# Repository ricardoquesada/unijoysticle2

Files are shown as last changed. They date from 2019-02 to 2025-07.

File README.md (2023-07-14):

# Unijoysticle™ 2





Unijoysticle is a device that allows you to use modern Bluetooth gamepads and mice in retro computers.

Unijoysticle 2 models:

| | 800XL | C64 | A500 | 2+ | 2 |
| --- | --- | --- | --- | --- | --- |
| Top | uni2800xl_photo_front | uni2c64_photo_front | uni2a500_photo_front | uni2plus_photo_front | uni2_photo_front |
| Bottom | uni2800xl_photo_back | uni2c64_photo_back | uni2a500_photo_back | uni2plus_photo_back | uni2_photo_back |
| Release date | July 2023 | March 2023 | July 2022 | October 2021 | April 2019 |
| Best for | Atari 800XL / 600XL | C64 / C128 | Amiga | - | - |
| Good for | Atari 400 / Amiga / AtariST | Amiga / AtariST | C64 / AtariST / Atari 8bit  | C64 / Amiga / AtariST / Atari 8bit | C64 / Amiga / AtariST / Atari 8bit |
| Status | Active / Supported | Active / Supported | Active / Supported | Discontinued / Supported | Discontinued / Supported |
| Amiga / AtariST mouse support | Yes | No | Yes | Yes | Yes |
| Amiga / AtariST 2nd & 3rd button support | No | No | Yes | Yes | Only in Port 1 |
| Atari 8-bit 2nd & 3rd button support (5) | Yes | No | No | No | No |
| C64 2nd & 3rd button support | No | Yes | No | No | No |
| C64 4th and 5th button support (4) | No | Yes | No | No | No |
| C64 Paddle support | No | Might (1) | No | No | No |
| Rumble (2) | No | Yes | No | No | No |
| Fits | 800XL / 600XL | C64 / C128 | Amiga 500 / 1200 | C64 / C128 | C64 / C128 |
| Buttons | Reset, Mode, Swap | Reset, Mode, Swap | Reset, Mode,  Swap | Reset, Mode | Reset, Mode |
| LEDs | Port 1, 2, Bluetooth, Power | Port 1, 2, Bluetooth, Power | Port 1, 2, Bluetooth, Power | Port 1, 2, Power | Port 1, 2, Power |
| Filter noise ([Issue #17][issue_17]) | Yes | Yes | Yes | Yes | No |
| Case friendly | Yes | Yes | Yes | Yes | No |
| Easy to solder | No. Most components are SMD | No. Most components are SMD | No. Most components are SMD | No. Most components are SMD | Yes. All components are through-hole  |
| Self-powered | Yes | Yes | Yes | Yes | Yes, can be turned on/off with switch |
| External power | USB | USB | USB | USB | Both USB and Barrel Jack 5V+ |
| Total Size (mm) | 65 x 75 x 13.6 | 72 x 68 x 13.6 | 67 x 72 x 13.6 | 64 x 64 x 13.6 | 63 x 66 x 17 |
| PCB Size (mm) | 53 x 72 x 1.6 | 63 x 60 x 1.6 | 52 x 67 x 1.6 | 49 x 62 x 1.6 | 46 x 57 x 1.6 |
| Weight (gr) | 27 | 27.1 | 25.6 | 24 | 37 |
| Current (mA) | ~96 | ~96 | ~96 | ~96 | ~100 |
| USB connector | Micro USB | Micro USB | Micro USB | Micro USB | Micro USB |

Notes:

- (1): Hardware physically connected, but firmware is still WIP.
- (2): Some C64 games can turn on/off rumble on gamepads. See: [Rambo], and [Lemans] ([video][rumble_video])
- (3): Right and Middle mouse buttons not supported in C64.
- (4): Based on [CrystalCT 5 buttons joystick][crystalct/5plusbuttonsJoystick] ([video][5_buttons_video])
- (5): Based on [Ascrnet Joy 2B+][atari_joy2bplus]

Unijoysticle 2 allows you to use modern Bluetooth gamepads. E.g. DualSense controller in retro computers like the Commodore 64, Amiga and AtariST.

It also supports mice (for Amiga / AtariST only).

[issue_17]: https://gitlab.com/ricardoquesada/unijoysticle2/-/issues/17
[uni2_photo_front]: https://lh3.googleusercontent.com/pw/AM-JKLUphquTBg9JoV-L7wuMtze_aKIJ8LvfokTakuBKSVFClziLWCViggcrlNZtqGUMgv6u6yYpZ_RuE2jdGSn3Q0oYl0jOQzzGcutRt-JiMjLZY_oAvK4LehrawNj_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
[uni2_photo_back]: https://lh3.googleusercontent.com/pw/AM-JKLXnMbJt7A55lUrtmiuKj4As98He7ZVi6YuPKg8N1sGbw1w5d5TtC8B-ilfoqC5QCKcZG8MFkmHNj5HgVbP8fdHhMBPx2CLgyRhaRmohx0SWF-_wZ57WYCfo7RlH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
[uni2plus_photo_front]: https://lh3.googleusercontent.com/pw/AM-JKLWV2Zo912VtOfuM71AluanNXGwVQiAehNEiQ1VL3L7SkWDl-9k0fA6tfza9QpGL52petBfFFFHMb8rh_ybSj17LOQA70IycMDQw6AVqlN8Jp4HDWT8sWcXHIPEQ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
[uni2plus_photo_back]: https://lh3.googleusercontent.com/pw/AM-JKLWs_G63eJRX8WuVVRoKKur8UQ-VcWTNbmkjFumwZYvDRhgjqamVa-X9CROAnoPyK3sHDmfwtqAtJiI1DHiwlINBPCgiEY4yWFYWl8SlHA_QOG7LmVKuOKy1UQa-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
[uni2a500_photo_front]: https://lh3.googleusercontent.com/pw/AM-JKLU1BbKnbuLE7Oa_VOY3AnBjYwNVcAPKJcmYa7WUnCK5gMM1bHZyK3lTZ1Mo0NtS30ogeeSqxySx3Qi2ux3AGOlocQnQe9a87NoiKz5tnmHV_IGf3hPln0qsr8t5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
[uni2a500_photo_back]: https://lh3.googleusercontent.com/pw/AM-JKLXMUngI6ctahY5clP-76UBjUem9L4Eehj4GFsEwUJwtZ3-MuZCV2nOsxiN3Go1PKvoc9sJbLRY8hCZ9TcV4cq5AtcAtscdjH1LiNzltFSgQY4IQEwSiPHfvhjhZ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
[bluepad32-fw]: https://gitlab.com/ricardoquesada/bluepad32
[uni2c64_photo_front]: https://lh3.googleusercontent.com/pw/AMWts8AzoDnIOIiM-50UpjAqY8OgdsM6pzM3BuYWb2ZOg4K_o4TxygtSjuZvrKI92lrl4Qqf8sLT6PtLYsXzDbragTDgoeX4yTpymqoc450FiyjiBT1YHxRbLBtGWgUO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
[uni2c64_photo_back]: https://lh3.googleusercontent.com/pw/AMWts8C_vxauz3FAOv8NGAh64LGTExHwCj0N0bX73xsWIeDyR3efFPPUQb3JJQK5S8Qcm9B8bx3r_yio6WWAML1si4u8E9FejXP9DL8vxSCg_TR7rLi5aPiwisQaIptN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
[uni2800xl_photo_front]: https://lh3.googleusercontent.com/pw/AIL4fc9fcgdY3Gka6iSZmyUlBTA1Q9ABujo-9v_4qE85St2GdW-2TBzzLNx-pc25o0rFloL0ghWZDDVW_kGWpQjcXaP-SJf9NWPnNw-2jpc_8tcVKp8gzLH7fxnFd7DB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
[uni2800xl_photo_back]: https://lh3.googleusercontent.com/pw/AIL4fc9PNSKKiA7PHsUTLKXGF1O9ywK-qLHS0nw2-Y6FxWQcgmtZJjajQh9Uch0aqZ2Pw-grH_Vg05IKYZilissF6nxUJPDszew0ouzGu91golm1RYJJpPS0CDANAfk3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
[Rambo]: https://gitlab.com/ricardoquesada/c64-rambo
[Lemans]: https://gitlab.com/ricardoquesada/c64-lemans
[crystalct/5plusbuttonsJoystick]: https://github.com/crystalct/5plusbuttonsJoystick/
[5_buttons_video]: https://www.youtube.com/watch?v=9Em_kUAHEuA
[rumble_video]: https://www.youtube.com/watch?v=vCj45OX43JE
[atari_joy2bplus]: https://github.com/ascrnet/Joy2Bplus
[uni_logo]: https://lh3.googleusercontent.com/pw/AIL4fc_k4CtBs9deXjMuCJOotXbNoRwON1CdYCMshG41PpEf2v-7xc2IcIPFvYCOFeLriESlXEJhm5nK72st8v1E04ZzyqawW8x5DPJt2ug6ZzhGXdnJvasD577CX1Yb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

## Basic functionality

One Bluetooth gamepad controls one joystick.
You need two gamepads to control the two joysticks.

Basic mode

The mappings are:

- D-pad/joypad: controls up/down/left/right.
- Button A / Cross: fire button
- Button B / Circle: "up"  (ideal for platform games).
- Button X / Square: 2nd button (Amiga / AtariST only)
- Button Y / Triangle: 3rd button (Amiga / AtariST only)
- Button shoulder-right: autofire.
- System button swaps between Joystick 1 and 2

## Twin Stick functionality (AKA Enhanced mode)

Twin Stick mode

When in "Enhanced mode", you control the two joysticks with only one gamepad.
The mappings are:

- Left joypad / d-pad: control Joystick 2 movements.
- Right joypad: control Joystick 1 movements.
- Button A / Cross: fire for Joystick 2
- Button B / Circle: fire for Joystick 1
- Button X / Square: 2nd button for Joystick 2
- Button Y / Triangle: 2nd button for Joystick 1
- Button Shoulder Left: auto-fire for Joystick 2
- Button Shoulder Right: auto-fire for Joystick 1

This mode is ideal for games like [Commando][2] or [1942][3] since it allows you
throw grenades / roll by pressing Button B.

## Supported controllers

### Gamepads
Supported gamepads

- Sony DualSense
- Sony DUALSHOCK 4
- Sony DUALSHOCK 3
- Nintendo Switch Pro
- Nintendo JoyCons
- Nintendo Wii U
- Nintendo Wii + accesories
- Xbox Wireless controller (model 1708)
- Steam
- Stadia
- Android gamepads
- PC/Windows gamepads
- 8BitDo controllers
- iCade
- And more

See:

* [Supported gamepads][gamepads]
* [Supported mice][mice]

[gamepads]: https://gitlab.com/ricardoquesada/unijoysticle2/blob/master/docs/supported_gamepads.md
[mice]: https://gitlab.com/ricardoquesada/bluepad32/blob/develop/docs/supported_mice.md

### Mice

Supported mice

Mouse emulation is only available for **Amiga and Atari ST** computers.

For a detailed list of supported mice, see here:

* [Supported mice][supported_mice]

[supported_mice]:  https://gitlab.com/ricardoquesada/bluepad32/blob/develop/docs/supported_mice.md

## Order info

If you are looking for ready-to-use boards, you can purchase one from here:



Looking for a remix and/or 3rd party vendors. Go here: [SELLING_DEVICES.md][selling_devices]

[selling_devices]: SELLING_DEVICES.md

## More Info

- [Users guide][users_guide]
- [Discord][discord]
- [Email group][email_group]

[users_guide]: https://gitlab.com/ricardoquesada/unijoysticle2/blob/master/docs/user_guide.md
[discord]: https://discord.gg/r5aMn6Cw5q
[email_group]: https://groups.google.com/forum/#!forum/unijoysticle

[1]: https://retro.moe/unijoysticle
[2]: https://csdb.dk/release/?id=137173
[3]: https://csdb.dk/release/?id=38140

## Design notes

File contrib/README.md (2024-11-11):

Contributions by the community.

Kopsec C64:
 - c64/ Unijoysticle 2 - REV E / REV H
 - c64/ Unijoysticle 2 - Rev A1, based on new Unijoysticle C64 model

Eduardo Casino:
 - C16/Plus4 board

Hyvax:
  - NeoGeo board

Aakko:
  - Case for Unijosyticle 2+

Goblin Hero:
  - Case for Unijoysticle 2 A500

Albert Herranz:
  - MSX boards
    * [msx-joyblue-v1](https://github.com/herraa1/msx-joyblue-v1)
    * [msx-joyblue-v2](https://github.com/herraa1/msx-joyblue-v2)

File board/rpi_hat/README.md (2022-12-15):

# Unijoysticle 2 Test HAT

A Raspeberry Pi HAT for Unijoysticle automated testing.

* Board files are in this folder.
* Tests are in https://gitlab.com/ricardoquesada/unijoysticle2/-/tree/main/tests/functional

full

pcb

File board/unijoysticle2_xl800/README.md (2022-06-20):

# Unijoysticle™ 2 A500

uni2_a500_photo

Unijoysticle 2 A500 is device that lets you use modern Gamepad and Mice in retro computers like the Amiga.

Unijoysticle 2 is open source / open hardware. See [license][license] for details.

[uni2_a500_photo]: https://lh3.googleusercontent.com/pw/AM-JKLXEB6NQ-lr54G6cPEVQJ9i1OGR0XWLVYsjCs4Sc_883w-gYvwnUOPlH2wnzM0ibH48Y6QGAAIRO9pnfTxDsdQqY7JHBKzJPzOOY8Cin6t9sSjHvx94k1VZLdTh1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 

## Schematic

* [Unijoysticle 2 A500 schematic](../../docs/schematic_unijoysticle2_a500.pdf)

## Layout

Layout files are in Kicad 6 format in this same folder.

## BOM

| Item | Qty | Reference(s) | Value | LibPart | Footprint | Datasheet |
| ---- | --- | --- | ----- | --- | --- | --- |
| 1 |7|C1,C2,C4,C9,C11,C12,C13|.1uF|Device:C_Small|Capacitor_SMD:C_0805_2012Metric_Pad1.18x1.45mm_HandSolder|~|
| 2 |1|C3|10uF|Device:C_Small|Capacitor_SMD:C_0805_2012Metric_Pad1.18x1.45mm_HandSolder|~|
| 3 |3|C5, C7, C8 |22uF|Device:C_Small|Capacitor_SMD:C_0805_2012Metric_Pad1.18x1.45mm_HandSolder|~|
| 4 |1|C6|1500uF|Device:C_Polarized_Small|Capacitor_SMD:CP_Elec_10x10|~|
| 5 |1|C10|1uF|Device:C_Small|Capacitor_SMD:C_0805_2012Metric_Pad1.18x1.45mm_HandSolder|~|
| 6 |1|D1|PWR|Device:LED|LED_SMD:LED_0805_2012Metric_Pad1.15x1.40mm_HandSolder|~|
| 7 |2|D2, D3|1N5819|Device:D_Schottky_Small|Diode_SMD:D_SOD-123|~|
| 8 |1|D4|BLUE|Device:LED|LED_SMD:LED_0805_2012Metric_Pad1.15x1.40mm_HandSolder|~|
| 9 |1|D5|GREEN|Device:LED|LED_SMD:LED_0805_2012Metric_Pad1.15x1.40mm_HandSolder|~|
| 10 |1|D6|RED|Device:LED|LED_SMD:LED_0805_2012Metric_Pad1.15x1.40mm_HandSolder|~|
| 11 |2|H1, H2|MountingHole_Pad|Mechanical:MountingHole_Pad|MountingHole:MountingHole_3.2mm_M3_Pad_Via|~|
| 12 |1|J1|USB_B_Micro|Connector:USB_B_Micro|Connector_USB:USB_Micro-B_Amphenol_10118194_Horizontal|~|
| 13 |1|J2|PORT JOY #1|Connector:DB9_Female|Connector_Dsub:DSUB-9_Female_Horizontal_P2.77x2.54mm_EdgePinOffset9.40mm| ~ |
| 14 |1|J3|PORT JOY #2|Connector:DB9_Female|Connector_Dsub:DSUB-9_Female_Horizontal_P2.77x2.54mm_EdgePinOffset9.40mm| ~ |
| 15 |1|JP1|SolderJumper_1_Open, Jumper:SolderJumper_2_Open|Jumper:SolderJumper-2_P1.3mm_Open_Pad1.0x1.5mm| ~ |
| 16 |2|Q1, Q2|S8050|Device:Q_NPN_BEC|Package_TO_SOT_SMD:SOT-23| ~ |
| 17 |3|R1, R10, R11|10K|Device:R|Resistor_SMD:R_0805_2012Metric_Pad1.20x1.40mm_HandSolder| ~ |
| 18 |5|R2, R7, R8, R9, R12|3.3K|Device:R|Resistor_SMD:R_0805_2012Metric_Pad1.20x1.40mm_HandSolder| ~ |
| 19 |2|R3, R4|10K|Device:R_Small|Resistor_SMD:R_0805_2012Metric_Pad1.20x1.40mm_HandSolder| ~ |
| 20 |2|R5, R6|1K|Device:R_Small|Resistor_SMD:R_0805_2012Metric_Pad1.20x1.40mm_HandSolder| ~ |
| 21 |3|R13, R14, R15|0|Device:R|Resistor_SMD:R_0805_2012Metric_Pad1.20x1.40mm_HandSolder| ~ |
| 22 |1|SW1|RESET|Switch:SW_Push|Button_Switch_THT:SW_Tactile_SPST_Angled_PTS645Vx39-2LFS| ~ |
| 23 |1|SW2|BOOT|Switch:SW_Push|Unijoysticle:SW_Push_1P1T_NO_5.1x5.1mm| ~ |
| 24 |1|SW3|MODE|Switch:SW_Push|Button_Switch_THT:SW_Tactile_SPST_Angled_PTS645Vx39-2LFS| ~ |
| 25 |1|SW4|SWAP|Switch:SW_Push|Button_Switch_THT:SW_Tactile_SPST_Angled_PTS645Vx39-2LFS| ~ |
| 26 |1|U1|ESP32-WROOM-32E|RF_Module:ESP32-WROOM-32D|RF_Module:ESP32-WROOM-32 | https://www.espressif.com/sites/default/files/documentation/esp32-wroom-32d_esp32-wroom-32u_datasheet_en.pdf |
| 27 |1|U2|AMS1117-3.3|Regulator_Linear:AMS1117-3.3|Package_TO_SOT_SMD:SOT-223-3_TabPin2|http://www.advanced-monolithic.com/pdf/ds1117.pdf |
| 28 |1|U3|CH340C|Interface_USB:CH340C|Package_SO:SOIC-16_3.9x9.9mm_P1.27mm|https://datasheet.lcsc.com/szlcsc/Jiangsu-Qin-Heng-CH340C_C84681.pdf |
| 29 |3| U4, U5, U6|74HC05|74xx:74LS05|Package_SO:SOIC-14_3.9x8.7mm_P1.27mm|http://www.ti.com/lit/gpn/sn74LS05 |

## Order info

If you are looking for ready-to-use boards, you can purchase one from here:



[license]: ../../LICENSE

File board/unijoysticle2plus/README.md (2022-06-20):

# Unijoysticle™ 2+

uni2_plus_photo

Unijoysticle 2+ is device that lets you use modern gamepads and Mice in retro computers like the Commodore 64.

Unijoysticle 2 is open source / open hardware. See [license][license] for details.

[uni2_plus_photo]: https://lh3.googleusercontent.com/pw/AM-JKLVeTZLBOCy4GmrG5N-WiRIcqoxLdsVXSN-77reS92gn7xxmZy-JuE_XeXgwSSPaUBYa2qaaw5RvZbzlkHdjDxal2p_WkKIm9RnzD6qeqV_u7j_3sRJOkm35EO5J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

## Schematic

* [Unijoysticle 2+ schematic](../../docs/schematic_unijoysticle2plus.pdf)

## Layout

Layout files are in Kicad 5 format in this same folder.

## BOM

| Item | Qty | Reference(s) | Value | LibPart | Footprint | Datasheet |
| ---- | --- | --- | ----- | --- | --- | --- |
|1|7|C1, C2, C3, C5, C11, C12, C13|.1uF|Device:C_Small|Capacitor_SMD:C_0805_2012Metric_Pad1.18x1.45mm_HandSolder|~|
|2|1|C4|10uF|Device:C_Small|Capacitor_SMD:C_0805_2012Metric_Pad1.18x1.45mm_HandSolder|~|
|3|3|C6, C8, C9|22uF|Device:C_Small|Capacitor_SMD:C_0805_2012Metric_Pad1.18x1.45mm_HandSolder|~|
|4|1|C7|1000uF|unijoysticle2plus-rescue:CP_Small-Device|Capacitor_SMD:CP_Elec_10x10||
|5|1|C10|1uF|Device:C_Small|Capacitor_SMD:C_0805_2012Metric_Pad1.18x1.45mm_HandSolder|~|
|6|1|D1|BLUE|Device:LED|LED_SMD:LED_0805_2012Metric_Pad1.15x1.40mm_HandSolder|~|
|7|1|D2|GREEN|Device:LED|LED_SMD:LED_0805_2012Metric_Pad1.15x1.40mm_HandSolder|~|
|8|1|D3|RED|Device:LED|LED_SMD:LED_0805_2012Metric_Pad1.15x1.40mm_HandSolder|~|
|9|2|D4, D5|1N5819|Device:D_Schottky_Small|Diode_SMD:D_SOD-123|~|
|10|2|H1, H2|MountingHole_Pad|Mechanical:MountingHole_Pad|MountingHole:MountingHole_3.2mm_M3_Pad_Via|~|
|11|2|J1, J2|DB9_Female|Connector:DB9_Female|Connector_Dsub:DSUB-9_Female_Horizontal_P2.77x2.54mm_EdgePinOffset9.40mm| ~|
|12|1|J3|USB_B_Micro|Connector:USB_B_Micro|Connector_USB:USB_Micro-B_Amphenol_10118194_Horizontal|~|
|13|2|Q1, Q2|S8050|Device:Q_NPN_BEC|Package_TO_SOT_SMD:SOT-23|~|
|14|1|R1|10k|Device:R|Resistor_SMD:R_0805_2012Metric_Pad1.20x1.40mm_HandSolder|~|
|15|3|R2, R3, R4|1.5k|Device:R|Resistor_SMD:R_0805_2012Metric_Pad1.20x1.40mm_HandSolder|~|
|16|2|R5, R6|1k|Device:R_Small|Resistor_SMD:R_0805_2012Metric_Pad1.20x1.40mm_HandSolder|~|
|17|2|R7, R8|10k|Device:R_Small|Resistor_SMD:R_0805_2012Metric_Pad1.20x1.40mm_HandSolder|~|
|18|1|SW1|RESET|Switch:SW_Push|Button_Switch_THT:SW_Tactile_SPST_Angled_PTS645Vx39-2LFS|~|
|19|1|SW2|JOY SWAP|Switch:SW_Push|Button_Switch_THT:SW_Tactile_SPST_Angled_PTS645Vx39-2LFS|~|
|20|1|SW3|BOOT|Switch:SW_Push|Unijoysticle:SW_Push_1P1T_NO_5.1x5.1mm|~|
|21|3|U1, U2, U3|74HC05|74xx:74LS05|Package_SO:SOIC-14_3.9x8.7mm_P1.27mm|http://www.ti.com/lit/gpn/sn74LS05|
|22|1|U4|ESP32-WROOM-32E|RF_Module:ESP32-WROOM-32D|RF_Module:ESP32-WROOM-32|https://www.espressif.com/sites/default/files/documentation/esp32-wroom-32d_esp32-wroom-32u_datasheet_en.pdf|
|23|1|U5|AMS1117-3.3|Regulator_Linear:AMS1117-3.3|Package_TO_SOT_SMD:SOT-223-3_TabPin2|http://www.advanced-monolithic.com/pdf/ds1117.pdf|
|24|1|U6|CH340C|Interface_USB:CH340C|Package_SO:SOIC-16_3.9x9.9mm_P1.27mm|https://datasheet.lcsc.com/szlcsc/Jiangsu-Qin-Heng-CH340C_C84681.pdf|

## Order info

If you are looking for ready-to-use boards, you can purchase one from here:



[license]: ../../LICENSE

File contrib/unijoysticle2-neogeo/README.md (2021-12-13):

# Unijoysticle2 for NeoGeo

## Projects

### Unijoysticle2 for NeoGeo

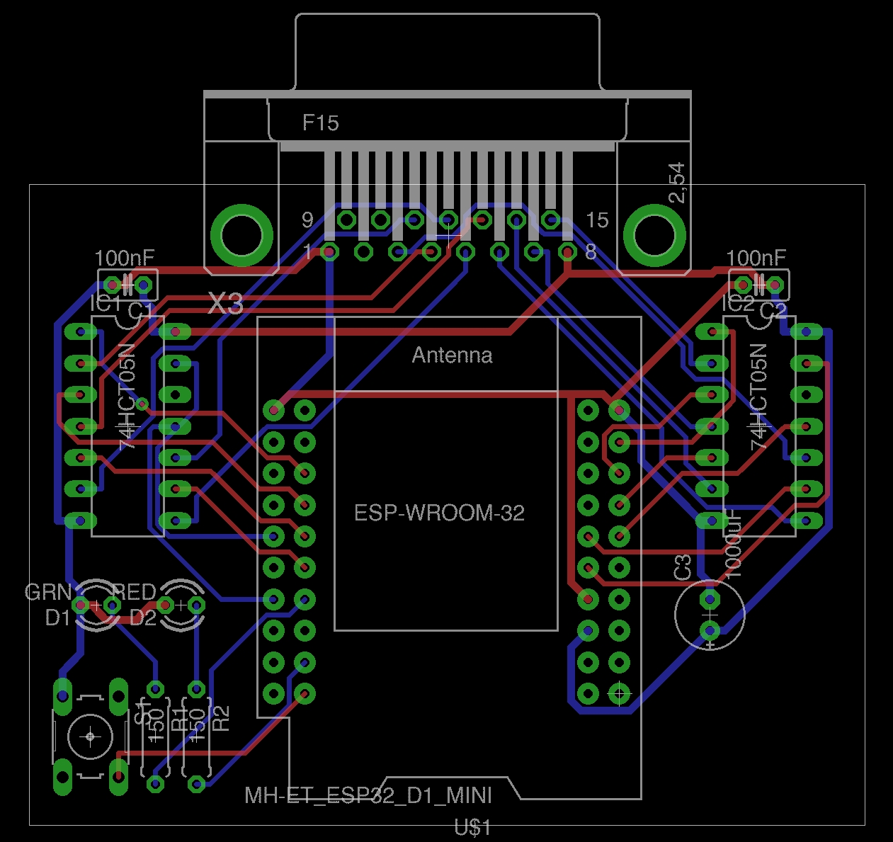
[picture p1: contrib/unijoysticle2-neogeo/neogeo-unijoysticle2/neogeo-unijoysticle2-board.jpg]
uni-neogeo


Includes PCB & schematic (Eagle CAD 6.5.0): Unijoysticle2 NeoGeo version - with DB15 connector.

### Unijoysticle2 Adapter for NeoGeo

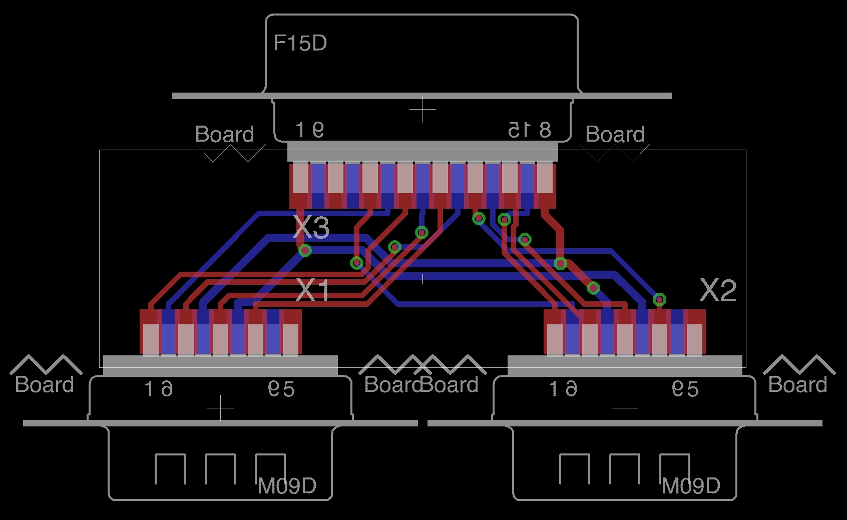
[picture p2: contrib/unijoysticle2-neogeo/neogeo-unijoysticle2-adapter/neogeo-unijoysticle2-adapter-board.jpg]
uni-neogeo-adapter


Includes PCB & schematic (Eagle CAD 6.5.0): Adapter for Unijoysticle2 - 2x DB9 -> DB15

## NeoGeo pinout

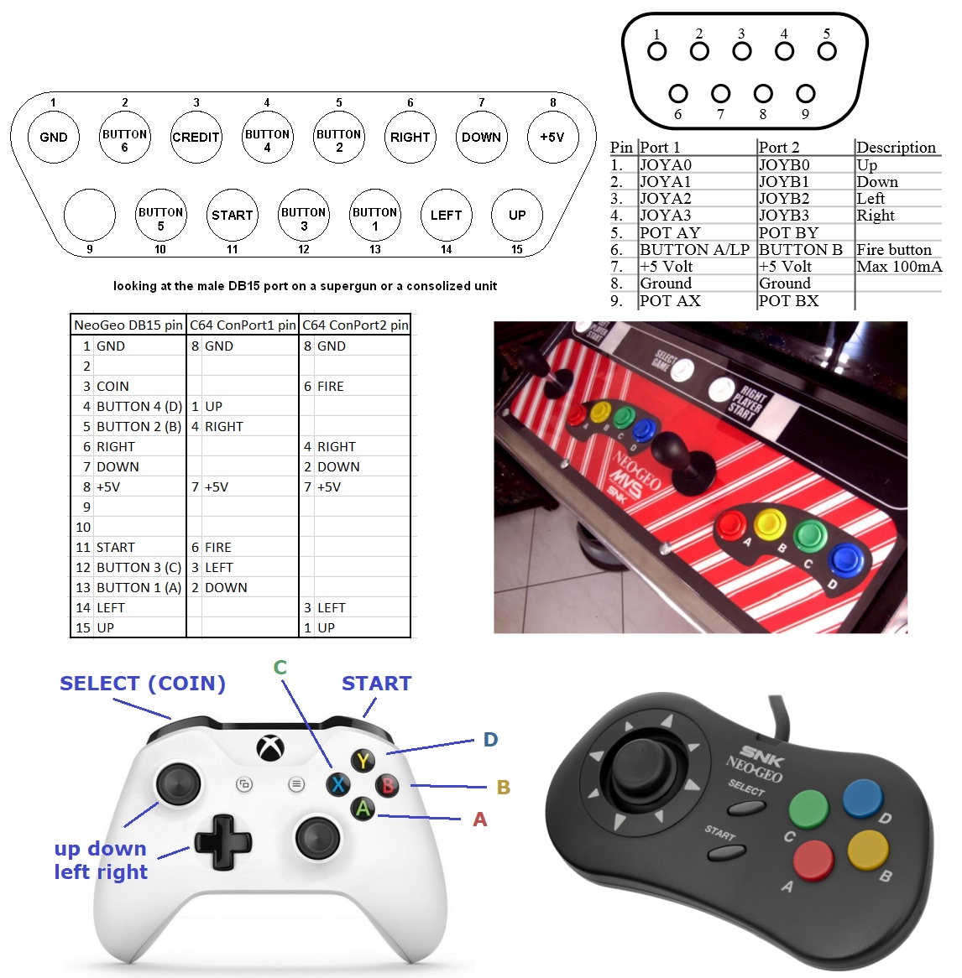
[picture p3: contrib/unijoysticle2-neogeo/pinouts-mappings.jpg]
pinout


- NeoGeo DB15 pinout reference
- C64 control port pinout reference
- table describing how corresponding pins are connected
- gamepad button mappings, NeoGeo and MVS controller for reference

## Mappings

Replace file `uni_joystick.c` in in Bluepad32 source code and compile it using `unijoysticle` as `PLATFORM`.

## Additional notes

- neogeo-unijoysticle2 is supposed to be ONLY used as self powered - do not plug in usb power simultaneously, there are no protection diodes (add em if You wish)
- before exporting to gerber all traces on board files should be further optimized, can be traced better/prettier
- description layers should be cleaned up and aligned
- board dimensions should be further adjusted
- uni_joystick.c is still from the version before "enhanced mode bug fix" so J2 = J1
- ment to be used in enhanced mode only, of course, due to 10 controller inputs are required - there is no point in using it in basic mode
- tested 11.12.2021 and working fine with NeoGeo MVS MV1A - should of course work as well with other MVS boards and AES
- keep in mind some MVS supergun's may have DB15 connectors upside down - mirror DB15 connector on the adapter or standalone pcb before making gerbers, otherwise (due to esp32 sticking up out of the pcb) there may be issues plugging in adapter or standalone pcb to Your MVS or AES
- solder cup DB15/DB9 connector or THT connectors may be used - alter board files according to Your preferences

## Author

Hyvax

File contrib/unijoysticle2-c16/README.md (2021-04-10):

# C16/Plus4 board

This board is specifically designed for the TED series of Commodore computers (c16, c116 and Plus/4) and it is based on the work of [Levente Hársfalvi](https://www.commodore.ca/manuals/funet/cbm/documents/projects/interfaces/plus4joy/plus4joy.html)

It uses the same firmware as the C64 version and works exactly the same, except for two particularities:

- Joystick \#1 and \#2 are swapped (default joystick in c16 games is usually \#1)
- The board can be self-powered or USB-powered, there is no barrel jack

## Important

Board **must** be 1mm thick or the mini DIN connectors won't fit!

## Bill Of Materials

- 10 x 110ohm, 1/4W resistors (100ohm is also OK)
- 2 x 150ohm, 1/4W resistors
- 3 x 100nF ceramic capacitors
- 1 x 220uF 16V, low ESR, electrolytic capacitor
- 1 x 3mm red LED
- 1 x 3mm green LED
- 1 x 1n5819 Schottky diode
- 1 x SPST right angle, 6x6x5mm push button
- 2 x 20pin DIP sockets
- 2 x 74HCT240 buffers with inverted outputs
- 2 x [Mini DIN male connectors](https://es.aliexpress.com/item/4001071580837.html)
- 2 x 2x10 PIN double row, straight, female header
- 1 x ESP32 Mini Kit
- 1 x [Unijoysticle2-c16 board](https://www.pcbway.com/project/shareproject/Unijoysticle_2_for_Commodore_TED_series_of_computers__c16__c116_and_Plus_4__1.html)

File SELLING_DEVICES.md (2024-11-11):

# Getting a Unijoysticle device

## Official store

I sell the Unijoysticle on Tindie. If you can purchase it from my Tindie store, great! It helps funding the project.

| Product | Image |
| --- | ----- |
| Unijoysticle 2+<br> |  |

## Remix and 3rd party vendors

You can also get Unijoysticle-like device from these other makers / vendors:

| Product | Image |
| --- | ----- |
| Vendor: Kopsec <br>Description: For C64, already assembled + case<br>Price: Commercial<br>Further info: [Ebay store][kopsec_store] |   |
| Vendor: Kopsec <br>Description: For C64, already assembled + case<br>Price: Commercial<br>Further info: [Ebay store][kopsec_store_2] |   |
| Vendor: Arananet<br>Description: Single joystick version, ideal for Amiga<br>Price: Commercial<br>Further info: [Unijoy2Amiga][arananet_store] |  |
| Vendor: Eduardo Casino<br>Description: For the Commodore 16 & Plus/4<br>Price: [Contact author for availability][casino_contact]<br>Further info: [PCBWay page][casino_store] |  |
| Vendor: SukkoPera<br>Description: Fits in the Amiga 500<br>Price: Free, DIY<br>Further info: [Project page][sukkopera_store] <br> |  |
| Vendor: Hyvax<br>Description: For NeoGeo<br>Price: Free, DIY<br>Further info: [Project page][hyvax_store] |  |
| Vendor: CBMRetro<br>Description: For the C64, with case<br>Price: Commercial<br>Further info:[CBMRetro][cbmretro_store] |  |
| Vendor: Albert Herranz<br>Description: For the MSX, with optional acrylic case<br>Price: Free, DIY<br>Further info: [Project page][herraa1_store] <br> |  |

[kopsec_store]: https://www.ebay.es/itm/Unijoysticle-2-in-case-Use-modern-Bluetooth-gamepads-in-your-Commodore-64-128-/233557376702
[kopsec_image]: https://lh3.googleusercontent.com/pw/ACtC-3c3XC07S03WVHKnlZhrbDd7g9YkG5QHW35Gv-PgX62odPKok5A56Jc3drYu_W2yBhXJ1k_8Qs5S2I1sKtcqXm_IgPiof5d-7Ztjrj_EIfTfWidgIg9KifyYBrLJ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
[kopsec_store_2]: https://www.ebay.es/itm/233604333629
[kopsec_image_2]: https://lh3.googleusercontent.com/pw/AM-JKLVrpAojqCiWSkTNUB5eoIpwqwBYiJoVIrUoYUF-AdfGDXaBMCN6D88mDG2xQLi3iXRD1v_9iStIxBxhHoT7EmrvMS-lTvlOMxmksSDtOuEcffDZZVzxIo4XMyD4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
[arananet_store]: https://www.arananet.net/pedidos/product/unijoy2amiga-db9-to-bluetooth-adapter-for-amiga
[arananet_image]: https://lh3.googleusercontent.com/pw/ACtC-3c9fxhjTgrKxflOyt39B3czHvLyBthrH7tFVWgUPfYTpQF_kaiuQ4wD4eUnSknf4_GLummIaJBroMAi5l4rZbXd_M0exZCglngv4BroeP6ua4UJhe1xYUWoXCNo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
[casino_store]: https://www.pcbway.com/project/shareproject/Unijoysticle_2_for_Commodore_TED_series_of_computers__c16__c116_and_Plus_4__1.html
[casino_contact]: mail@eduardocasino.es
[casino_image]: https://lh3.googleusercontent.com/pw/AM-JKLXPLQvMdhgu51A-oNVx3er65vPHsRPHEq6PqQ67yw8JKU62-fL2edlPtO8bYyDLLjJ3AmiMQtdNzosb1_HpnLdNwqNum988Xo99m7AEIyUaFe1tXoQl8J0HKNz4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
[sukkopera_store]: https://gitlab.com/SukkoPera/unijoysticle2
[sukkopera_image]: https://lh3.googleusercontent.com/pw/AM-JKLXelHShcrWyNvOgKNv2yxMaGUA45378q-8cOzLABXbgeAnSG2svXBY2hY7XcggGakgsmkfHVzUiVopgxK730Z6VTPI1sFnK-trwQGrpejReA-jO7K1DtrZ7wxbf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
[hyvax_store]: https://gitlab.com/ricardoquesada/unijoysticle2/-/tree/main/contrib/unijoysticle2-neogeo
[hyvax_image]: https://lh3.googleusercontent.com/pw/AM-JKLUoGfsqpTawu8hHNKW7fS_aZSv0JAx0VG82fqxsmhryK5XkRFE5g9dNY9QJgMAVyVyg_bjyClJHQ7zlahdeSEVSyDnlK2BBPZ-eCefoBb2Ttzut3vnSTUPMoKho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
[cbmretro_store]: https://cbmretro.fi/product/bluetooth-controller-adapter/
[cbmretro_image]: https://lh3.googleusercontent.com/pw/AM-JKLVdFl9R70hd7A9zvulx5vRModyWT6h1j7CjL_m5m72dsKSNOU2gV44EL9KVvziwdt6mwo2y91wzan6BKhsql0ZbWUPoP3ZXOTLojcKsjJrCVjpFnQK7iJ1JXyjI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
[herraa1_store]: https://github.com/herraa1/msx-joyblue-v2
[herraa1_image]: https://raw.githubusercontent.com/herraa1/msx-joyblue-v2/main/images/msx-joyblue-v2-build2b-front-render-350w.png

Did you create a remix? Are you selling Unijoysticle-like devices? Send a Pull-request and add yourself to this page! (See below)

## Notice for 3rd party vendors

TL;DR: if you are selling Unijoysticle devices, don't call them "Unijoysticle" [*].

In the same spirit as the Arduino or Adafruit philosophy of Open Hardware,
you are allowed to remix the Unijoysticle, and/or create your own boards, and/or sell
them if you want.

But you cannot sell them under the "Unijoysticle" name. Just choose your own name.
E.g: you can clone the Arduino or Adafruit boards, but you cannot sell them
as if they were original Arduino or Adafruit boards.

It is precisely for this reason that, since the early beginnings of the project:

* I chose the [Solderpad Hardware License][license],
  which allows you to do almost whatever you want. But it doesn't transfer you
  the Trademark. The trademark is mine.

* Unijoysticle is a trademark, as I established [here][uni1_tm] and [here][uni2_tm].

[*]: The only exception is [KOPSEC64][kopsec64], whom I expressly authorized him to sell
     them using the Unijoysticle name.

[license]: http://solderpad.org/licenses/SHL-2.0/
[uni1_tm]: https://retro.moe/unijoysticle/
[uni2_tm]: https://retro.moe/unijoysticle2/
[kopsec64]: https://www.ebay.com/usr/cespok_64?_trksid=p2047675.m3561.l2559

### Rationale

I love retro-stores, and I believe the retro-stores play an important role within the retro-community.
But if you are selling Unijoysticle-like devices, just bear in mind that you cannot call them "Unijoysticle".
You must choose another name. In fact, I would be happy to promote your store and include it in the
list of "3rd party vendors" if you needed so.

Apart for the fact that Unijoysticle is my trademark, I have decided to keep the name to myself for these
additional reasons:

* Avoid confusion.
  I'm selling Unijoysticle devices. If someone else were to sell them, it would certainly
  create confusion.
* Support.
  I provide support for the Unijoysticle devices. Therefore, it needs to be clear which boards are made by me (the Unijoysticle devices) and which are not. I can only vouch for the boards that I have built myself.
* Quality. The boards that I'm selling are high quality. And I want people to associate "Unijoysticle" with a
  high quality product. I can only vouch for the quality of the devices I've made myself.
* Family of products: I plan to offer Unijoysticle devices for other computers other than the C64. Thus, for this reason,
  I have chosen to reserve the right to use the Unijoysticle name for whichever product I deem suitable in the future.

### Examples of valid names created by 3rd party vendors

* [Unijoy2Amiga][unijoy] sold by Arananet.

This example shouldn't be interpreted as encouraging to use this or any other name already being used by the community.
  
[unijoy]: https://www.arananet.net/pedidos/product/unijoy2amiga-db9-to-bluetooth-adapter-for-amiga

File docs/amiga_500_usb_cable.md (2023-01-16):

# How to build your own Amiga USB power cable

The Amiga 500 joystick ports don't have enough current to power Unijoysticle.

So, it must be powered from the USB port.

You can just connect a USB cable to the Unijoysticle and plug it in your computer. That works, but requires an "external" computer.

The alternative is to power the Unijoysticle from the Amiga external disk port.

## Building the cable



The Amiga 500 disk drive port can provide +5v @ 250mA. More than enough for the Unijoysticle neeeds, which only requires +5v @ 100mA.

Let's go over the steps:

[complete_cable]: https://lh3.googleusercontent.com/pw/AM-JKLX1h8BIZUTdIzU6P_mC6mPDTxCe9GQnnYKjc08f4ARav_fc8LyaSBGO6SvssALuR9QEA_GPan_OuojYyjrmxiI2_TKVjC0Y9oqzdwhxdJTVpmON_ItBKkc6M-kM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

[pinout]: https://old.pinouts.ru/HD/ExtDiskAmiga_pinout.shtml

### 1. Get a USB micro cable

You probably have already a few USB micro cables. Just get one and cut it so that the you have a 25 cm (~10 inches) long cable.

You will only need the Red (+5V) and Black (Ground) cables. Feel free to cut the other 2 cables.

### DB-23 connector

The drive port is a DB-23 female. So you need a DB-23 male connector.

Unfortunately the DB-23 male connectors are rather expensive since they are no longer being manufactured at scale.

If you don't mind paying premium, you can get them from these places:

* [Ebay][ebay]
* [IComp][icomp]
* [Amiga Store][amiga_store]
* ...or [just Google them][google]

[ebay]: https://www.ebay.com/itm/23-WAY-MALE-D-PLUG-DB23-CONNECTOR-FOR-COMMODORE-AMIGA-RARE-/390415565147?_ul=IN
[icomp]: https://icomp.de/shop-icomp/en/produkt-details/product/db23-male-connector.html
[amiga_store]: https://amigastore.eu/790-db23-male-connector.html
[google]: https://www.google.com/search?q=DB-23+male+connector&oq=db-23+male+connector

### Alternative: DB-25 connector

Or you can get a DB-25 male connector from multiple vendor:

* [Aliexpress][aliexpress]

And then remove the extra pins, and bend a bit the shield:

db25_without_pins

[aliexpress]: https://www.aliexpress.us/item/2251832655624766.html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
[db25_no_pins]: https://lh3.googleusercontent.com/pw/AL9nZEUfV8rRMBE8P6En2caIlgDeJMNkwIT1aN7swTMXvBx1reyQ19fGjeddPHy1q9Ka-0MnwCPwEynLb6bZZO9m3qNH_JTYUqFank33AgKXYHFHOR-uT4sBgsYyB-lL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

### Solder

And now get a soldering iron and solder:

```
USB +5v (red cable)   <---> Amiga Drive Port pin 12
USB GND (black cable) <---> Amiga Drive Port pin 3 (or 4, or 5 or 6 or 7... and are GNDs)
```

The complete pinout is here: [Amiga external drive pinout][pinout]

And it should look like this:

soldered

[soldered]: https://lh3.googleusercontent.com/pw/AL9nZEVJqSWg3jRuoEu66gHtM16H6VYkCUCaObHsAdmCjlbFFx4CG276pd-iMZVlrtooP63-sppP_1knTVFmUVzJNsj0pn1rfys5hGINAxZd2pApwRrDgATPQoVse7Y3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

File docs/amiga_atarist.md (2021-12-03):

# Amiga / Atari ST support

**OUTDATED INFO: Should include info about Unijoysticle 2+ that supports 2nd & 3rd
buttons on Amiga/AtariST on both ports using the same firmware**

The Unijoysticle 2 can be used in any "[Atari DB9 joystick][db9]"-compatible computer.
That includes the 8-bit Atari family, the Commodore C64/C128, as well as the
Amiga and Atari ST (among others).

The Unijoysticle 2 was designed to fit in the Commodore 64 / 128 computers. If you
want to use in any other computer will one (or two) DB9 extension [cables][cable].

The difference between the C64/C128/Atari-8bit family vs. the Amiga/Atari ST
is that the latter supports up to 2 or 3 joystick buttons, while the former only
supports 1 joystick button.

If you want to use the 3-buttons with the Unijoysticle you have to flash the
`amiga` firmware (despite its name it also suitable for the Atari ST).

If you only play Amiga/Atari ST games that require just one button, you can use the
`c64` firmware, and you can skip this documentation.
See the benefits/limitations below.

[db9]: http://wiki.icomp.de/wiki/DB9-Joystick
[cable]: https://www.aliexpress.com/item/33012270252.html?spm=a2g0s.9042311.0.0.74394c4diOD0iB

## 3-buttons firmware

Use this firmware if you plan to play games that require 2 or more joystick buttons.
Suitable for some Amiga/Atari ST games.

* Download firmware [0.5beta-1 or newer][firmware]
* Unzip it, and install the one that is in the `amiga` folder.
* Read the README.md that is in the `amiga` folder and follow the intructions.

[firmware]: https://github.com/ricardoquesada/unijoysticle2/releases

### Amiga family

Amiga

Tested on:

* Amiga 500 with default power supply: Unijoysticle **cannot** be self-powered (not enough current).
* Connect DB9-extension cable
  * to Unijoysticle port 1.
  * to the Amiga port 2 (games usually expect joystick on port 2)

### Atari ST family

AtariST

Tested on:

* Atari ST 1040F: Unijoysticle can be self-powered.
* Atari ST doesn't have a 3rd-joystick button, but it does a 2nd one.
  Use the "3-button firmware" to play games that use the 2nd button.
* Connect DB9-extension cable
  * to Unijoysticle port 1.
  * to the Atari ST port 2 (games usually expect joystick on port 2)

## Benefits / Limitation

The 3-buttons firmware has the following benefits / limitations:

* Supports the 3-joystick buttons (yay!). Suitable for certain Amiga/Atari ST games.
* But only one gamepad can be connected. That means:
  * Unijoysticle's `enhanced mode` cannot be activated.
  * Cannot use just one Unijoysticle to play games that requires two joysticks
    (it requires two Unijoysticles).

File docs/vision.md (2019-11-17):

# Unijosyticle v2

Modern bluetooth game controllers for retro computers.

Or any bluetooth powered device for the matter. And attach it to your unicycle and play games like a pro.

## Goal #1

**Enhance user-experience in retro computers by using modern bluetooth devices**.

*Enhance user-experinece* is a user-experience that is only possible by using modern devices. For example:

-  Gamepads are more ergonomic than joysticks from the 80's.
-  Gamepads have more buttons, and can be mapped to different options. eg: Button 'B' could be mapped to 'Jump'. Ideal in platform games.
-  Combo Joy+Joy: One gamepad could control 2 joysticks at the same time
-  Combo Mouse+Joy: One gamepad could be used as joystick + mouse (ideal for Atari ST / Amiga).
-  And of course, using a unicycle to connect to your retro computer so you can play "The Uni Games" properly.

*Modern bluetooth devices* includes, but not limited to:

-  Gamepads (iOS, Android, Xbox, PS4, Switch, etc.)
-  Smart TV remote controllers
-  Mice
-  Smartphones

*Retro computers* includes, but not limited to:

-  Commodore 64, 128
-  Commodore VIC 20
-  Commodore Amiga
-  Atari ST
-  Atari 8-bit family
-  FPGAs like [ZX-UNO](http://zxuno.speccy.org/index_e.shtml)

These are all computers that have compatible DB9, meaning that POWER & GROUND lines are the same.
Initially, I don't want to support computers where POWER/GROUND use different lines, like the Mastersystems.
That could be very dangerous.

See here [list of compatible systems](http://zxuno.speccy.org/index_e.shtml).

In the future, we could do a PC release to support PCjr, Tandy 1000 and other PCs.

## Goal #2

We want to create a solid, high quality product. But most important is to have fun and learn new things while developing it.

## TODO

The project is divided in 3:

### Hardware

We can reuse parts of Unijoysticle v1, but a few things should be added / changed:

-  Control all 7 lines: UP, DOWN, LEFT, RIGHT, FIRE, BUTTON LEFT (POT X), BUTTON RIGHT (POT Y).
   Unijoysticle v1 only controls the UP, DOWN, LEFT, RIGHT, FIRE. Four 4066, instead of three, are needed.
-  Support for C64 mouse: uses pot x / pot y, and they are both input+output lines.
   Additional hardware requirements might be needed.
-  Is it possible to power the ESP32 directly from the joystick ports?
-  In any case offer +5V power jack for external power supply (like in Unijoysticle v1).
-  Button to select the different modes: Single, Combo Joy+Joy, Combo Mouse+Joy
-  Button to remove all bluetooth stored keys (?) (might not be needed).
-  Switch to swap ports A + B (A game might require the joy connected to port A, while other to port B).
-  Offer cables to connect to different machines. (eg: for the Atari ST, it needs extension cables since the ports un under the case).

Note: No additional hardware is needed to support for Amiga/Atari ST mice.

Schematics + PCB in [KiCad](http://kicad-pcb.org/). Unijoysticle v1 was done in [Eagle](https://www.autodesk.com/products/eagle/overview). Since we want to learn new things, we are switching to KiCad now.

### Firmware

What's already done:

-  Basic generic mapping for gamepad
-  Bluetooth connect / reconnect working ok
-  Fetch product id + vendor id from SDP record
-  Gamepad: mappings based on product id + vendor id. Take DB from libSDL and adapt the mappings to our own needs.
-  *Gamepad System button* swaps joystick ports
-  Mouse kind of working... movement is not smooth yet.
-  Mouse: button are not mapped.
-  Support Bluetooth Classic HID devices
-  Support up until 2 gamepads connected, or one mouse + one gamepad.

Missing:

-  Mouse: smooth movement.
-  Add support for Bluetooth LE devices (eg: Some smart TV remote controllers are BLE).
-  Report back to client mode being used in the gamepads LEDS (in case available).
   The LEDs could be used for whatever purpose we want.

### Smartphone client

Create Android (iOS lower priority) client that allows us to:

-  Works as a Bluetooth client
-  Implement "Unijosytcile" mode: gyro / accel
-  Implement virtual gamepad
-  Implement Gyruss mode
-  Add way to see logs
-  Add way to switch between different modes (Combo Joy+Joy, Combo Mouse+Joy, Single) (?)
-  Add way to swap ports (?)

Since we want to learn new stuff, instead of coding the client in Java (like in Unijoysticle v1), we should do it in Kotlin.

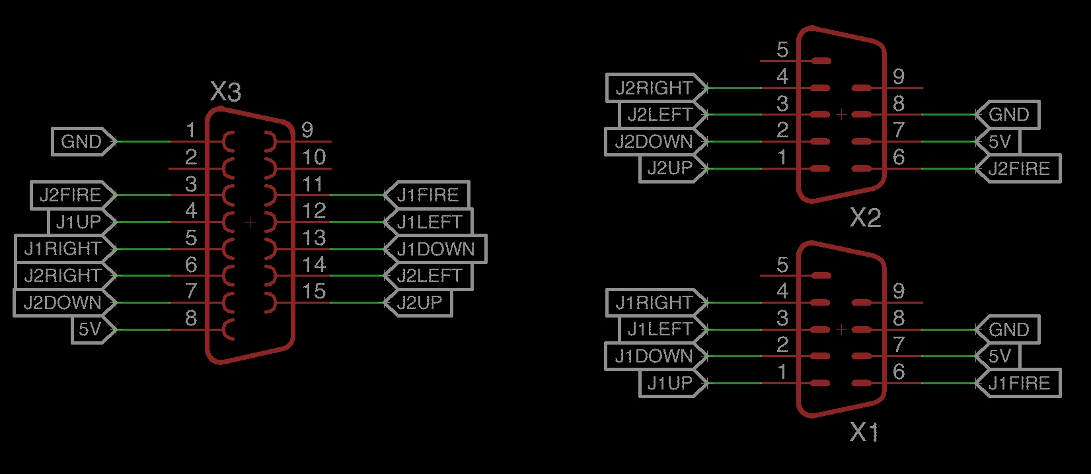
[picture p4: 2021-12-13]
contrib/unijoysticle2-neogeo/neogeo-unijoysticle2-adapter/neogeo-unijoysticle2-adapter-schematic.jpg

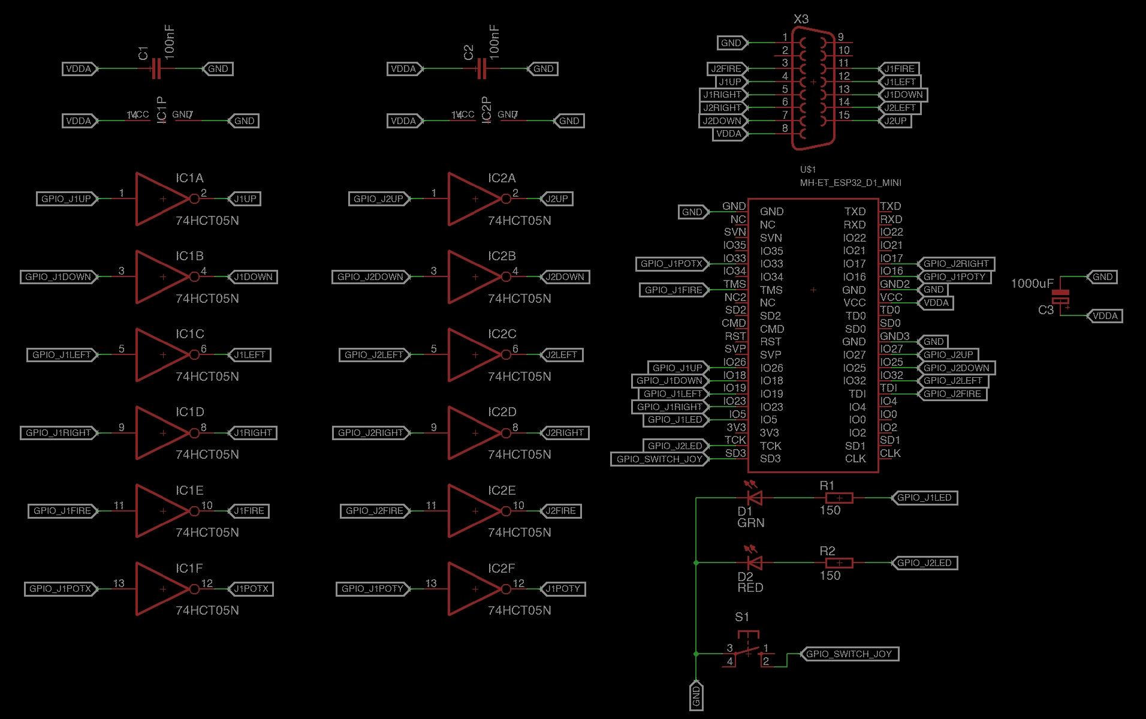
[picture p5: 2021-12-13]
contrib/unijoysticle2-neogeo/neogeo-unijoysticle2/neogeo-unijoysticle2-schematic.jpg

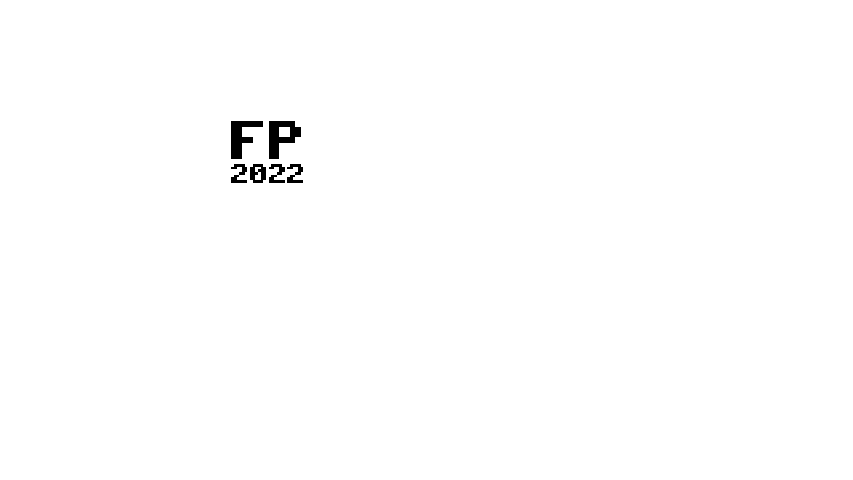
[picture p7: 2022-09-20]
board/unijoysticle2_flashparty2022/bmp/fp.png

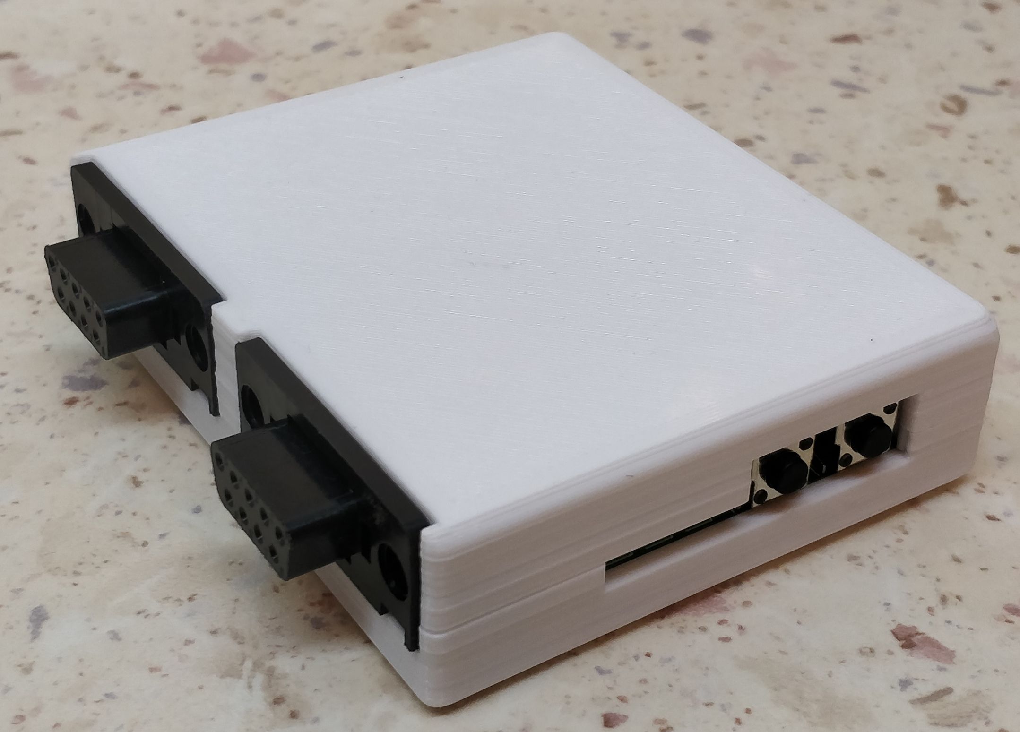
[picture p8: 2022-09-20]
contrib/unijoysticle2_a500-case/unijoy2_a500.jpg

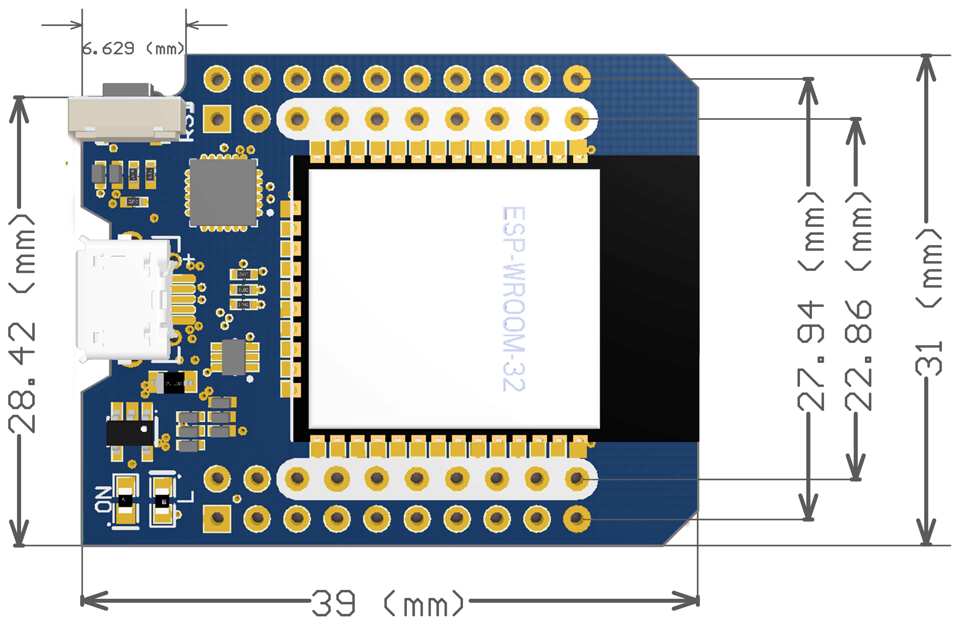
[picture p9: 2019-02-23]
board/mh-et-live-dimensions.jpg

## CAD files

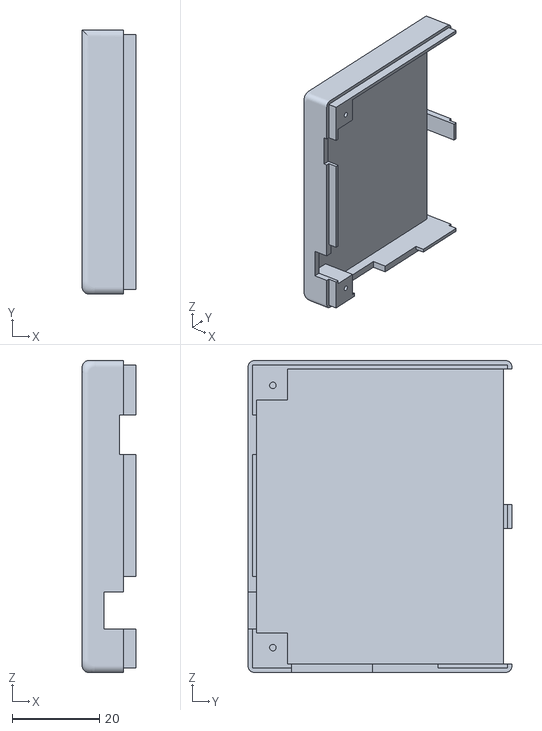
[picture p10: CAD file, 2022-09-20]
contrib/unijoysticle2_a500-case/unijoy2_a500_top.stl
12.3 x 60.5 x 71.5

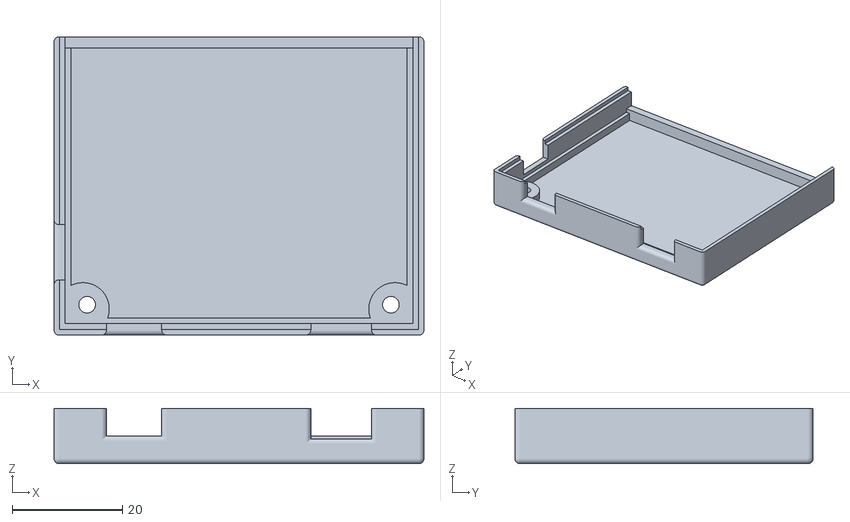
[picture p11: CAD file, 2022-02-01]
contrib/unijoysticle2plus-case/unijoysticle_bottom.stl
67.0 x 54.0 x 10.0

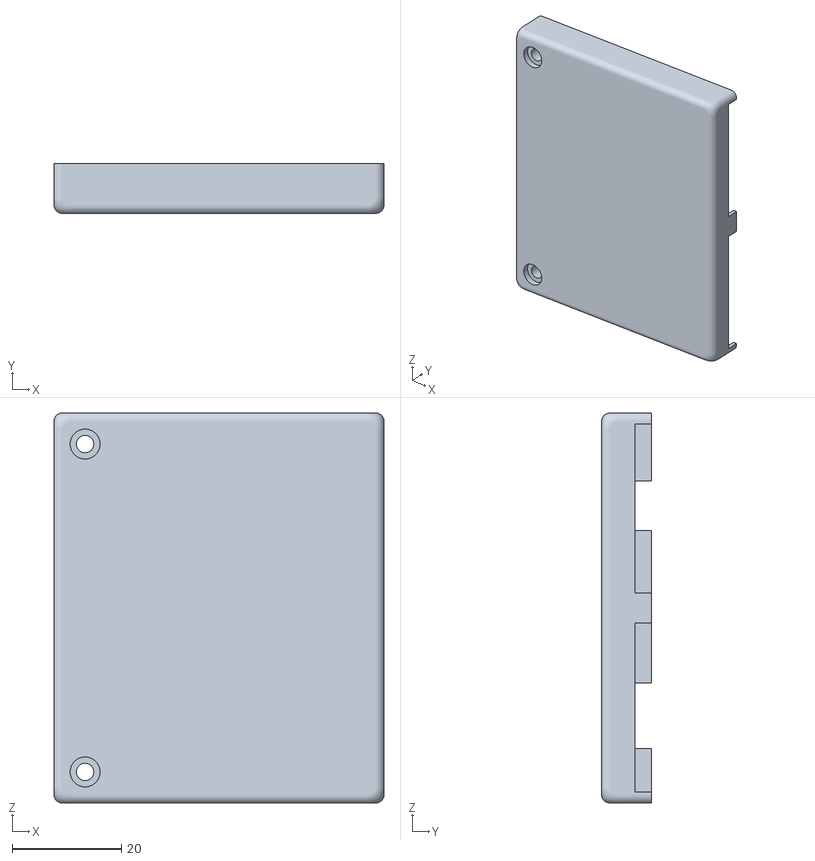
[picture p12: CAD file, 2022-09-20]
contrib/unijoysticle2_a500-case/unijoy2_a500_bottom.stl
60.5 x 9.10 x 71.5

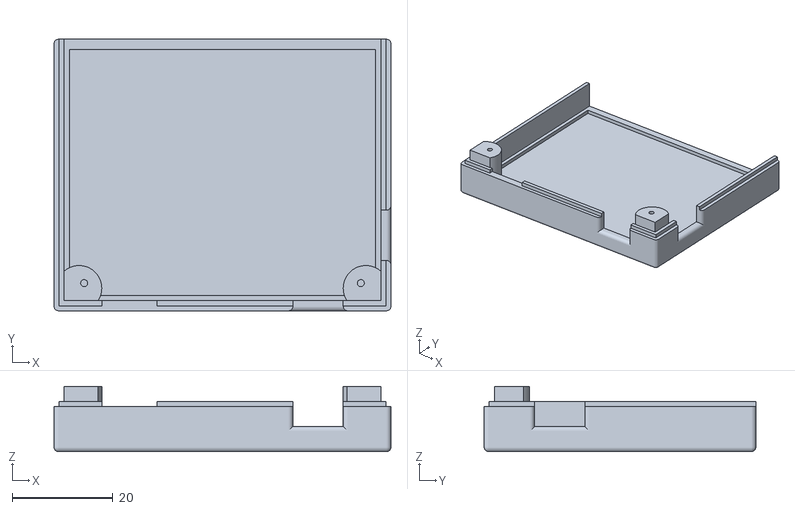
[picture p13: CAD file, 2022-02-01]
contrib/unijoysticle2plus-case/unijoysticle_top.stl
67.0 x 54.0 x 13.0

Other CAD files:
contrib/unijoysticle2_a500-case/unijoy2_a500.ipt

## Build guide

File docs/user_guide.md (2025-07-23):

# Unijoysticle™ 2, 2+, A500, C64, 800XL User Guide





[uni_logo]: https://lh3.googleusercontent.com/pw/AIL4fc_k4CtBs9deXjMuCJOotXbNoRwON1CdYCMshG41PpEf2v-7xc2IcIPFvYCOFeLriESlXEJhm5nK72st8v1E04ZzyqawW8x5DPJt2ug6ZzhGXdnJvasD577CX1Yb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

This guide is valid for Unijoysticle 2 models.
Features that are only applicable for Unijoysticle 2 / 2+/ 2 A500 / 2 C64 / 2 800XL, are tagged as **[v2 only]** / **[v2+ only]** / **[A500 only]** / **[C64 only]** / **[800XL only]** respectively.

## What is a Unijoysticle

Unijoysticle is that device that allows you to use modern Bluetooth controllers (gamepads, mice, balance board) in retro computers.

## Models

Unijoysticle 2 models:

| | 800XL | C64 | A500 | 2+ | 2 |
| --- | --- | --- | --- | --- | --- |
| Top | uni2800xl_photo_front | uni2c64_photo_front | uni2a500_photo_front | uni2plus_photo_front | uni2_photo_front |
| Bottom | uni2800xl_photo_back | uni2c64_photo_back | uni2a500_photo_back | uni2plus_photo_back | uni2_photo_back |
| Release date | July 2023 | March 2023 | July 2022 | October 2021 | April 2019 |
| Best for | Atari 800XL / 600XL | C64 / C128 | Amiga | - | - |
| Good for | Atari 400 / Amiga / AtariST | Amiga / AtariST | C64 / AtariST / Atari 8bit  | C64 / Amiga / AtariST / Atari 8bit | C64 / Amiga / AtariST / Atari 8bit |
| Status | Active / Supported | Active / Supported | Active / Supported | Discontinued / Supported | Discontinued / Supported |
| Amiga / AtariST mouse support | Yes | No | Yes | Yes | Yes |
| Amiga / AtariST 2nd & 3rd button support | No | No | Yes | Yes | Only in Port 1 |
| Atari 8-bit 2nd & 3rd button support (5) | Yes | No | No | No | No |
| C64 2nd & 3rd button support | No | Yes | No | No | No |
| C64 4th and 5th button support (4) | No | Yes | No | No | No |
| C64 Paddle support | No | Might (1) | No | No | No |
| Rumble (2) | No | Yes | No | No | No |
| Fits | 800XL / 600XL | C64 / C128 | Amiga 500 / 1200 | C64 / C128 | C64 / C128 |
| Buttons | Reset, Mode, Swap | Reset, Mode, Swap | Reset, Mode,  Swap | Reset, Mode | Reset, Mode |
| LEDs | Port 1, 2, Bluetooth, Power | Port 1, 2, Bluetooth, Power | Port 1, 2, Bluetooth, Power | Port 1, 2, Power | Port 1, 2, Power |
| Filter noise ([Issue #17][issue_17]) | Yes | Yes | Yes | Yes | No |
| Case friendly | Yes | Yes | Yes | Yes | No |
| Easy to solder | No. Most components are SMD | No. Most components are SMD | No. Most components are SMD | No. Most components are SMD | Yes. All components are through-hole  |
| Self-powered | Yes | Yes | Yes | Yes | Yes, can be turned on/off with switch |
| External power | USB | USB | USB | USB | Both USB and Barrel Jack 5V+ |
| Total Size (mm) | 65 x 75 x 13.6 | 72 x 68 x 13.6 | 67 x 72 x 13.6 | 64 x 64 x 13.6 | 63 x 66 x 17 |
| PCB Size (mm) | 53 x 72 x 1.6 | 63 x 60 x 1.6 | 52 x 67 x 1.6 | 49 x 62 x 1.6 | 46 x 57 x 1.6 |
| Weight (gr) | 27 | 27.1 | 25.6 | 24 | 37 |
| Current (mA) | ~96 | ~96 | ~96 | ~96 | ~100 |
| USB connector | Micro USB | Micro USB | Micro USB | Micro USB | Micro USB |

Notes:

- (1): Hardware physically connected, but firmware is still WIP.
- (2): Some C64 games can turn on/off rumble on gamepads. See: [Rambo], and [Lemans] ([video][rumble_video])
- (3): Right and Middle mouse buttons not supported in C64.
- (4): Based on [CrystalCT 5 buttons joystick][crystalct/5plusbuttonsJoystick] ([video][5_buttons_video])
- (5): Based on [Ascrnet Joy 2B+][atari_joy2bplus]

Unijoysticle 2 allows you to use modern Bluetooth gamepads. E.g. DualSense controller in retro computers like the Commodore 64, Amiga and AtariST.

It also supports mice (for Amiga / AtariST only).

[issue_17]: https://gitlab.com/ricardoquesada/unijoysticle2/-/issues/17
[uni2_photo_front]: https://lh3.googleusercontent.com/pw/AM-JKLUphquTBg9JoV-L7wuMtze_aKIJ8LvfokTakuBKSVFClziLWCViggcrlNZtqGUMgv6u6yYpZ_RuE2jdGSn3Q0oYl0jOQzzGcutRt-JiMjLZY_oAvK4LehrawNj_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
[uni2_photo_back]: https://lh3.googleusercontent.com/pw/AM-JKLXnMbJt7A55lUrtmiuKj4As98He7ZVi6YuPKg8N1sGbw1w5d5TtC8B-ilfoqC5QCKcZG8MFkmHNj5HgVbP8fdHhMBPx2CLgyRhaRmohx0SWF-_wZ57WYCfo7RlH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
[uni2plus_photo_front]: https://lh3.googleusercontent.com/pw/AM-JKLWV2Zo912VtOfuM71AluanNXGwVQiAehNEiQ1VL3L7SkWDl-9k0fA6tfza9QpGL52petBfFFFHMb8rh_ybSj17LOQA70IycMDQw6AVqlN8Jp4HDWT8sWcXHIPEQ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
[uni2plus_photo_back]: https://lh3.googleusercontent.com/pw/AM-JKLWs_G63eJRX8WuVVRoKKur8UQ-VcWTNbmkjFumwZYvDRhgjqamVa-X9CROAnoPyK3sHDmfwtqAtJiI1DHiwlINBPCgiEY4yWFYWl8SlHA_QOG7LmVKuOKy1UQa-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
[uni2a500_photo_front]: https://lh3.googleusercontent.com/pw/AM-JKLU1BbKnbuLE7Oa_VOY3AnBjYwNVcAPKJcmYa7WUnCK5gMM1bHZyK3lTZ1Mo0NtS30ogeeSqxySx3Qi2ux3AGOlocQnQe9a87NoiKz5tnmHV_IGf3hPln0qsr8t5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
[uni2a500_photo_back]: https://lh3.googleusercontent.com/pw/AM-JKLXMUngI6ctahY5clP-76UBjUem9L4Eehj4GFsEwUJwtZ3-MuZCV2nOsxiN3Go1PKvoc9sJbLRY8hCZ9TcV4cq5AtcAtscdjH1LiNzltFSgQY4IQEwSiPHfvhjhZ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
[bluepad32-fw]: https://github.com/ricardoquesada/bluepad32
[uni2c64_photo_front]: https://lh3.googleusercontent.com/pw/AMWts8AzoDnIOIiM-50UpjAqY8OgdsM6pzM3BuYWb2ZOg4K_o4TxygtSjuZvrKI92lrl4Qqf8sLT6PtLYsXzDbragTDgoeX4yTpymqoc450FiyjiBT1YHxRbLBtGWgUO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
[uni2c64_photo_back]: https://lh3.googleusercontent.com/pw/AMWts8C_vxauz3FAOv8NGAh64LGTExHwCj0N0bX73xsWIeDyR3efFPPUQb3JJQK5S8Qcm9B8bx3r_yio6WWAML1si4u8E9FejXP9DL8vxSCg_TR7rLi5aPiwisQaIptN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
[uni2800xl_photo_front]: https://lh3.googleusercontent.com/pw/AIL4fc9fcgdY3Gka6iSZmyUlBTA1Q9ABujo-9v_4qE85St2GdW-2TBzzLNx-pc25o0rFloL0ghWZDDVW_kGWpQjcXaP-SJf9NWPnNw-2jpc_8tcVKp8gzLH7fxnFd7DB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
[uni2800xl_photo_back]: https://lh3.googleusercontent.com/pw/AIL4fc9PNSKKiA7PHsUTLKXGF1O9ywK-qLHS0nw2-Y6FxWQcgmtZJjajQh9Uch0aqZ2Pw-grH_Vg05IKYZilissF6nxUJPDszew0ouzGu91golm1RYJJpPS0CDANAfk3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
[Rambo]: https://github.com/ricardoquesada/c64-rambo
[Lemans]: https://github.com/ricardoquesada/c64-lemans
[crystalct/5plusbuttonsJoystick]: https://github.com/crystalct/5plusbuttonsJoystick/
[5_buttons_video]: https://www.youtube.com/watch?v=9Em_kUAHEuA
[rumble_video]: https://www.youtube.com/watch?v=vCj45OX43JE
[atari_joy2bplus]: https://github.com/ascrnet/Joy2Bplus
[uni_logo]: https://lh3.googleusercontent.com/pw/AIL4fc_k4CtBs9deXjMuCJOotXbNoRwON1CdYCMshG41PpEf2v-7xc2IcIPFvYCOFeLriESlXEJhm5nK72st8v1E04ZzyqawW8x5DPJt2ug6ZzhGXdnJvasD577CX1Yb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

## Quick starting guide

Quick starting guide (https://www.youtube.com/watch?v=qxDbUfJXXyI)

1. Plug in the Unijoysticle
2. Power on the computer
3. Pair your gamepad and/or mouse

## Supported computers

supported computers

The Unijoysticle 2 was designed to fit in the Commodore 64, and Amiga 500 computers. No additional
cables are needed for these computers.

However, the Unijoysticle 2 can be used in any computer that is compatible with the Atari DB9 joystick ports.

That includes, but not limited to:

- Commodore 64 / SX-64 / 128 / 128-D.
- Atari 8-bit line, both computers and consoles (requires [DB9 extension cable][cable]).
- Amiga line (Unijoysticle2 / 2+ requires [DB9 extension cable][cable], Unijoysticle 2 A500 fits Ok).
- Atari ST line (requires [DB9 extension cable][cable]).
- Commodore 16 / 116 / +4 (requires adapter)
- [Vampire v4 Stand Alone][vampirev4] (tested by the community)
- [A2560 Foenix][a2560] (tested by the community)
- [Mega 65][mega65] (tested by the community)
- [Ultimate 64 Elite MK2][ultimate64_mk2] (tested by the community)

[cable]: https://www.aliexpress.us/item/3256802837275209.html
[vampirev4]: http://www.apollo-core.com/v4.html
[a2560]: https://c256foenix.com/
[mega65]: https://mega65.org/
[ultimate64_mk2]: https://ultimate64.com/Ultimate-64-Elite-MK2

## Flashing the firmware

See: [firmware_setup.md][firmware_setup]

[firmware_setup]: https://bluepad32.readthedocs.io/en/latest/firmware_setup/

## How to power on the device

There are multiple ways to power on the device

| | v2 | v2+ | A500 | C64 | 800XL |
| --- | --- | --- | --- | --- | --- |
| Self-powered | Yes, requires the "Self powered" switch to be On | Yes, always On | Yes, always On | Yes, always On | Yes, always On |
| USB powered  | Yes | Yes | Yes | Yes | Yes |
| External 5V+ | Yes, using the Barrel jack | No | No | No | No |

Note: It is safe to plug the two / three of them at the same time, but that won't give you any additional benefit.

### Self-powered

| 800XL | C64 | A500 | 2+ | 2 |
| --- | --- | --- | --- | --- |
| uni_800xl_self_powered_photo | uni_c64_self_powered_photo | uni_a500_self_powered_photo | uni2plus_self_powered_photo | uni2_self_powered_photo |

- Gets current directly from the joystick ports. No extra cables needed.
- [v2 only] "Self-powered" switch must be "ON", otherwise the ESP32 won't receive current.
- A beefy [power supply with ~4Amps][power_supply] is recommended (depends on the peripherals used).
- Tested successfully with:
  - C128 + 1541 Ultimate 2 + Unijoysticle 2 + [beefy power supply][power_supply].
  - C64 + 1541 Ultimate 2 + Unijoysticle 2 + [beefy power supply][power_supply].
  - SX-64 + Unijoysticle 2
  - Atari ST 1040F + Unijoysticle 2
  - Amiga 1200 + Unijoysticle 2 A500
  - Atari 800XL + Unijoysticle 2 800XL

Note: The Amiga 500 doesn't provide enough current to power the Unijoysticle.
You should power the Unijoysticle through the USB port.
It is possible to connect the USB port to the Amiga Disk Drive connector
(Pin 12 = +5V / Pin 3 = GND, see [How to build your own Amiga USB power cable][disk_drive_power]) which provides enough current.

Self-power is available since Unijoysticle 2 [Revision D][changelog_board], and is present in all
Unijoysticle 2+ / Unijoysticle 2 A500 revisions.

[uni2_self_powered_photo]: https://lh3.googleusercontent.com/XVQU7lkllCqc-1k6KX_3CdDIOlx0NCHO8NVDuBOJGdVef3Rq03KJpDHLqG_FNYW2GTeXOAxna9njsclcrlxmhOiBR_KvI-M8CDUOglUX9nCZLBILnkSB32Tews7yhmU38tf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
[uni2plus_self_powered_photo]: https://lh3.googleusercontent.com/pw/AM-JKLUXjhjUsPDIVH1C_i8310k5ERQT-IQc71w2ibmBWCHoKC5uEIHjHBdp52ydb0XBZoKqftGv8JIonAn9tfuxXnoo00BypKL62ZTk_kbOLEQwdXG7QM3FDhrHm41N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
[uni_a500_self_powered_photo]: https://lh3.googleusercontent.com/pw/AM-JKLUtRVviFYcUu_4RKifSOg3kyJziTpd3GLBE-e0frWdwAB1F0ZUNqEkGM3Hwqipi70lXpFAIv-mv6_u58-9bnSyI5JyPT_jNpRSQbV5D71nT31c45nqDhSkW2k6c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
[uni_c64_self_powered_photo]: https://lh3.googleusercontent.com/pw/AMWts8DAFSd1iqibcNFXnPkfKRICopugSYzP9YGy8gMeAqWyCzyV61yhsCcLeKK0ahP8rROQThGEd7MqJUvvyZwHhB4L1Mcx5z92Za34J4GyMu_m2wa4-K3oY1Zx3cWl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
[uni_800xl_self_powered_photo]: https://lh3.googleusercontent.com/pw/AIL4fc9AaTOQnQFTKaaGbHhyUZgO7H9PgAwFvMjDRFJPqZKZhQP8YR3x0D22Gp7PeF48RvQsnCiXdsayCW9CJgZukAguxavTUvQC91agpEEDc-LbWM8N4FKp_qd1EE1c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
[disk_drive_power]: https://github.com/ricardoquesada/unijoysticle2/blob/main/docs/amiga_500_usb_cable.md
[changelog_board]: https://github.com/ricardoquesada/unijoysticle2/blob/main/CHANGELOG.md

### USB-powered

| 800XL | C64 | A500 | 2+ | 2 |
| --- | --- | --- | --- | --- |
| uni2800xl_usb_powered | uni2c64_usb_powered | uni2a500_usb_powered | uni2plus_usb_powered | uni2_usb_powered |

- Use a micro-USB cable to connect the Unijosyticle device to your computer or socket.
- Ideal for debugging: you can see the Unijoysticle console by attaching a terminal to it.
- Needed in the Amiga 500.
- [v2 only]: "Self-powered" switch can either be "On" or "Off".

[uni2_usb_powered]: https://lh3.googleusercontent.com/lYiISEtede7TkKwvBZyOB57ZUynSDzPuKIqmfp6Cpl75BbGENM6qZkAXWD066YhpY1Xg-k016PrVt3783Q6iuLXFOdZrpXIW_XaEEwRaeUFvPBk1XVtwIvVjmxMGt5bvAPU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
[uni2plus_usb_powered]: https://lh3.googleusercontent.com/pw/AM-JKLXXbxm4umDQfC-xYt9AzvAWIXsGQaYrpQUFnDpYwE0F5SanC8DgjQu9Uu7s9nj2dAd1dVWq4WD8EWxifGM8t73bT0Mz-yiFPCXn8dyUgNXkW2FA2SA00PfL_kdC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
[uni2a500_usb_powered]: https://lh3.googleusercontent.com/pw/AM-JKLUekMUSSBPmg3XLniMY1ykeDqYs7NBES2_Y4Q-ld2w0CkQNBWakbI6w-Vu0HiSDhFstachOMwOcS6CH-Cm9fYB7WcWWObe3MBBUhD0E-OC2CbqKIWCjF4V4lZxL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
[uni2c64_usb_powered]: https://lh3.googleusercontent.com/pw/AMWts8CFRhwQWFVujIpi5U4ucUAWYyEYYBwoBSXAZwc8h4fzOm18BaolGFL3R7pNVUVJYV0bz-WgzEZ4wLE8FZfvtz1GLaK2YdkYQy8_YU3x966TSuEA5E60XTRI0bdO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
[uni2800xl_usb_powered]: https://lh3.googleusercontent.com/pw/AIL4fc9ciKYc2fC19xQLuo-LiLVxl6PsW3BcCK4SmjJ2WCBZAdYOd8tUVoRZ-wLNIdhNnflVXOhuMioV8Z1rj1UZNFL-4r7VWwBidbIM_zEl44qd1AKfGnpIspZS2hps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

### Jack Barrel-powered [v2 only]

jack_barrel_powered

- Connect a 5V+ / ~250mA to the Power Barrel Jack (like some Arduino boards).
- Polarity: positive polarity (tip=+5v, sleeve=0v).
- [v2 only]: "Self-powered" switch can either be "On" or "Off".

[power_supply]: https://www.carlsenelectronics.net/

## Unijoysticle Buttons and LEDs

### 800XL / C64 / A500 models

| 800XL | C64 | A500 |
| --- | --- | --- |
| uni2_800xl_buttons_photo | uni2_c64_buttons_photo | uni2_a500_buttons_photo |

LEDs:

* Bluetooth LED (Blue)
  * On: New connections are accepted. Both "connects" and "re-connects" are accepted.
  * Off: No new connections are accepted. Existing connections will stay on.
* J1 LED (Green):
  * On: Gamepad or mouse is controlling joystick port 1
* J2 JED (Red):
  * On: Gamepad or mouse is controlling joystick port 2
* Power LED (Red):
  * On: Unijoysticle has current.
  * Off: Disconnected.

Buttons:

* Reset button: Restart the firmware. Connected gamepads/mice will get disconnected.
* Swap button: Swaps connected gampepads / mice.
  * For example if a DualSense gamepad is controlling joystick 1 and an Xbox gamepad is controlling joystick 2,
    "swap" will just swap the gamepads. The result will be that DualSense will control joystick 2 and the Xbox will
    control joystick 1
* Mode button: Changes the "mode" of the connected gamepad. Modes:
  * Basic mode: Connected gamepad controls one joystick
  * Mouse mode: Connected gamepad controls one mouse **[800XL] / [A500 only]**
  * Twin Stick mode: Connected gamepad controls two joysticks at the same time

To know in which "mode" it is, the Bluetooth LED (Blue) will blink:
  * 1 blink: It is in "Basic mode"
  * 2 blinks: in "mouse mode"
  * 3 blinks: in "twin stick mode"

See below for further details about gamepad modes.

[uni2_a500_buttons_photo]: https://lh3.googleusercontent.com/pw/AM-JKLULCdDRyDWDQ8R2v0Ab_HjcxOxOtNOTlaj0OrrFvEyEr9zNo8DBBCgVrOGWran1PLX3Ja3LvcpdmU0vw1MnnEZUrv5JQglA7grNkS08wlwpkU6Pt7nnmK5k2sDy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
[uni2_c64_buttons_photo]: https://lh3.googleusercontent.com/pw/AMWts8BLrqDjE_ZWreEFw-cU4iQtUnFR5CPL0PEJwbHsmPZHsgwGgepQseeV5Q74Hf3vNOmEaAfgpKjvkn5IBW5XlvhnChfOo6qKD9iBK58ACph9fCVpb1NZiw1eGLzt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
[uni2_800xl_buttons_photo]:  https://lh3.googleusercontent.com/pw/AIL4fc8j5MhVkI9E2Xp96LRjCcXvZTypFJQgdugg58a2aPZRw4PRE1EjWRrEg5-311VJVXKQUuixVI07x7cNy5plkpAdIUec8DBfDbT0Xb7_P7IoHsHr-KKXtUTqC3c8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

### V2 / V2+ only

| V2 | V2+ |
| --- | --- |
| uni2_buttons_photo | uni2plus_buttons_photo |

LEDs:

* J1 LED (Green):
  * On: Gamepad or mouse is controlling joystick port 1
* J2 JED (Red):
  * On: Gamepad or mouse is controlling joystick port 2
* Power LED (Red in V2 / Blue in V2+):
  * On: Unijoysticle has current.
  * Off: Disconnected.

Buttons:

* Reset button: Restart the firmware. Connected gamepads/mice will get disconnected.
* Enhanced Mode button: Switches between "Twin Stick mode" and "Basic mode"
  * Basic mode: Connected gamepad controls one joystick
  * Enhanced mode: Connected gamepad controls two joysticks at the same time

See below for further details about gamepad modes.

[uni2_buttons_photo]: https://lh3.googleusercontent.com/pw/AM-JKLU5gPENmNjtLsOzfDNbzIH8597OjQ0O6Fl7iPwR4eah0w_eu-8sASmnNZj9COHXjBaB8kZwdZUiqluDmbOGRc4gukS54MHZc108wQSo2tKk-n9grNgD8yW-IeTh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
[uni2plus_buttons_photo]: https://lh3.googleusercontent.com/pw/AM-JKLXs6fWz4eqK38pgRKOMIorQvSgxdaFHCGCZL7e-ynURso2G4mMwXb6MM1eadIorlsIMhcN3FkZ7S1FWV3lTUxxFZYfdoZyYNDYIjt25fvVlspf8Mh518OrMW0Gg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

## Using Gamepads

The first gamepad to connect will control joystick 2 (Red LED).
The second gamepad to connect will use the available joystick.

If you want to control joystick 1 (Green LED), and you only have one gamepad connected,
you have to press the "swap" button in the gamepad.

swap joystick

The "swap" button varies from gamepad to gamepad, but usually it is mapped both to:

* the big button in the center (AKA PS, Xbox button)
* and to the "select" (AKA "-", "Share" buttons)

E.g: In the Xbox One it is the "Xbox" button; for PlayStation gamepads, it is the "PS" button. 

If two gamepads are connected, then both controllers must press the "swap" button in order to swap joysticks.

The gamepad could be in three possible modes:

- Basic mode: one gamepad controls one joystick.
- Twin Stick mode: one gamepad controls the two joysticks.
- **[800XL] / [A500 only]:** Mouse mode: one gamepad controls one mouse.

To switch modes you can press:

* the "mode" button in the Unijoysticle device
* or the "Start" (AKA "+", "Options" button) on the gamepad

### Basic mode

basic mode

*Basic mode* is what you would expect, with the additional benefit that
Button B is mapped to "jump". Ideal for platform games like Giana Sisters,
Super Mario Bros, Mayhem in Monsterland, etc.

- D-pad/joypad: controls up/down/left/right
- Button A / Cross: fire button
- Button B / Circle: "up"  (ideal for platform games)
- Button X / Square: 2nd button (Amiga / Atari ST only)
- Button Y / Triangle: 3nd button (Amiga / Atari ST only)
- Button shoulder-right: autofire

### Twin Stick mode (AKA Enhanced mode)

twin stick mode

In *Twin Stick mode*, you control both joysticks from only one gamepad.

Ideal for Twin Stick games like:

* [Commando 2084][commando2084]
* [Robotron 2084][robotron2084]

And since "Button B" is mapped to "J1 fire" this is great for games that use "space", like:

* [Commando][commando] to throw grenades
* [1942][1942] to do rolls
* [Turbo Outrun][turbo_outrun] to press "turbo"
* and many others

Mappings:

- Left joypad / d-pad: control Joystick 2 movements
- Right joypad: control Joystick 1 movements
- Button A / Cross: fire for Joystick 2
- Button B / Circle: fire for Joystick 1
- Button X / Square: 2nd button for Joystick 2
- Button Y / Triangle: 2nd button for Joystick 1
- Button Shoulder Left: auto-fire for Joystick 2
- Button Shoulder Right: auto-fire for Joystick 1

[1942]: https://csdb.dk/release/?id=38140
[commando]: https://csdb.dk/release/?id=137173
[turbo_outrun]: https://csdb.dk/release/?id=192474
[commando2084]: https://csdb.dk/release/?id=182074
[robotron2084]: https://csdb.dk/release/?id=94019

### Mouse mode

mouse mode

[A500 only]

In *Mouse mode* you control the mouse from a gamepad.

- Left or Right axis control the cursor movement
- Button A / Cross: left button
- Button B / Circle: right button
- Button X / Square: middle button

Note: Mouse emulation only works on Atari 8-bit / Atari ST / Amiga computers.

## Gamepad buttons **[C64 only]**

In addition to the regular 3-button mode, Unijoysticle2 C64 supports two special modes:

* "5 buttons mode" that allows to use 5 buttons (instead of the regular 3).
* "rumble mode" that allows the game to send "rumble events" to the gamepad

| 3-button mode (default mode) | 5-button mode | rumble mode |
| --- | --- | --- |
| 3-button-mode-png | 5-button-mode-png | rumble-mode-png |

To enable / disable this mode (disabled by default), you have to use the serial console (see below for further instructions). E.g:

```sh
bp32> set_c64_pot_mode 5buttons
```

* `set_c64_pot_mode`: `3buttons`, `5buttons` or `rumble`
  * `3buttons`: Default mode. 2nd and 3rd pot buttons are enabled.
  * `5buttons`: In addition to the 2nd and 3rd buttons, it also enables 4th and 5th buttons. See [crystalct/5plusbuttonsJoystick] for further info.
  * `rumble`:  Only regular "fire" is enabled. Gamepad can receive "rumble" events from the game by using the POT lines.

For further info about "Rumble" mode please watch:

Rumble mode (https://www.youtube.com/watch?v=vCj45OX43JE)

[3-button-mode-png]: https://lh3.googleusercontent.com/pw/AMWts8ANW9Ky9WLpThoE5x0kuA2xUNO6T0pv5mucPR1i_DfTJQ8edOssrlhh4dytV7FlrfZe_aE6J8fmxmW2D47YuCWc6TAcfaSSbCQD7A8NX9Y-0pGsl6Zp_p0DsDQA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
[5-button-mode-png]: https://lh3.googleusercontent.com/pw/AMWts8Ar_Vi7O3z_FmmEHapim3E9J79e0kPVGuXGSWsY8HN8xyXkrYGV6nGIOAxhA2onhC5Sv2yUUafETDQDw6sIMlXoA-v6mVyiFy6UzbDJmWSUDhHIsJvOAtjd9B4J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
[rumble-mode-png]: https://lh3.googleusercontent.com/pw/AMWts8BkMB3EONK3cRJBncApRJaCgAWE6gCC7w1imZv5svzrlG0EWDtK2s95Ai10-QUz9Gy73IC5Ww0kI0qsPDTmG0kfdN-ezX7CRLS8szyq4peoTro_35RxXPqhRv5Q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

## Supported controllers

Unijoysticle supports most, if not all, modern controllers.
This is a non-comprehensive list of all supported controllers.

### Supported gamepads

Supported gamepads

- Sony DualSense
- Sony DUALSHOCK 4
- Sony DUALSHOCK 3
- Sony PS3 Move
- Xbox Wireless (models 1708, 1914)
- Nintendo Switch Pro
- Nintendo Wii U
- Nintendo Wii
- Nintendo Balance Board
- Stadia
- Steam
- Android gamepads
- PC/Window gamepads
- 8BitDo
- iCade
- And more

For a complete list, see:

* [Supported gamepads][supported_gamepads]

### Supported mice

Supported mice

Mouse emulation is only avaiable for **Amiga, Atari ST and Atari 8-bit** computers.

For a detailed list of supported mice, see here:

* [Supported mice][supported_mice]

[supported_mice]: https://bluepad32.readthedocs.io/en/latest/supported_mice/

## Console

You can configure and dump the current Unijoysticle status from the USB Console.

1. Connect the Unijoysticle with the micro-USB cable to your computer
2. Launch a terminal

### CH340 Driver (Windows only)

The drivers are only needed for Windows. Linux has built-in support for CH340.

After connecting the usb cable to the Unijoysticle and your PC do:

*  Open "device manager" and check if a serial port has been added under "ports COM and LPT"
   *  If not, then download and install [CH340 USB to Serial Driver][ch340_win_driver]
   *  If you have trouble installing the drivers, see: [SparkFun CH340 Install guide][sparkfun_ch340] 
*  Look at which serial port number has been added (COMx where x is a number)

[ch340_win_driver]: http://www.wch-ic.com/downloads/CH341SER_ZIP.html
[sparkfun_ch340]: https://learn.sparkfun.com/tutorials/how-to-install-ch340-drivers/all

### Install a terminal program

* Windows: [Putty][putty], [Arduino Serial monitor][arduino-monitor] (See "Troubleshooting" for detailed steps), [idf.py monitor], etc.
* macOS: [tio], [minicom], [idf.py monitor], etc.
* Linux: [tio], [minicom], [idf.py monitor], etc.

The parameters for the terminal are:

* Choose the correct port:
  * Windows: See above
  * Linux & macOS: `/dev/ttyUSB0` (or `ttyUSB1`...)
* Connection speed (bauds): 115200

[putty]: https://www.putty.org/
[arduino-monitor]: https://docs.arduino.cc/software/ide-v2/tutorials/ide-v2-serial-monitor
[minicom]: https://help.ubuntu.com/community/Minicom
[tio]: https://github.com/tio/tio
[idf.py monitor]: https://docs.espressif.com/projects/esp-idf/en/latest/esp32/api-guides/tools/idf-monitor.html

### How to use it

asciicast (https://asciinema.org/a/506468)

As an example, this is how to connect to the console using `tio` and `minicom`

```sh
# tio: A great serial terminal  (recommended!)
$ tio /dev/ttyUSB0

# If you can't use tio, minicom works too.
$ minicom -D /dev/ttyUSB0
```

There are many useful commands. The most "common" ones are:

* `list_devices`:  Get information about connected devices
* `list_bluetooth_keys`: List Bluetooth bond keys
* `del_bluetooth_keys`: Delete stored Bluetooth bond keys. Useful if you are having reconnect issues.
* `incoming_connections_enable <0 | 1>`: To enable/disable Bluetooth incoming connections.
* `swap_ports`: Swaps joystick ports
* `gamepad_mode  <mode>`: `normal`, `twinstick` or `mouse`
  * `normal`: One gamepad controls just one joystick.
  * `mouse`: Gamepad behaves like a mouse. Usefule in Amiga / AtariST
  * `twinstick`: One gamepad controls both joysticks at the same time. Good Twin Stick games like [Commando 2084][commando2084]
* `c64_pot_mode`: `3buttons`, `5buttons` or `rumble`
  * `3buttons`: Default mode. 2nd and 3rd pot buttons are enabled.
  * `5buttons`: In addition to the 2nd and 3rd buttons, it also enables 4th and 5th buttons. See [crystalct/5plusbuttonsJoystick] for further info.
  * `rumble`: Allows games (e.g: [Rambo], [Lemans]) to send "rumble" feedback. 2nd and 3rd buttons are disabled.
  * [Collection of C64 games that are known to work with more than one button, or in rumble mode][c64_collection]
* `mouse_emulation  <emulation>`: `amiga`, `atarist`
  * `amiga`: Emulates an Amiga mouse (default for A500, v2, v2+)
  * `atarist`: Emulates an Atari ST mouse (default for 800XL)
* `mouse_scale  <value>`: Set/get global mouse scale factor
* `autofire_cps  <cps>` Sets the autofire 'clicks per second' (cps)
* `version` Gets the Unijoysticle version info
* `help`: Print the list of registered commands

[crystalct/5plusbuttonsJoystick]: https://github.com/crystalct/5plusbuttonsJoystick/
[c64_collection]: https://github.com/ricardoquesada/c64-games-unijoysticle

## Troubleshooting

### Fails to boot

booting

Booting the device takes ~1 second. You should see:

- Power LED must be On
- J1 (Green) & J2 (Red) LEDs should stay On for ~1 second
- Once J1 and J2 are Off, the device will be ready to use

If one of the above mentioned conditions are not met, please file a bug (See "Filing bugs" down below).

### Gamepad cannot connect

This could be due to a lot of things. Assuming that you are using a [supported gamepad][supported_gamepads], try:

1. Unplug the Unijoysticle from the Commodore (turn off the Commodore first).

2. Reset the Unijoysticle: Press the "Reset" button that is placed in the ESP32 Mini Kit.

3. While rebooting, the LEDs should turn on, and after ~half a second, then they should turn off.
   - If the LEDs don't turn On at all: file a bug (see below).
   - If the LEDs don't turn Off, it means that Bluetooth is not ready. Go to step 2.

4. Once the LEDs are off, trying connecting the Gamepad again.

5. If it fails press "Reset + Toggle-Mode" buttons at the same time.
   This will reboot the Unijoysticle while also deleting the stored Bluetooth keys.

6. Put the gamepad in Bluetooth discovery mode (grab the manual of your gamepad). Try again.

7. If it fails, trying connecting the gamepad to a Linux (MacOs or Windows might be the same) machine first.
   If the gamepad cannot connect to Linux, then most probably it is a gamepad issue. Cannot help here.

8. Repeat. Go to Step 2.

If it keeps failing, file a bug (see below).

[supported_gamepads]: supported_gamepads.md

### Gamepad cannot re-connect

Assuming that the gamepad connects Ok for the first time, but fails to reconnect then:

- Press the Reset + Toggle-Mode buttons at the same time.
  This will reboot the Unijoysticle while also deleting the stored BT keys.
  Any try again.

- Put the gamepad in Bluetooth discovery mode. And try again.

If none of the above works, file a bug (see below).

## Filing bugs

File bug here: https://github.com/ricardoquesada/unijoysticle2/issues

When you file a bug, make sure that you include as much information as possible:

- Gamepad you are using. If possible the firmware version the gamepad is using.
- Unijoysticle firmware.
- Computer that you are using: C64, C128, etc.
- How you are powering the Unijoysticle.
- Logs (this is the most important thing!)

### Unijoysticle logs

The logs can be fetched by connecting a terminal to the ESP32 module.

1. Connect the Unijoysticle to the PC using a micro USB cable.
2. Launch any serial terminal. Possible options:
   * Arduino Serial Terminal (See below for detailed steps)
   * or `minicom -D /dev/ttyUSB0` (Linux, macOS)
   * or `tio /dev/ttyUSB0` (Linux, macOS)
   * or `idf.py monitor` (Linux, macOS, Windows. requires to checkout Bluepad32 source code)
   * or [putty] (Windows only)
3. Reset the Unijoysticle
4. Try to connect the gamepad again.
5. Let it try for a few seconds.
6. Copy & paste the output from the terminal and put it in the bug report.

### Arduino terminal step-by-step

1. Download Arduino from here: https://www.arduino.cc/en/main/software
2. Launch Arduino -> Tools -> Set Port

   Arduino Set Port

3. Arduino -> Tools -> Serial Monitor

   Arduino Serial Monitor

4. From the Serial Monitor, set Bauds to 115200

   Set Bauds

## Contact

* 
* Email group: https://groups.google.com/forum/#!forum/unijoysticle

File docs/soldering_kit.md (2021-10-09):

# Soldering the Unijoysticle 2 kit

**Warning**: Not valid for Unijoysticle 2+

This is a detailed step-by-step guide, intended mostly to people not familiar with soldering.

## What's needed

### The Unijoysticle 2 Kit

Unijoysticle 2 kit

Needed components:

- 1 x Unijoysticle 2 PCB
- 1 x ESP32 Mini Kit (and its pins) (ref: B1)
- 2 x 74HC05N ICs
- 2 x 14p DIP sockets for the 7405s (ref: IC1, IC2)
- 1 x standard green LED 3mm (ref: D1)
- 1 x standard red LED 3mm (ref: D2)
- 2 x 1N5819 (or 1N4001) diodes (ref: D3, D4)
- 2 x 150 ohm resistors (ref: R1, R2)
- 1 x Switch Tacticle SPST (ref: SW1)
- 1 x Switch Slide SPDT 200mA (ref: SW2)
- 2 x db9 female connectors (ref: J1, J2)
- 1 x DC Power Barrel Jack (ref: J3)

You can source the components from here:

- Unijoysticle 2 PCB from: [PCBWay][pcbway]
- ESP32 devkit from: [ESP32 Mini Kit][esp32mini]
- Remaining components: [DigiKey list][digikey]

[pcbway]: https://www.pcbway.com/project/shareproject/Unijoysticle_2___Rev_F__Gamepads_for_the_C64_and_other_retro_computers.html
[esp32mini]: https://www.aliexpress.com/store/product/MH-ET-LIVE-ESP32-MINI-KIT-WiFi-Bluetooth-Internet-of-Things-development-board-based-ESP8266-Fully/2348158_32819107932.html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
[digikey]: https://www.digikey.com/short/z2fr7v

### Additional tools

- [Soldering iron][soldering_iron]
- [Solder][solder]
- [Wire cutters][wire_cutters]
- [Copper alligator clips][alligator_clips]
- [Plier][plier]
- [Isopropil alcohol 99%][alcohol]
- [Cotton swab][cotton]

[soldering_iron]: https://www.google.com/search?q=hakko+fx888d
[solder]: https://www.google.com/search?q=kester+lead+free+solder
[alligator_clips]: https://www.google.com/search?q=copper+alligator+clips
[wire_cutters]: https://www.google.com/search?q=Wire+Cutters%2C+Precision+Electronic+Flush+Cutter
[plier]: https://www.google.com/search?q=long+nose+plier
[alcohol]: https://www.google.com/search?q=isopropyl+alcohol+99%25
[cotton]: https://www.google.com/search?q=cotton+swap

## Reference Image

Use it as a reference to where place the different components.

reference

## Safety

I assume you have soldered before, at least once, and you know the very basic safety guidelines:

- Wear safety goggles when soldering
- Use a fume extractor when soldering, or solder in a ventilated area
- Never touch the tip of the soldering iron

But there are more, [read all of them][safety]

[safety]: https://ehs.stonybrook.edu/programs/laboratory-safety/laboratory-equipment/soldering

## Step 1: Prepare the db9 connectors

Use the plier to remove the screws and the metal shield from the db9 connectors.

prepare db9 connector

## Step 2: Solder the resistors

It is better to solder first the components with the shortest profile. Start with the resistors.

- Bend the wires as shown below:

resistors

- Insert the resistors in positions **R1** and **R2** (see Reference Image)
- Resistors don't have polarity. There is not such a thing as "good" / "bad" orientation.
- Once the resistors are inserted, flip the PCB and "unbent" the wire as shown below:

unbent_resistors

- And solder them
- Use wire cutter to cut the "extra" wire. As close as possible to the PCB, but don't cut the solder

resistor_wire_cutter

## Step 3

TODO: Finish this guide

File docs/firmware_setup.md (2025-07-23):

# Firmware setup

Firmware, including its instructions, were moved to the Bluepad32 repo.

Read them here: [Firmware Setup][firmware_setup]

[firmware_setup]: https://bluepad32.readthedocs.io/en/latest/firmware_setup/

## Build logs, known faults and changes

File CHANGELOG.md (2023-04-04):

# Changelog

All notable changes to this project will be documented in this file.

The format is based on [Keep a Changelog](https://keepachangelog.com/en/1.0.0/).
Adheres to the "standard" way to version boards/layouts. E.g: letters instead of numbers.

## [RPi Hat for C64] - 2023-04-03
### New

* RPi Hat for C64. Similar to the A500 but with a few more resistors for the POT buttons
* Ports fits the C64

## [Unijoysticle 2 C64 - Rev C] - 2023-03-12
### New

* Unijoysticle C64: Model to be used in Commodore 64/128
* Supports Pot buttons (2nd and 3rd buttons)
* Supports rumble

## [Unijoysticle 2 A500 - Rev C] - 2022-07-??
### New

* Unijoysticle A500: Model to be used in Amiga 500 / 1200
* Supports Amiga / AtariST mouse

### Added

 * contrib: Unijoysticle2 NeoGeo adapter for Unijoysticle2
 * contrib: Unijoysticle2 for NeoGeo
 * contrib: Unijoysticle2 A500 case

## [Unijoysticle 2+ Rev F] - 2021-10-03

### Added: New model: Unijosyticle 2+!!

  * It is case friendly
  * Doesn't use ESP32 Mini Kit, it is built-in
  * Most of the components are SMD, hand-solder friendly (0805 package)
  * Includes caps to filter hi and low frequencies: fixes noise on C128
  * Consumes tiny bit less of current: from 100mA to 96mA
  * Has extra 7405 to control buttons 2 and 3 on both ports on the Amiga / Atari ST

### Changes from Rev A

  * Uses 0805 with long pads (hand-solder friendly)
  * Uses CH340C instead of CP2102 (hand-solder friendly)
  * USB Micro connector moved a few mm inside the board.
    * Board has "hole" so that the USB Micro has space
  * Board has 4 layers instead of 2.
    * Board can be routed in 2 layers without major probblems,
      but using 4-layers for testing purposes.
  * Cap to filter noise in C128 working Ok
  * Autoboot working Ok
  * LEDs have more or less the same intensity

## [Unijoysticle2+ Rev A] - 2021-06-22

* First attempt of the Unijoysticle2+
  * It is case friendly
  * Doesn't use ESP32 Mini Kit, it is built-in
  * Most of the components are SMD
  * Includes caps to filter hi and low frequencies
  * Schematic seems to be Ok, but layout is not.
* Firmware, including all related files, moved to Bluepad32 repo
* Only things related to the board like schematics and layout are kept in this repo
* Community contributions:
  * C16/Plus4 board, by Eduardo Casino
  * C64 - Rev H board, by Kospec C64

## [Revision F] - 2020-09-17

* Includes Schottky diodes from Rev E.
* Adds mounting hole, for a possible case
* Logo is made as "locked" so that it doesn't get removed after a re-route

## [Revision E] - 2020-02-06

* Revision E is a contribution by Kopsec C64
* It is en Eagle format.
* They layout is slightly different
* Uses Schottky diodes

## [Revision D] - 2019-09-28

* Board: a bit wider than Rev C. Easier to solder.
* Replaces DIP switch with Swith Slide SPDT.
  * Easier to source a 200mA Switch Slide than a 200mA DIP switch.
* Funcional equivalent to Rev C.
* Public release.

## [Revision C] - 2019-09-??

* Board: a bit wider, and taller than Rev B. Easier to solder.
* 7405 are powered from C64. Allows to plug in the Unijoysticle unpowered
   without causing noise in CIAs.
* Possibility to power the Unijoysticle from C64, if power supply is big enough.
* KiCad Project: moved SparkFun.lib inside unijoysticle project.
* Internal version: Not released to public.

## [Revision B] - 2019-04-15

### Added

* Schematic: Rev B.
* Board layout: Rev B.
* Initial public release.

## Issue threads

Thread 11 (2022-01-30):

Unijoystickle with Joystick switcher

mwedmark, 2022-01-30:
A classical product that is very close to UJ is a Joystick switcher to be able to switch between Port 1 and Port 2, maybe especially for C64. This would be a great addition to the current board.
This would mean at least one more 9-SUB input male connector and maybe one more button to set UJ in pass-through/Bluetooth mode. By some kind of keypress/switch combination, switching between Port 1 and Port 2 passs-through.
Anything interesting to extend UJ with?

I managed to squeeze in a 9-pin DSUB male for Joystick input and also Route 5 lines (UP/DOWN/RIGHT/LEFT/FIRE) to 5 of the non-used SPI pins on the ESP32. It actually still uses the same size PCB but most components have move. I think it used 54 VIA's in the end currently. I don't know if this would end up violating any old rule you had whne setting up the PCB. This verrsion would probably NOT be easy to hand solder... everything is very tight!

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

ricardoquesada, 2022-01-30:
Interesting idea.
Although I'm not convinced about the use case.

Switching between port #1 and port #2 is already supported in the Unijoysticle... just pressing the "Home" button in the gamepad does that.

Adding the extra port to support a wired-joystick + a gamepad adds some value I guess. I guess some users might want that.
But I think it will add more confusion...

But hey, feel free to build them!

mwedmark, 2022-01-30:
Just to be clear I haven't even built or used any Unijoystickle yet, but I will try it. I guess will build both the original Unijoystickle 2+ and try it out on my C64 Breadbox and also build some of these and try them out. Do you see any problem with adding a pass-through mode for this new port in software?

ricardoquesada, 2022-01-30:
it depends the amount of code needed.
The firmware is structured in a way that it is easy to create their own platforms.
As an example, the code has 6 "platforms":
 - unijoysticle
 -  mightymiggy
 - arduino
 - nina
 - circuipython
 - pc_debug (used mostly for debugging)

And for me, it is easier if the owners of the different platforms add and maintain their own code.
Adding code for the Unijoysticle that I cannot test is not a good idea.

Also the "unijoysticle" platform at the moment has 3 different modes: unijoysticle 2, unijoysticle 2+ and arana's net unijoysticle...

So, mantainance is something that I worry about.

Are you familiar with coding? If so, perhaps the best is just to fork the project, and make your own changes in the Unijoysticle platform... and if the changes are big, perhaps create your own platform.

mwedmark, 2022-01-31:
Ok thanks for taking the time and sharing all the info on adding these functions.  I'll give it a try to extend unijoystickle on separate fork and see where that takes me.

Coding should hopefully be ok since that has been my day job and hobby since 30 years back. I've done assembler, C/C++,C#, Basic, Pascal, ADA and others. I've tried platforms as: AVR, ARM/STM32, Propeller, 68000, 6502, DSPs, Z80, x86. I've also been doing FPGAs, creating my own CPUs, Graphics cores, tool chains/compilers. Lately I've been exploring creating/changing/building PCBs to extend my knowledge on that subject.

Closed 2022-01-31.

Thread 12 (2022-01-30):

WIFI/HTML configuration

mwedmark, 2022-01-30:
Has there been any though to adding HTML configuration page or is there a power budget reason to disable WIFI?

ricardoquesada, 2022-01-30:
power-wise, it will take more current...

But before discussing that, what things would you like to have configured via HTML/WiFi?
Perhaps there are alternative ways to do what you have in mind.

mwedmark, 2022-01-30:
OK yea I just though to optimize a little bit.. Everything That is switchable using buttons on-board or via buttons on joystick could be made clearer. May even some new good stuff could be added, Autofire and maybe something else..

ricardoquesada, 2022-01-30:
Yes, for changing the mappings, the plan is to enable a BLE (Bluetooth Low Energy) service, and let users change the mappings via their phones.

BTW: autofire is already supported... but changing the frequency of the autofire is one of the planned features to be added in the BLE configuration.

BLE vs WiFi:
 - less current
 - easier to connect to... no need to setup an AP or things like that.
 - Until recently it was not possible to have both WiFI and Bluetooth ATM, although I think it has been fixed.

mwedmark, 2022-01-31:
OK BLE sounds like a nice idea. Thank for you input on the idea.

Closed 2022-01-31.

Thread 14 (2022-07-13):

BOM

Nagytalp, 2022-07-13:
Hi,

may I use CH340G instead of "C" on 2+ version?
The differece betwwen the two is the "C" model have an built in cryctal oscillator but the "G" doesn't.

And I've stuck on recognise S8050 (Q1,Q2) NPN transistor. I found 6 different tipe  where the collector-emitter voltage is 25 V. But  collector current and the frequency are different.

https://www.tme.eu/hu/en/katalog/?search=s8050&s_field=1000011&s_order=desc

Wich is good for the build?

Thank you for your great work! I'm learning a lot from you.

Best regards,
Csaba.

ricardoquesada, 2022-07-13:
which schematic are you looking at ?

ricardoquesada, 2022-07-13:
ah... you said "2+".

So:

a) you cannot use CH340G. Use "B" or "C"
b) regarding S8050, try this one: https://www.tme.eu/hu/en/details/s8050-h-yan/npn-smd-transistors/yangjie-technology/s8050-h/

Closed 2022-07-13.

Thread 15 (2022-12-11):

Solution for supporting 4-player games on C64

mwedmark, 2022-12-11:
The userport can be used to get at least 2 more joysticks so it is possible to play 4-player games using one C64. There are several games that support this format. It would be nice if unijoysticle2 would support remapping against all 4 ports of the C64. May an extra optional add-on with a cable between Joysticks and userport or even cooler, another ESP-device as slave in userport that would talk to master in Joystick port and via network protocol handle the mapping between physical devices and C64 logical joysticks.

ricardoquesada, 2022-12-11:
another ESP32 device might be too complex. But an cable might  work.
Do you have a list of games that support 4 players?

mwedmark, 2022-12-11:
I think this WIKI is a good start. I'm not sure if it is 100% complete.
https://www.c64-wiki.com/wiki/Multiplayer_Interface#Multiplayer_Interface_Games

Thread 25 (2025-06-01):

Atari STFM/E support?

Sowden, 2025-06-01:
Hey there, this is more of a question than an issue.  But will your board fit in the underside cave underneath the machine?

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

Or will I need extensions in order to make it work?  And does this project use Blueretro firmware or a different type of own custom made Bluetooth firmware?  Sorry to create an issue, when there isn't really one!  Thanks.

ricardoquesada, 2025-06-01:
It needs extensions cables to be used in the Atari ST machines.
Uses Bluepad32 firmware.

Closed 2025-06-01.

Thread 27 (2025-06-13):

Feature request: Mouse emulation (1351) for the C64 Version of unijoystickle2

tvandorffy, 2025-06-13:
Hi guys,

This device is great! (Just received the C64 version and it works flawlessly.)
Any chance that the 1341 mouse emulation is going to be added at a future date for the C64 version of UniJoystickle 2?

Kind regards,

Tamas

ricardoquesada, 2025-06-13:
1351 emulation not possible with current hardware version.

I might (big might) develop a new version with 1351 support.

tvandorffy, 2025-06-13:
Hi,

I understand, thanks a lot for responding!

Kind regards,

Tamas

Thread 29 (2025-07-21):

Unijoystickle with Pico W or 2W

nanoant, 2025-07-21:
Since Pico W is now supported platform for BluePad32, I wanted to ask if there are any plans for new Unijoystickle (BluePad32 platform?) using Pico W or 2W instead of ESP32?

Pico W is apparently much more power efficient than ESP32, both due more power efficient ICs and also SMPS instead of voltage regulator instead LDO. While ESP32 uses approx. 100mA with BT on, Pico W is using approx. 40mA, so in principle it should meet all Amiga/C64/Atari joystick current limits. Also using Pico PIO it would be very convenient to "accelerate" Amiga quadrature mouse etc. Additionally Pico W supports both BT classic/EDR and BLE.

I know that your ESP32 based boards are pretty mature, and introducing yet another Pico board would be problematic from maintenance perspective, so I am just asking here.

Also I am running oldest Unijoysticle2 board with through hole SN74LS05N with my Amiga 500, connecting both joystick ports without external power supply. Everything works nice and stable.

According to my math with 4.7 Ohm resistor we would need more than 300 mA on single port to burn 1/2W resistors, so the voltage drop is what is more problematic here as e.g. SN74LS05N needs at least 4.75V for stable operation. So with 110mA max with box gamepads connected, powered through both joystick ports we would drop from 5V to 4.74V through both 4.7 Ohm resistors in theory (`5V−0.110A·4.7R/2`), and I already measured Vcc=4.85V with bench power supply connected directly to the board.

However everything seems to run nice and dandy with my Amiga 500 so I don't complain. I am only bit confused by "The Amiga 500 doesn't provide enough current to power the Unijoysticle" statement in [Unijoysticle User Guide](https://unijoysticle.readthedocs.io/en/latest/user_guide/).

I was using some BlueRetro single port ESP32 BT module in the past with my A500, and there indeed was a problem that ESP32 BT was drawing 400mA for about 20-30ms (during BT startup) and with single port voltage drop was too high so this module was failing to initialize itself most of the time, not to mention the risk of burning the resistor drawing 400mA for 30ms. So I stopped using it.

Finally, thank you for this amazing project and all the great work!

ricardoquesada, 2025-07-24:
good call.

I'll take that into account for future versions.

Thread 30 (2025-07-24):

Stop using AMS1117

ricardoquesada, 2025-07-24:
See: https://www.reddit.com/r/esp32/comments/1m7ne4i/psa_avoid_using_the_ams1117_ldo_for_esp32_projects/

In case the link disappears:

if you’re designing a board with an ESP32 (or any low-voltage logic), stop using the AMS1117 LDO. Here’s why, and what you should use instead.

The Problems with the AMS1117
I recent project that I reviewed highlighted critical flaws in the AMS1117, especially for USB-powered or high-input-voltage projects:

High Dropout Voltage Causes Instability

The AMS1117 only specifies a min 1.0V dropout (Vin must be at least Vout + 1.0V). But in practice I have seen them have >1.5V at only 0.3A (WiFi packets can easily cause this on the esp32). With long or low-quality USB cables the 5V from USB can easily drop to 4.5V and at that point the AMS1117 can cause the output 3.3V to drop below 3V and cause instability, brownouts, shutdowns or even cause the the chip to lockup until it is fully reset.

Thermal Nightmares at high input voltages

At 12V→3.3V, it dissipates ~8.7V * I_load. Even at 200mA, that’s 1.7W – enough to fry the SOT-223 package without a significant heatsink.

Stability Issues with ceramic capacitors

Datasheet requires specific output capacitors (e.g., 22µF tantalum) with precise ESR. Modern MLCCs (low ESR) can cause oscillation, leading to overvoltage or erratic behavior.

What to Use Instead
Switch to modern LDOs or buck converters:

XC6220 (or similar):

Dropout voltage is [60mV@0.3A](mailto:60mV@0.3A) (vs. ~1.5V!).

Stable with tiny MLCCs (10µF+), no ESR headaches.

Ideal for USB-powered projects where 5V→3.3V is common.

AP2112/AP2114:

Cheap, robust, and widely available. Handles 0.6A with better thermal performance.

Buck Converters (for high Vin→Vout differential):

Use modules like TPS63070 or even the old LM2596 for 12V→3.3V/5V. Saves power and avoids heat.

Lessons from the Trenches
Always check the dropout voltage for your Vin/Vout.

Err on the side of more capacitors (100-200µF) to dampen transients.

Thermal design matters: Calculate power dissipation and use large copper pours.

Avoid AliExpress/Ebay regulators – fakes are rampant. Buy from reputable distributors.

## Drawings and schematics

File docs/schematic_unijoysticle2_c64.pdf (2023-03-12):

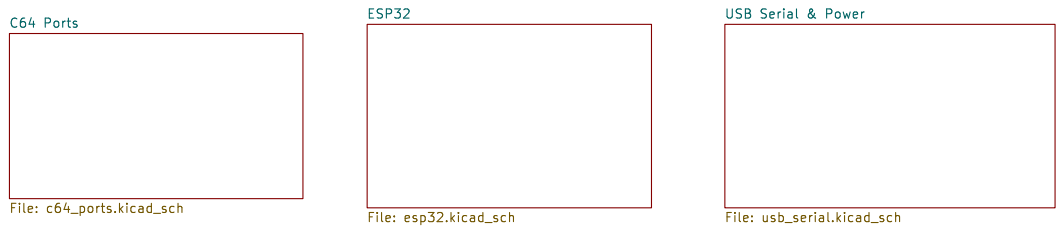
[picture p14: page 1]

File: unijoysticle2_c64.kicad_sch Sheet: / Ricardo Quesada

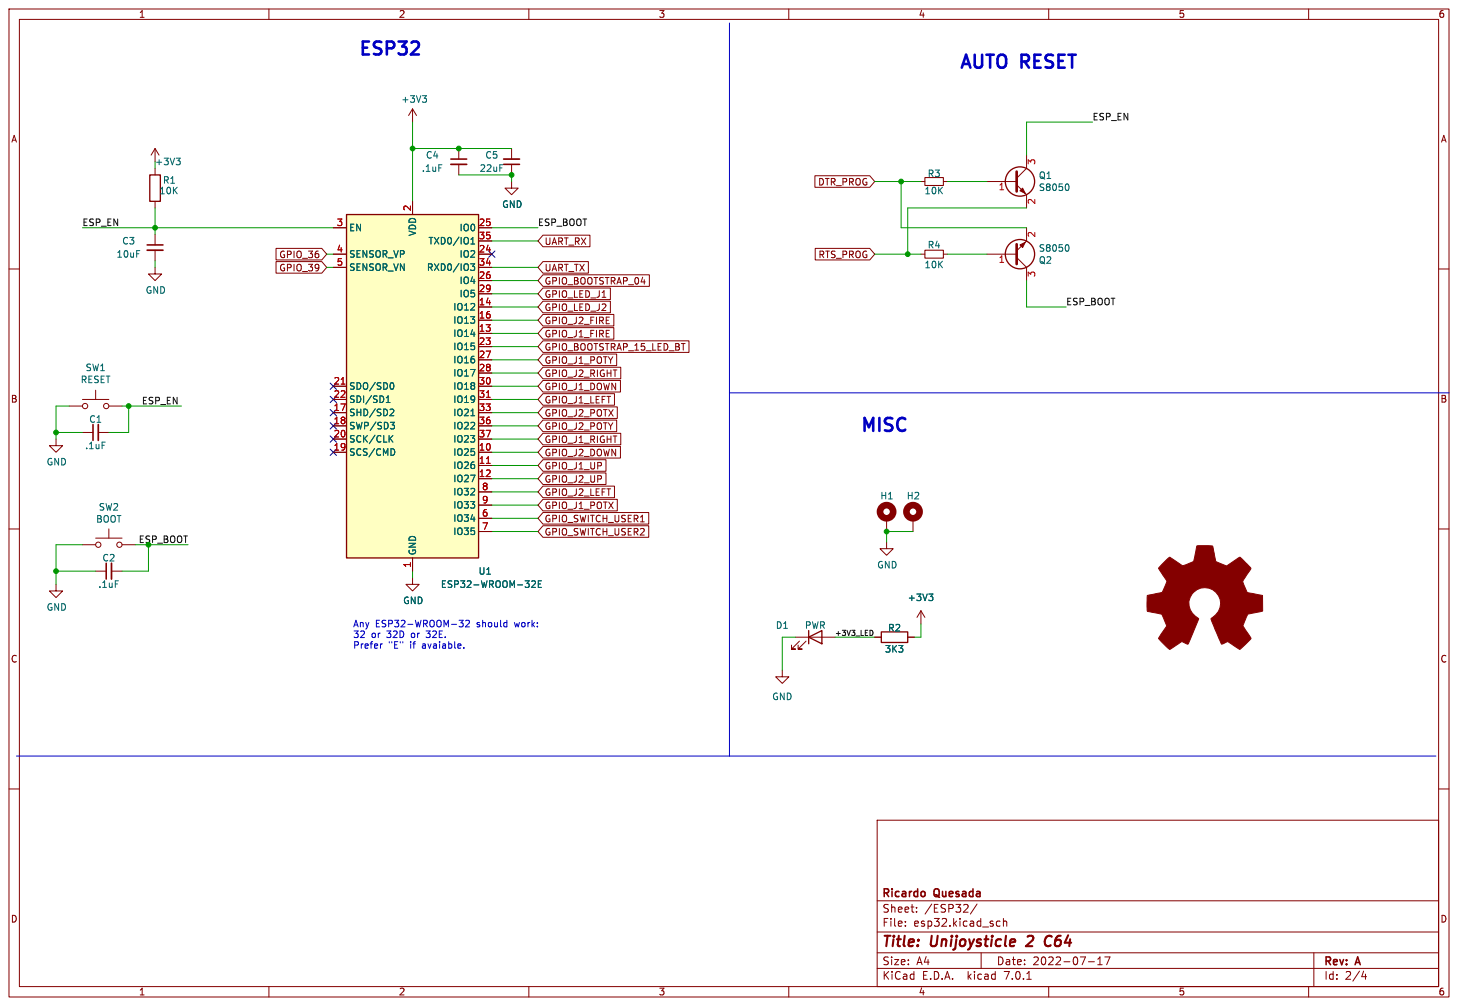
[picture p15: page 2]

2 SCK/CLK 20 SDO/SD0 21 SDI/SD1 22

File: esp32.kicad_sch Sheet: /ESP32/ Ricardo Quesada GND

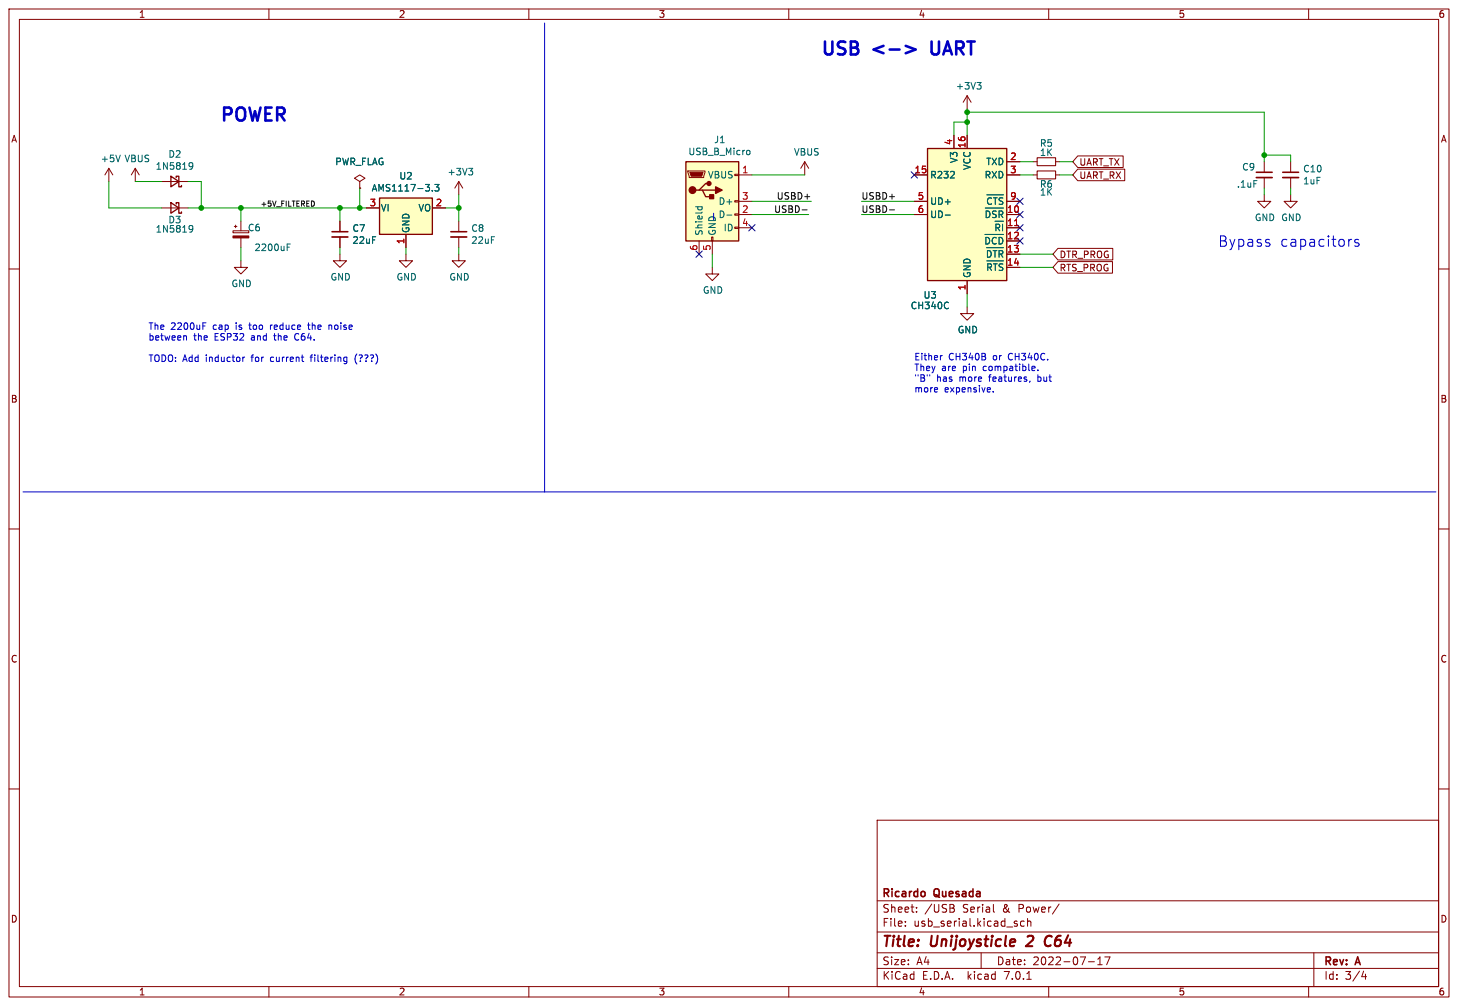
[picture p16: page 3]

1 ~{DSR} 10 ~{RI} 11 ~{DCD} 12 ~{DTR} 13 ~{RTS} 14 R232 15 VCC 16 TXD 2 RXD 3 V3

4 UD+ 5 UD- 6 ~{CTS}9 GND

The 2200uF cap is too reduce the noise

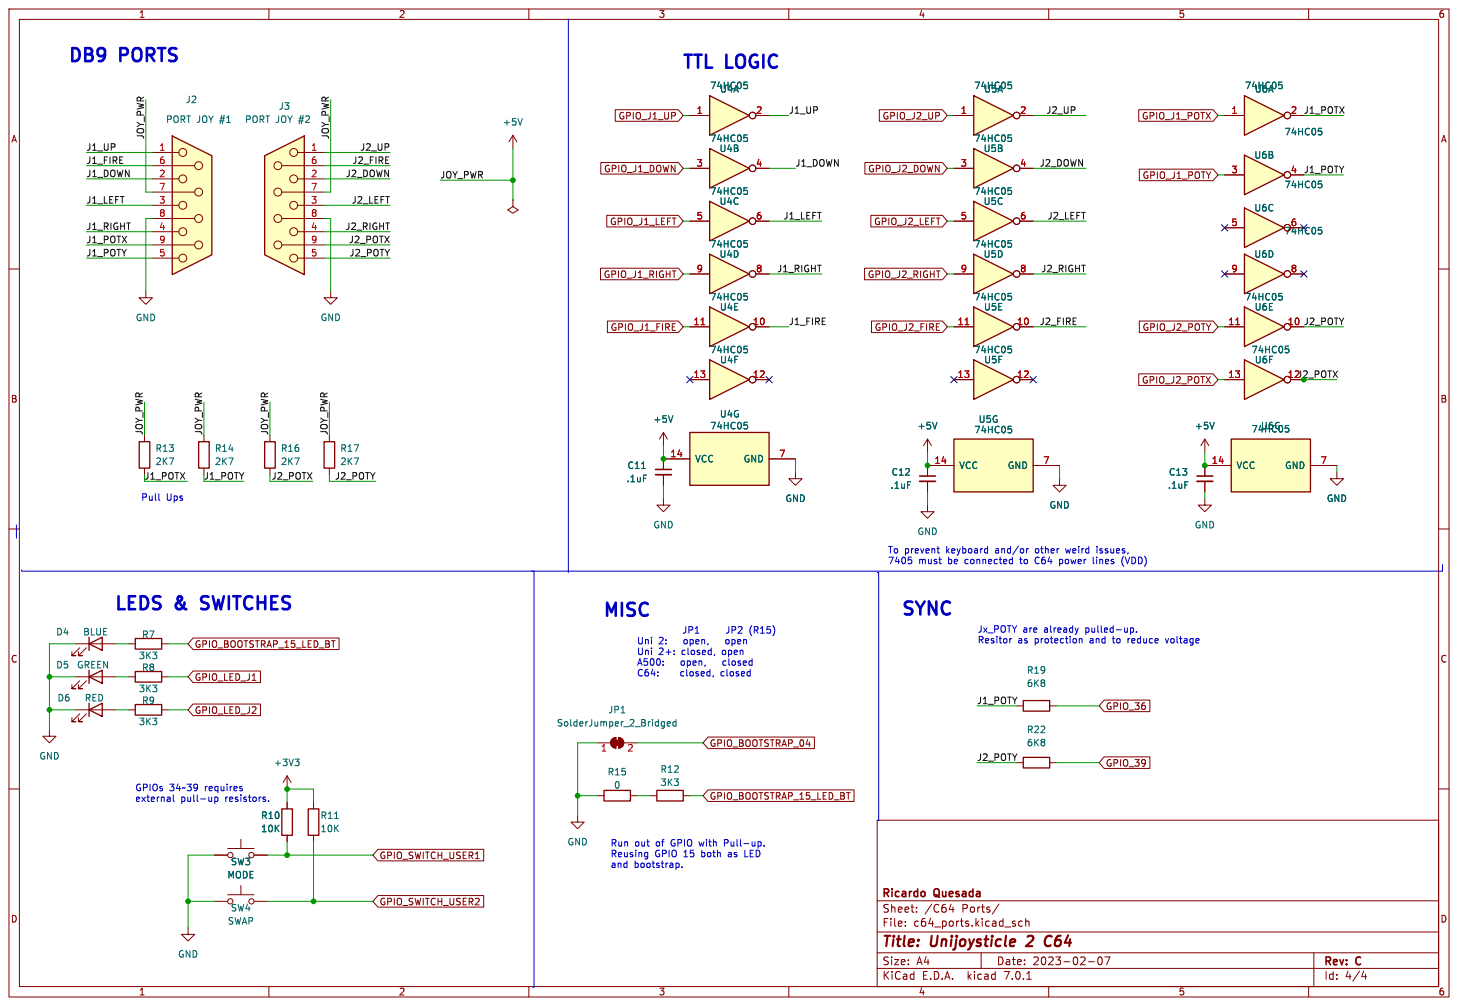
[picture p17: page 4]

Run out of GPIO with Pull-up.
Reusing GPIO 15 both as LED
and bootstrap.

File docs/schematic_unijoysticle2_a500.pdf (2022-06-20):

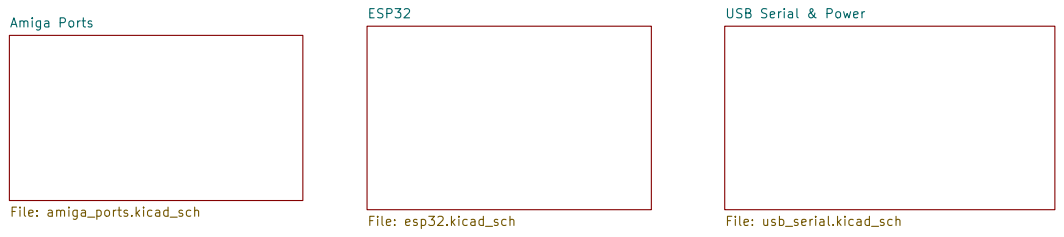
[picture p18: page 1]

File: unijoysticle2_a500.kicad_sch Sheet: / Ricardo Quesada

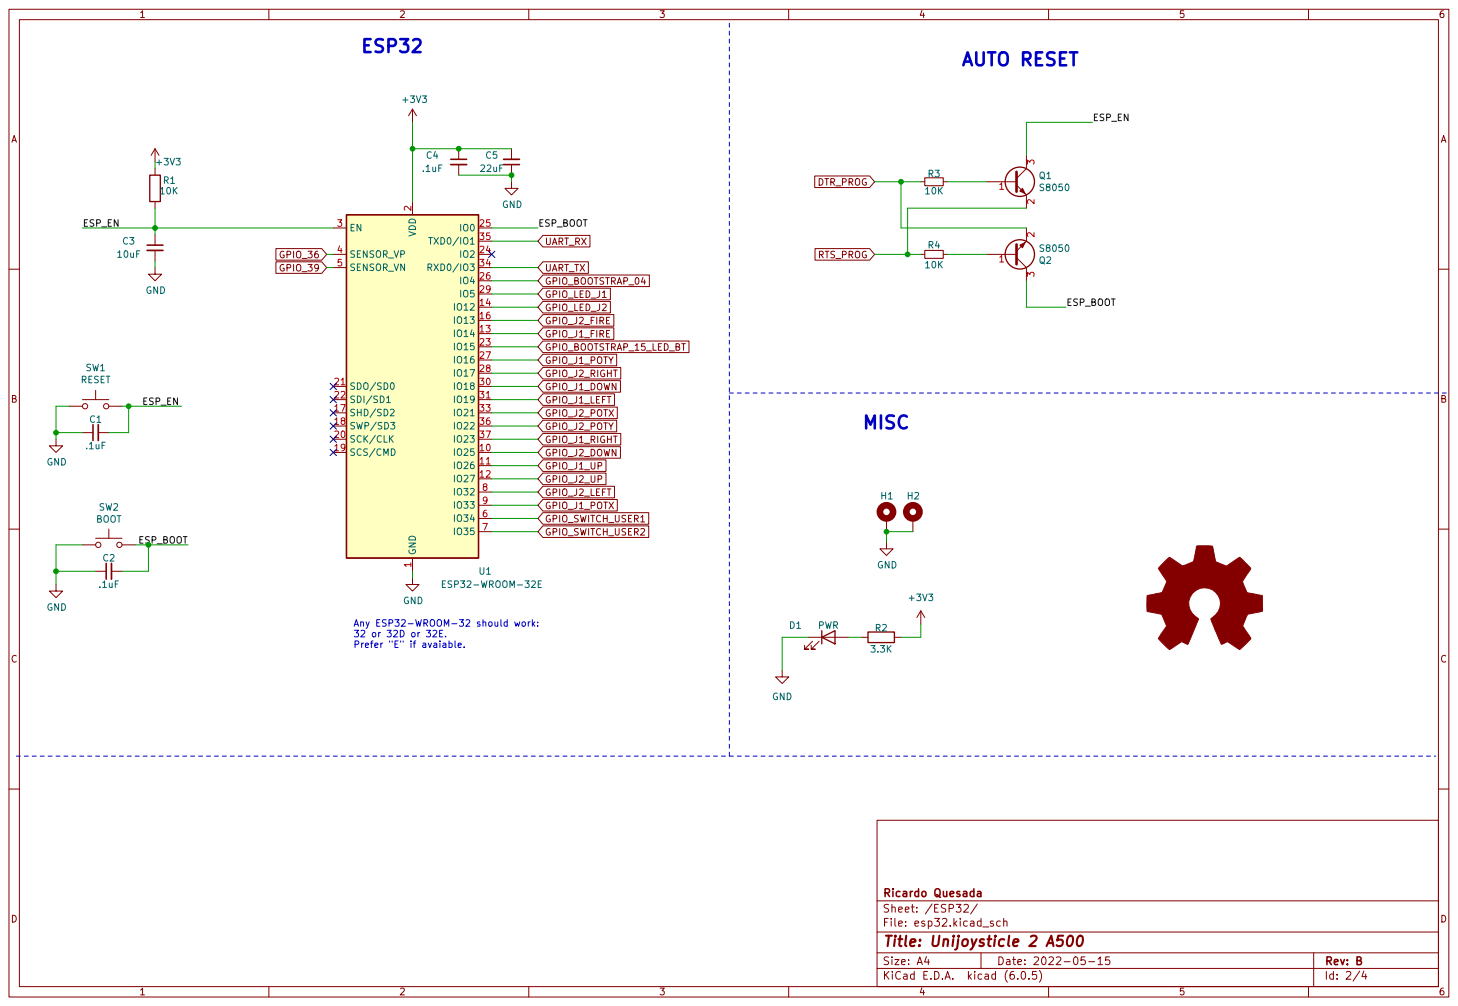
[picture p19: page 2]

2 SCK/CLK 20 SDO/SD0 21 SDI/SD1 22

File: esp32.kicad_sch Sheet: /ESP32/ Ricardo Quesada

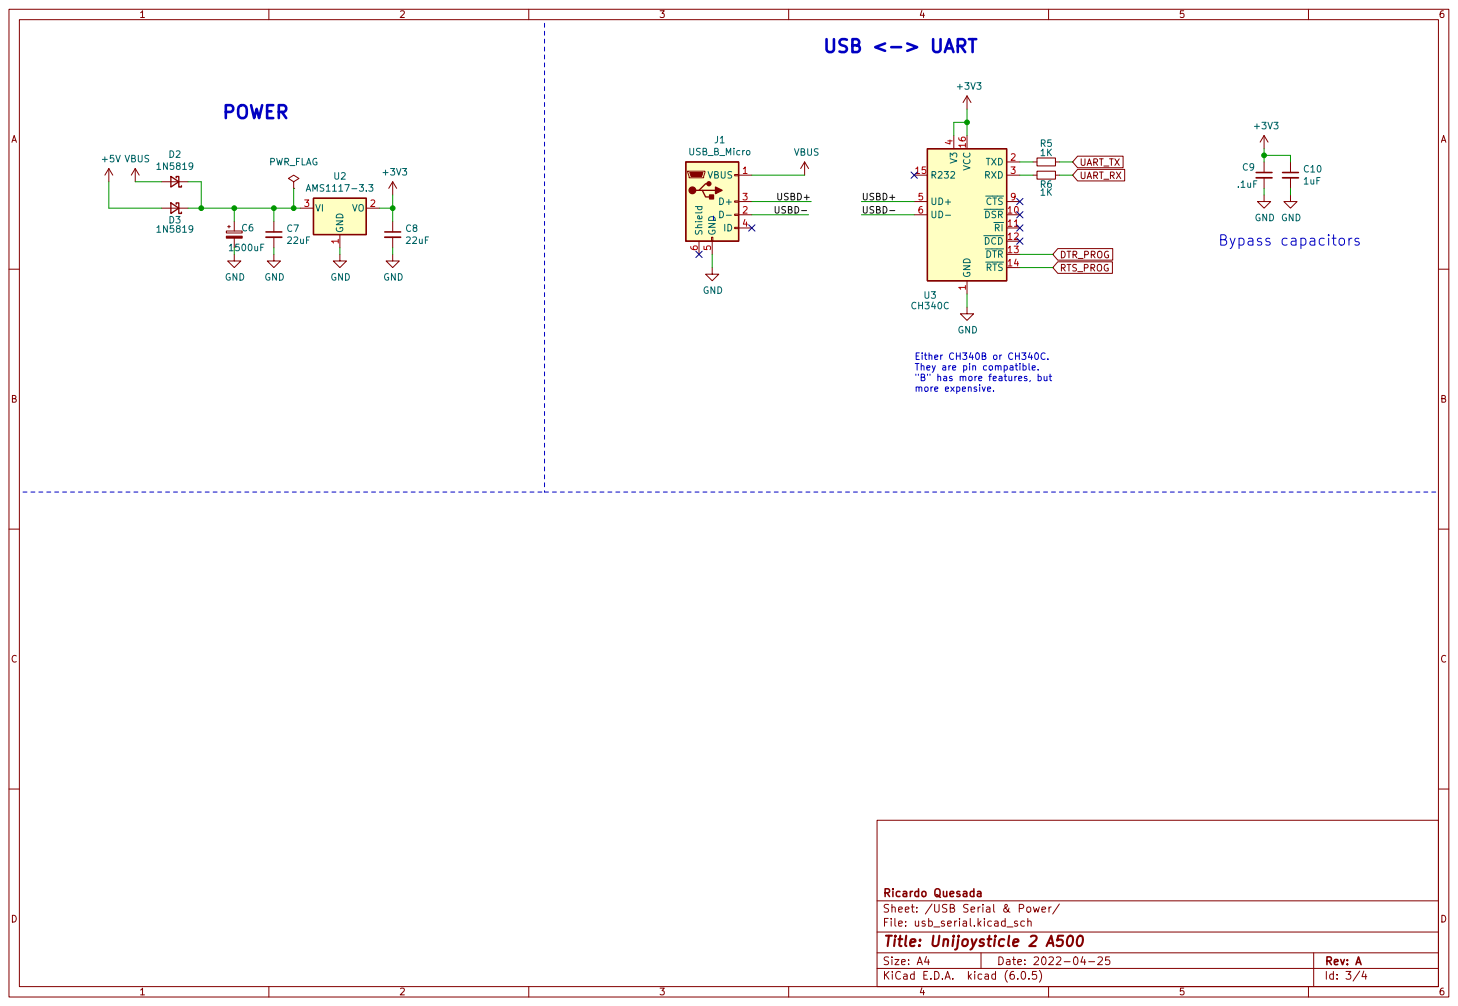
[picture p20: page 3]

1 ~{DSR}10 ~{RI}11 ~{DCD}12 ~{DTR}13 ~{RTS}14 R232 15 VCC 16 TXD 2 RXD 3 V3

4 UD+ 5 UD- 6 ~{CTS} 9 U3 CH340C GND

1 VO 2 VI 3 U2 AMS1117-3.3 GND GND

Either CH340B or CH340C. They are pin compatible. "B" has more features, but more expensive.

File: usb_serial.kicad_sch Sheet: /USB Serial & Power/ Ricardo Quesada

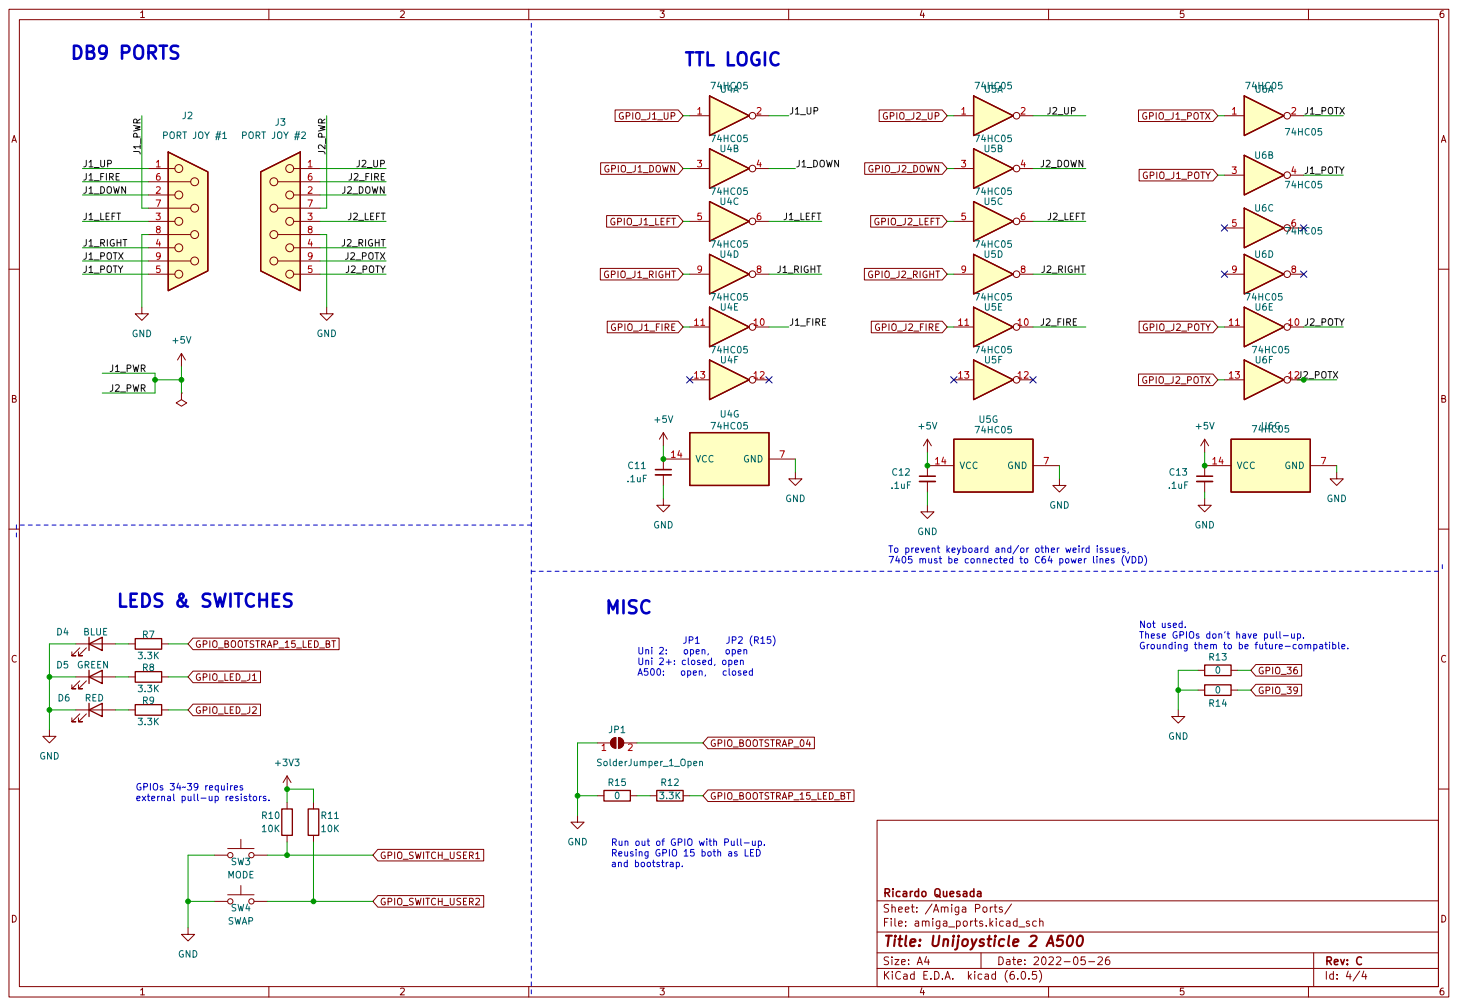
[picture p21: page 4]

To prevent keyboard and/or other weird issues,
7405 must be connected to C64 power lines (VDD)

Not used. These GPIOs don't have pull-up.

Grounding them to be future-compatible.

GPIOs 34~39 requires
external pull-up resistors.

Run out of GPIO with Pull-up.
Reusing GPIO 15 both as LED
and bootstrap.

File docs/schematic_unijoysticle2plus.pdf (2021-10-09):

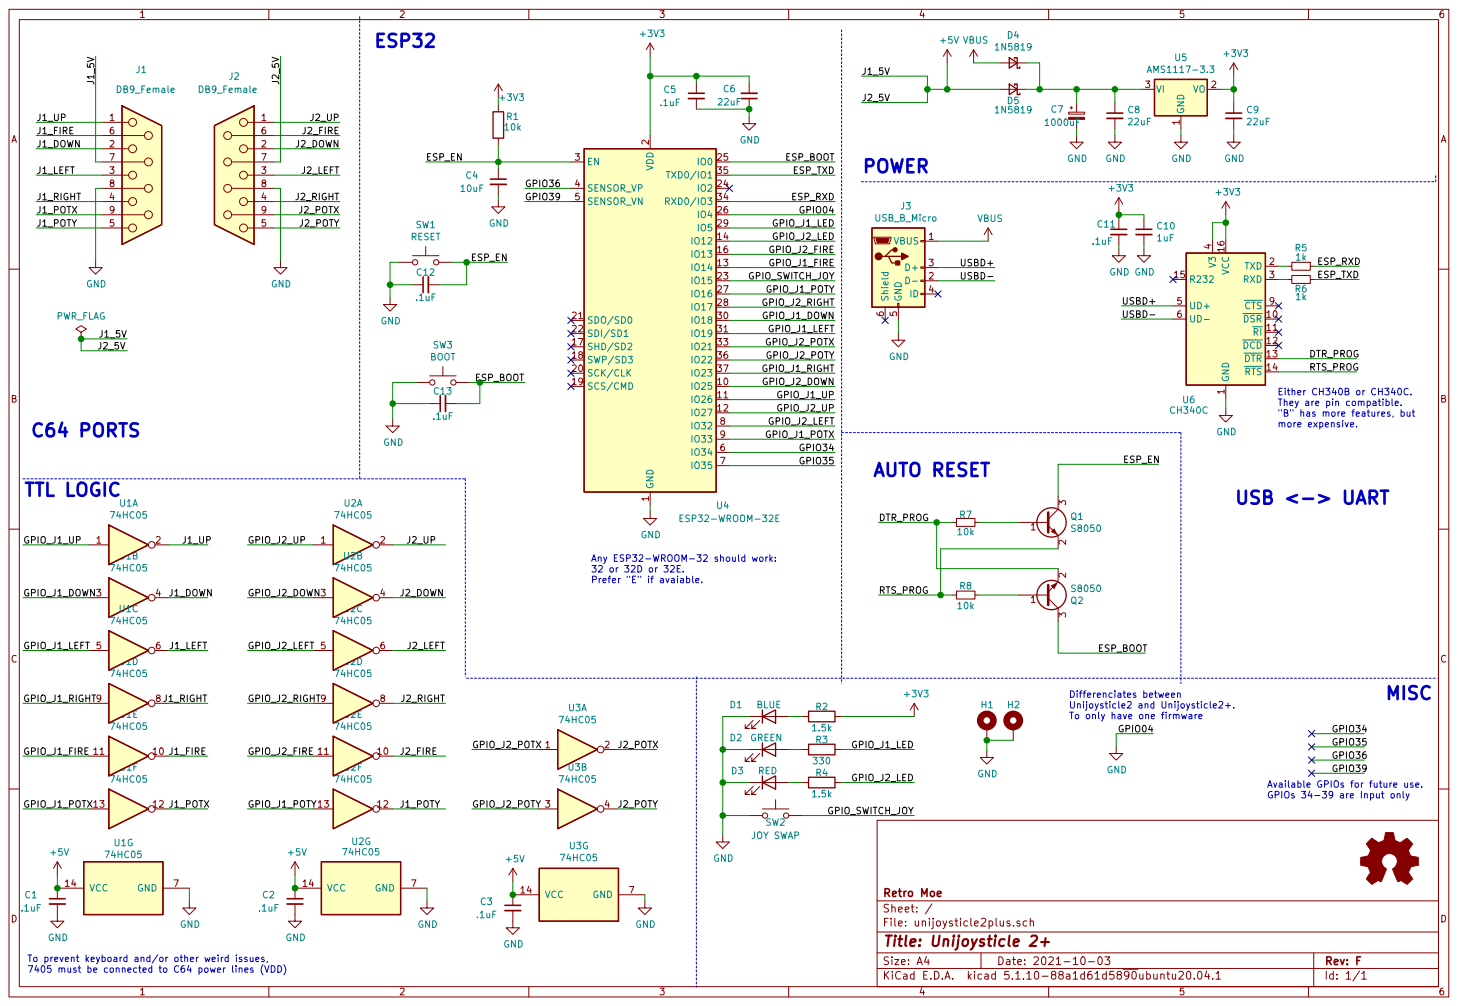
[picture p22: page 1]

2 SCK/CLK 20 SDO/SD0 21 SDI/SD1 22

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

4 UD+ 5 UD- 6 CTS 9 U6 CH340C GND

Either CH340B or CH340C. They are pin compatible. "B" has more features, but more expensive.

To only have one firmware

File: unijoysticle2plus.sch Sheet: / Retro Moe

To prevent keyboard and/or other weird issues,

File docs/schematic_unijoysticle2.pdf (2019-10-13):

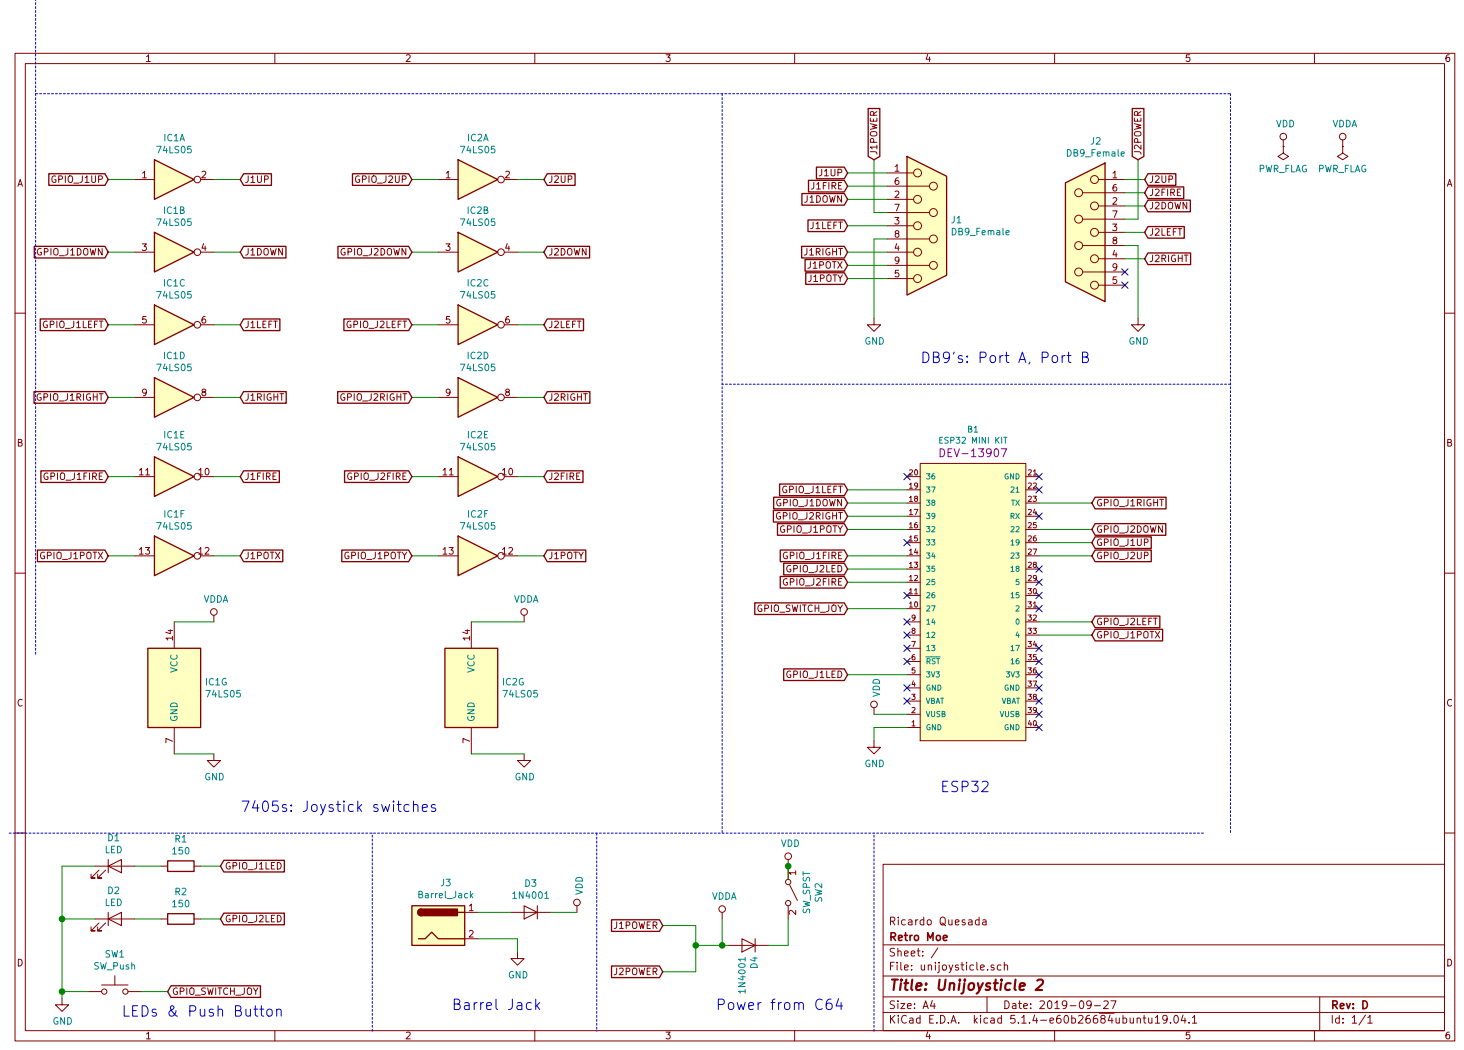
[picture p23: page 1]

File: unijoysticle.sch Sheet: / Retro Moe Ricardo Quesada VDD

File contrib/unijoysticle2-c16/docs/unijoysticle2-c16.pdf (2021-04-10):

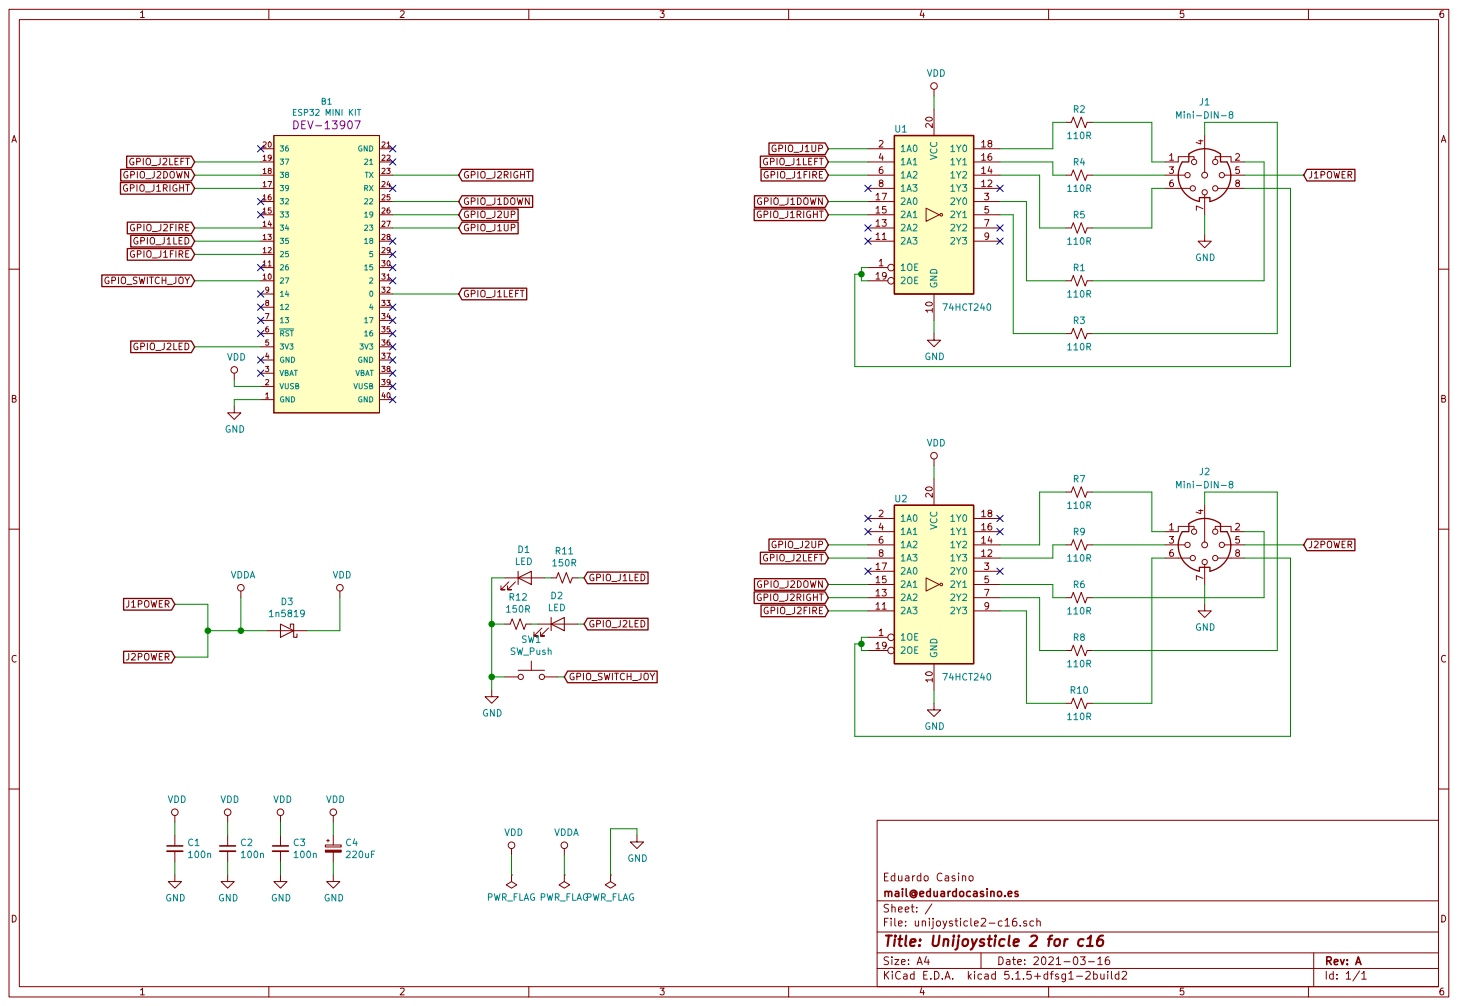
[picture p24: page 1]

File: unijoysticle2-c16.sch Sheet: / mail@eduardocasino.es Eduardo Casino VDD

Id: 1/1 Title: Unijoysticle 2 for c16

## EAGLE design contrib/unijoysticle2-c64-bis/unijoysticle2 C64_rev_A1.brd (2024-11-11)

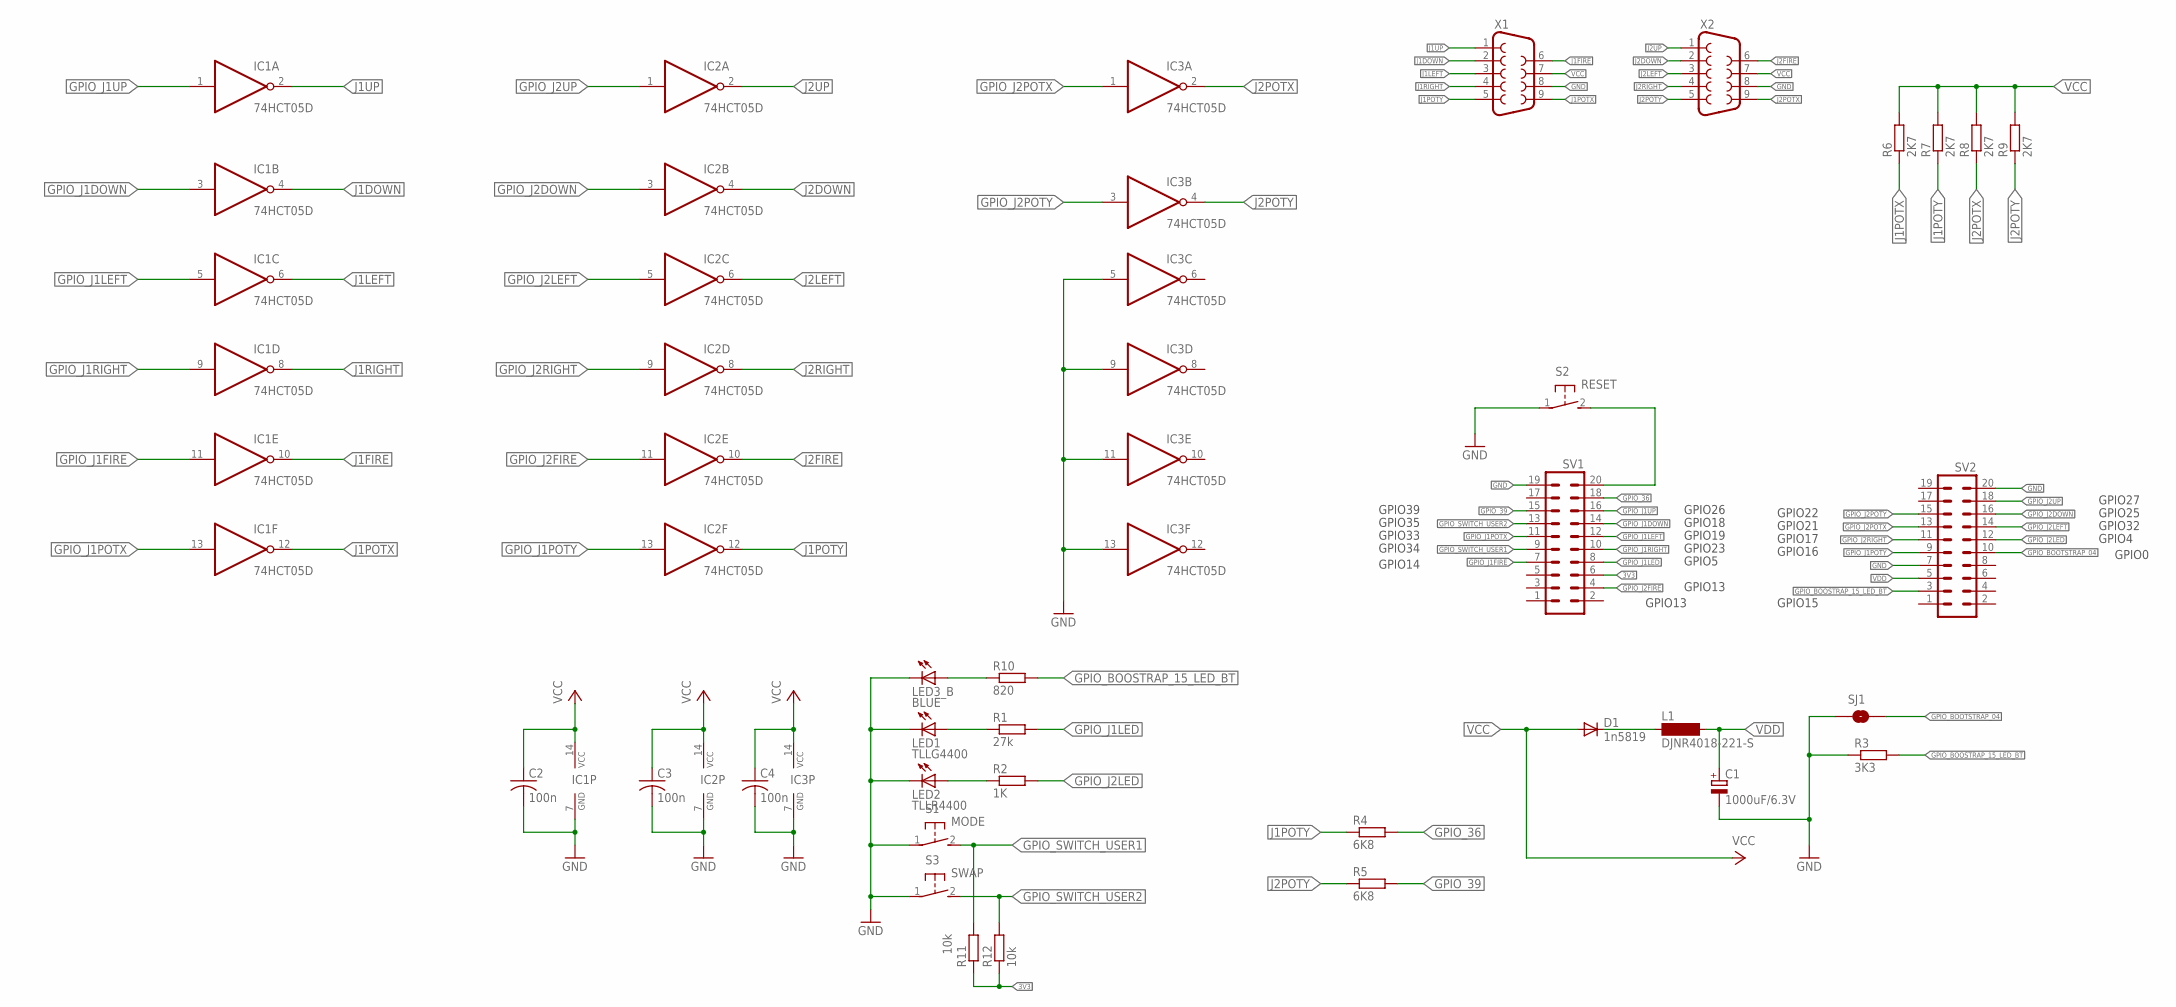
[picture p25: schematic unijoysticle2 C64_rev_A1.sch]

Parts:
C1: 1000uF/6.3V; 140CLH-1010
C2, C3, C4: 100n; C0805K
D1: 1n5819; DO214AC
IC1, IC2, IC3: 74HCT05D; SO14
L1: DJNR4018-221-S; SM-NE45
LED1: TLLG4400; LED3MM
LED2: TLLR4400; LED3MM
LED3_B: BLUE; LED3MM
R1: 27k; M0805
R2: 1K; M0805
R3: 3K3; M0805
R4, R5: 6K8; M0805
R6, R7, R8, R9: 2K7; M0805
R10: 820; M0805
R11, R12: 10k; M0805
S1: MODE; B3F-31XX
S2: RESET; B3F-31XX
S3: SWAP; B3F-31XX
SJ1: SOLDERJUMPERTRACE; SJ_2S-TRACE
SV1, SV2: MA10-2
X1, X2: DB9

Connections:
3V3: R11.1, R12.1, SV1.6
GND: C1.-, C2.2, C3.2, C4.2, IC1.7 (GND), IC2.7 (GND), IC3.5 (I), IC3.7 (GND), IC3.9 (I), IC3.11 (I), IC3.13 (I), LED1.K (C), LED2.K (C), LED3_B.K (C), R3.1, S1.1, S2.1, S3.1, SJ1.1, SV1.19, SV2.7, SV2.20, X1.8, X2.8
GPIO_36: R4.2, SV1.18
GPIO_39: R5.2, SV1.15
GPIO_BOOSTRAP_15_LED_BT: R3.2, R10.2, SV2.3
GPIO_BOOTSTRAP_04: SJ1.2, SV2.10
GPIO_J1DOWN: IC1.3 (I), SV1.14
GPIO_J1FIRE: IC1.11 (I), SV1.7
GPIO_J1LED: R1.2, SV1.8
GPIO_J1LEFT: IC1.5 (I), SV1.12
GPIO_J1POTX: IC1.13 (I), SV1.11
GPIO_J1POTY: IC2.13 (I), SV2.9
GPIO_J1RIGHT: IC1.9 (I), SV1.10
GPIO_J1UP: IC1.1 (I), SV1.16
GPIO_J2DOWN: IC2.3 (I), SV2.16
GPIO_J2FIRE: IC2.11 (I), SV1.4
GPIO_J2LED: R2.2, SV2.12
GPIO_J2LEFT: IC2.5 (I), SV2.14
GPIO_J2POTX: IC3.1 (I), SV2.13
GPIO_J2POTY: IC3.3 (I), SV2.15
GPIO_J2RIGHT: IC2.9 (I), SV2.11
GPIO_J2UP: IC2.1 (I), SV2.18
GPIO_SWITCH_USER1: R11.2, S1.2 (S), SV1.9
GPIO_SWITCH_USER2: R12.2, S3.2 (S), SV1.13
J1DOWN: IC1.4 (O), X1.2
J1FIRE: IC1.10 (O), X1.6
J1LEFT: IC1.6 (O), X1.3
J1POTX: IC1.12 (O), R6.1, X1.9
J1POTY: IC2.12 (O), R4.1, R7.1, X1.5
J1RIGHT: IC1.8 (O), X1.4
J1UP: IC1.2 (O), X1.1
J2DOWN: IC2.4 (O), X2.2
J2FIRE: IC2.10 (O), X2.6
J2LEFT: IC2.6 (O), X2.3
J2POTX: IC3.2 (O), R8.1, X2.9
J2POTY: IC3.4 (O), R5.1, R9.1, X2.5
J2RIGHT: IC2.8 (O), X2.4
J2UP: IC2.2 (O), X2.1
unnamed: LED1.A, R1.1
unnamed: LED2.A, R2.1
unnamed: S2.2 (S), SV1.20
unnamed: LED3_B.A, R10.1
unnamed: D1.C, L1.1
VCC: C2.1, C3.1, C4.1, D1.A, IC1.14 (VCC), IC2.14 (VCC), IC3.14 (VCC), R6.2, R7.2, R8.2, R9.2, X1.7, X2.7
VDD: C1.+, L1.2, SV2.5

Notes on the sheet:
GPIO35
GPIO33
GPIO34
GPIO14
GPIO39
GPIO26
GPIO18
GPIO19
GPIO23
GPIO5
GPIO13
GPIO27
GPIO25
GPIO32
GPIO4
GPIO0
GPIO22
GPIO21
GPIO17
GPIO16
GPIO15

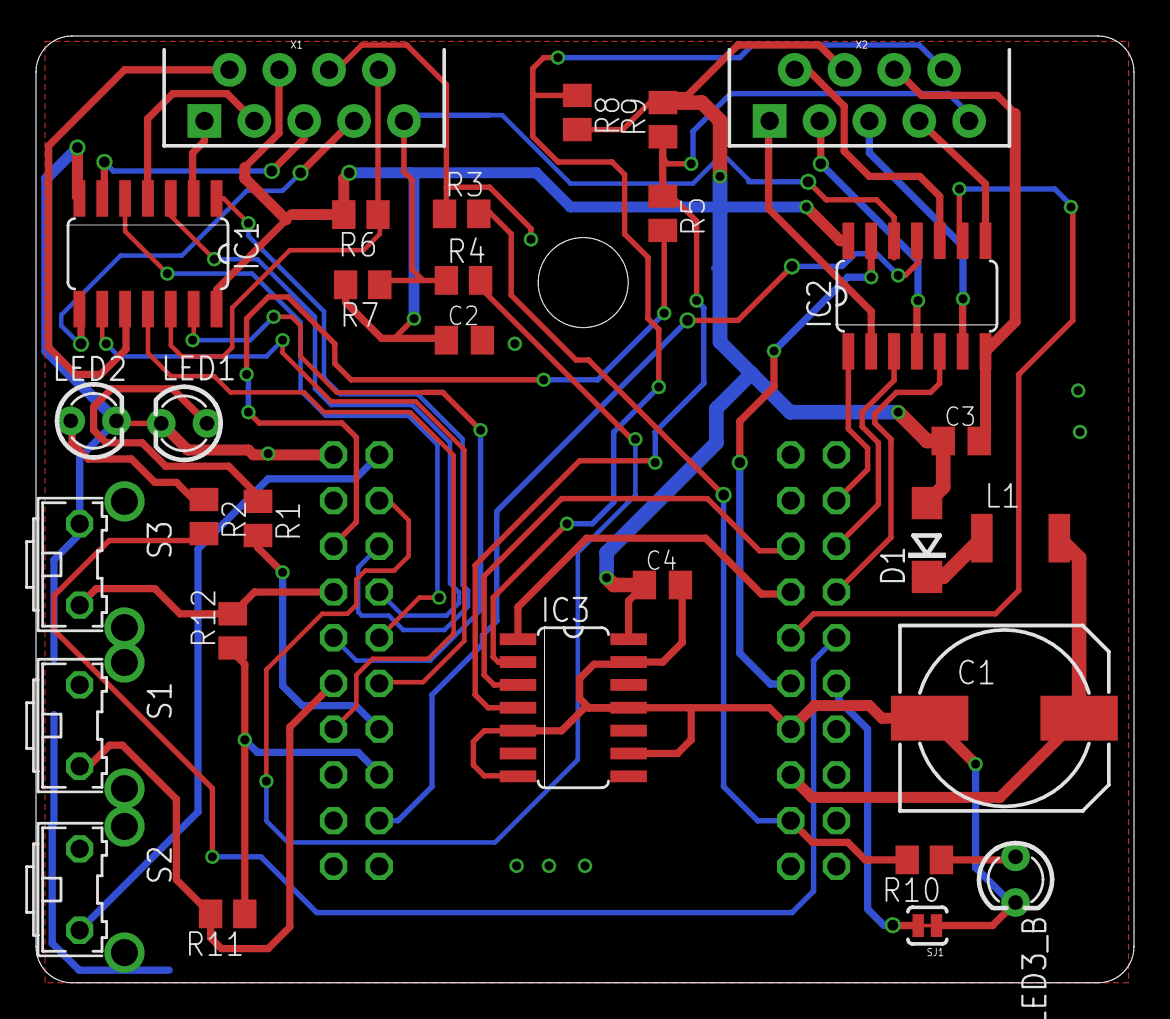
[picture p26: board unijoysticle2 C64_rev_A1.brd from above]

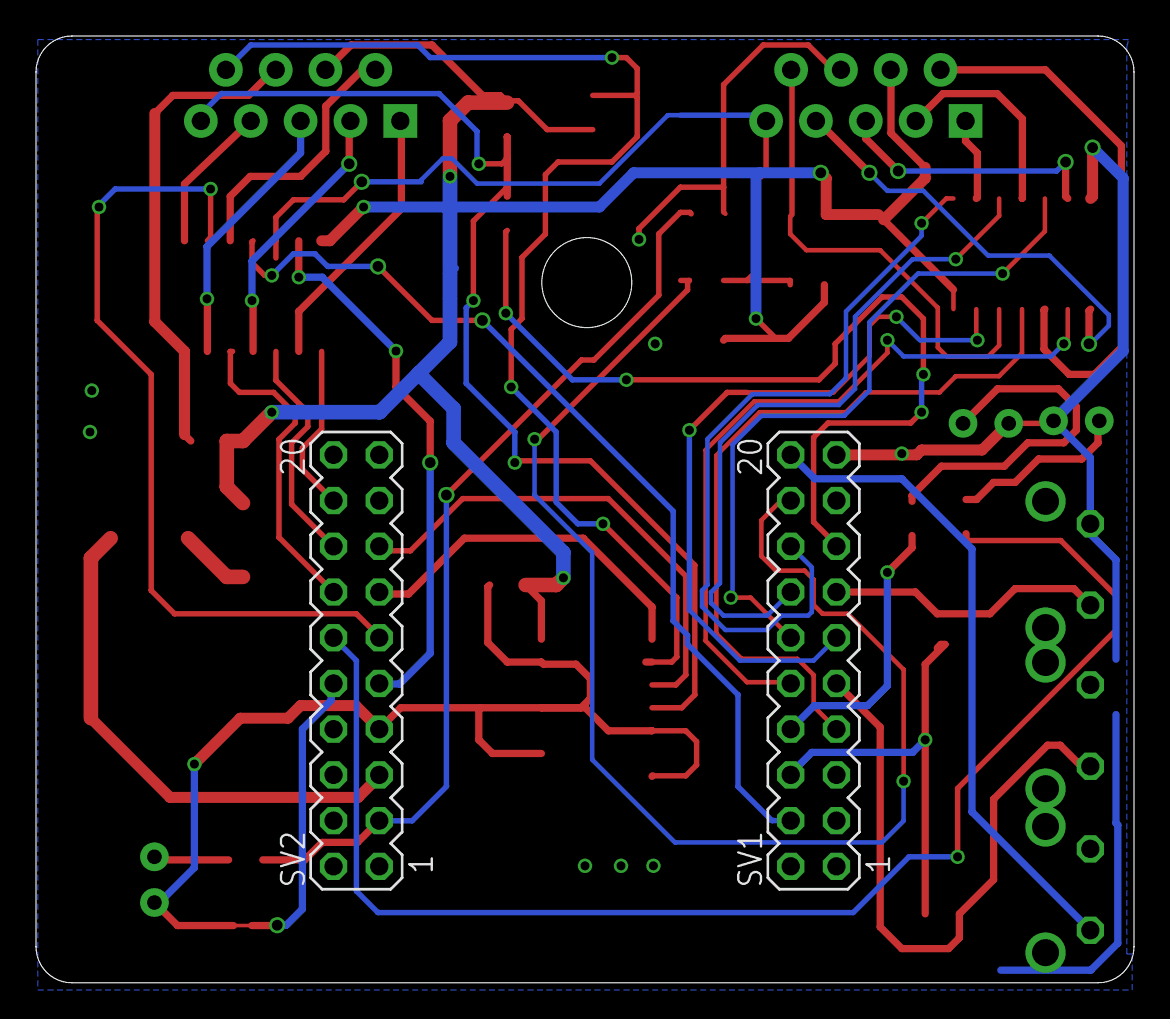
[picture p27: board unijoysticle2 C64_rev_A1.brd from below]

Board: 2 copper layers, 61.0 x 52.6 mm, 32 parts (2 on the bottom side), 45 nets.

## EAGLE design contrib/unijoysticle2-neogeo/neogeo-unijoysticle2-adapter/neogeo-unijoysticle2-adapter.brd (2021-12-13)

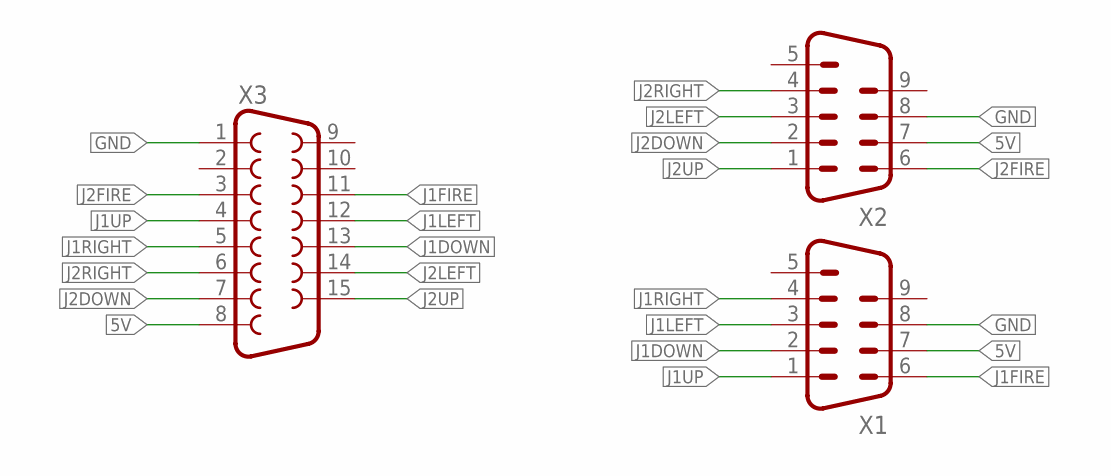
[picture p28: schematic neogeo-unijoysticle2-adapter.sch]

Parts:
X1, X2: M09D
X3: F15D

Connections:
5V: X1.7, X2.7, X3.8
GND: X1.8, X2.8, X3.1
J1DOWN: X1.2, X3.13
J1FIRE: X1.6, X3.11
J1LEFT: X1.3, X3.12
J1RIGHT: X1.4, X3.5
J1UP: X1.1, X3.4
J2DOWN: X2.2, X3.7
J2FIRE: X2.6, X3.3
J2LEFT: X2.3, X3.14
J2RIGHT: X2.4, X3.6
J2UP: X2.1, X3.15

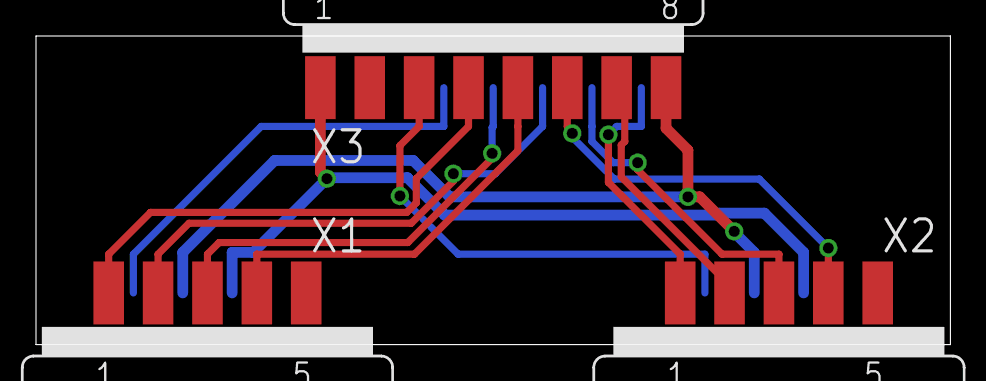
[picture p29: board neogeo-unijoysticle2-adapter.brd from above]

Board: 2 copper layers, 50.8 x 17.1 mm, 3 parts (0 on the bottom side), 12 nets.

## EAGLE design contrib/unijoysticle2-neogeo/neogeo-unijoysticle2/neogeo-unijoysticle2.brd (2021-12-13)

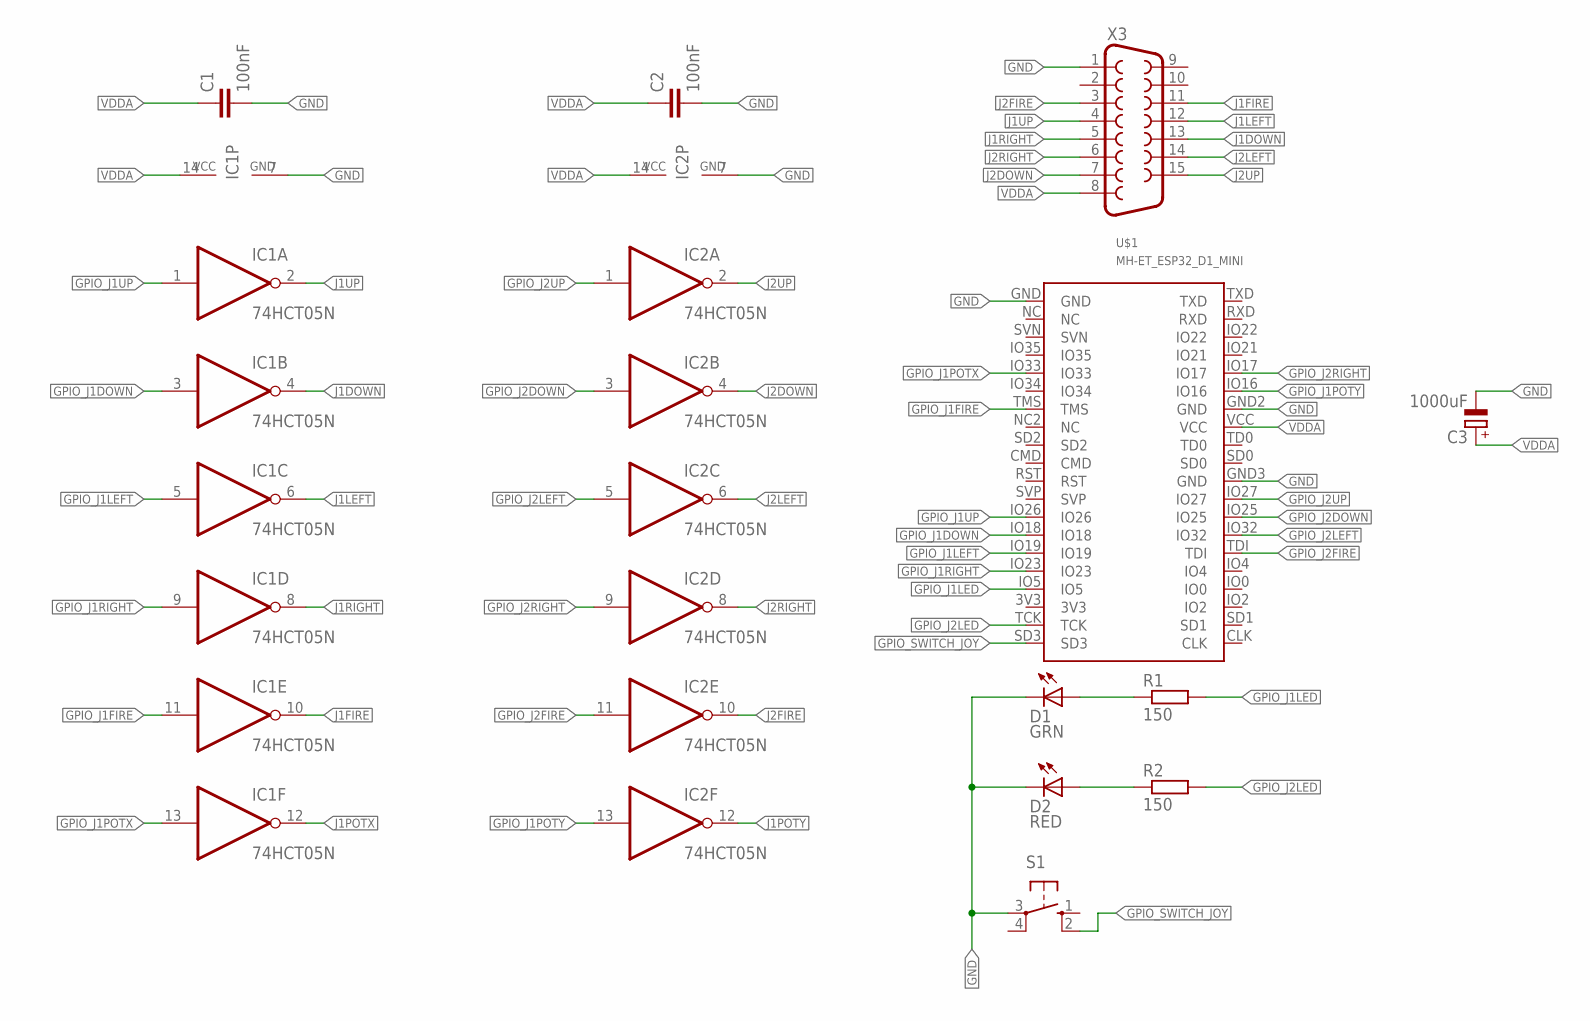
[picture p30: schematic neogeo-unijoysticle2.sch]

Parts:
C1, C2: 100nF; C025-025X050
C3: 1000uF; E2,5-6E
D1: GRN; LED3MM
D2: RED; LED3MM
IC1, IC2: 74HCT05N; DIL14
R1, R2: 150; 0207/7
S1: 10-XX; B3F-10XX
U$1: MH-ET_ESP32_D1_MINI
X3: F15HP

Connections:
GND: C1.2, C2.2, C3.-, D1.K (C), D2.K (C), IC1.7 (GND), IC2.7 (GND), S1.3, U$1.GND, U$1.GND2 (GND), U$1.GND3 (GND), X3.1
GPIO_J1DOWN: IC1.3 (I), U$1.IO18
GPIO_J1FIRE: IC1.11 (I), U$1.TMS
GPIO_J1LED: R1.2, U$1.IO5
GPIO_J1LEFT: IC1.5 (I), U$1.IO19
GPIO_J1POTX: IC1.13 (I), U$1.IO33
GPIO_J1POTY: IC2.13 (I), U$1.IO16
GPIO_J1RIGHT: IC1.9 (I), U$1.IO23
GPIO_J1UP: IC1.1 (I), U$1.IO26
GPIO_J2DOWN: IC2.3 (I), U$1.IO25
GPIO_J2FIRE: IC2.11 (I), U$1.TDI
GPIO_J2LED: R2.2, U$1.TCK
GPIO_J2LEFT: IC2.5 (I), U$1.IO32
GPIO_J2RIGHT: IC2.9 (I), U$1.IO17
GPIO_J2UP: IC2.1 (I), U$1.IO27
GPIO_SWITCH_JOY: S1.2 (S1), U$1.SD3
J1DOWN: IC1.4 (O), X3.13
J1FIRE: IC1.10 (O), X3.11
J1LEFT: IC1.6 (O), X3.12
J1POTX: IC1.12 (O)
J1POTY: IC2.12 (O)
J1RIGHT: IC1.8 (O), X3.5
J1UP: IC1.2 (O), X3.4
J2DOWN: IC2.4 (O), X3.7
J2FIRE: IC2.10 (O), X3.3
J2LEFT: IC2.6 (O), X3.14
J2RIGHT: IC2.8 (O), X3.6
J2UP: IC2.2 (O), X3.15
unnamed: D1.A, R1.1
unnamed: D2.A, R2.1
VDDA: C1.1, C2.1, C3.+, IC1.14 (VCC), IC2.14 (VCC), U$1.VCC, X3.8

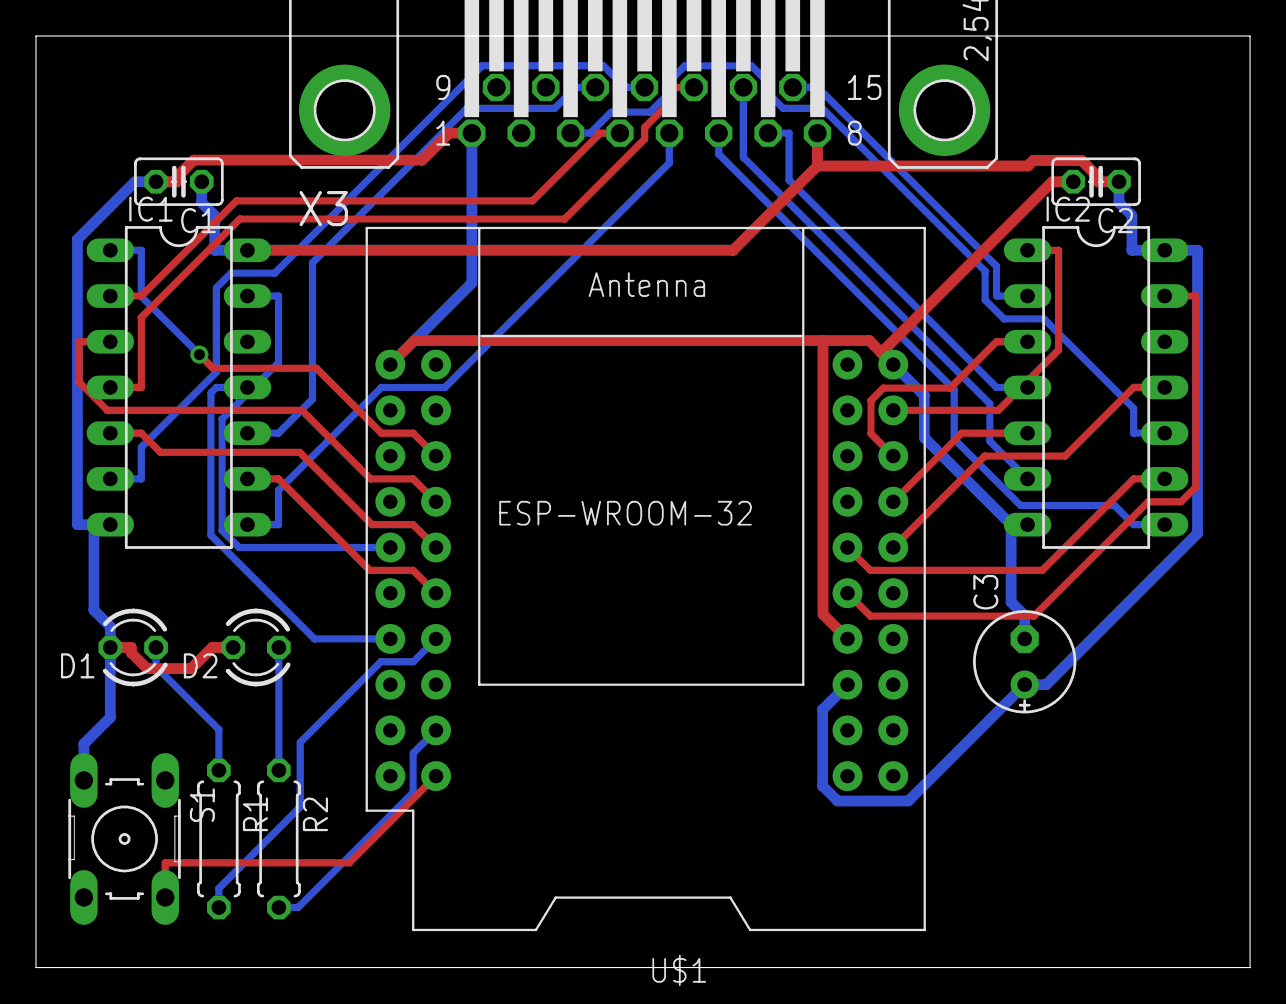
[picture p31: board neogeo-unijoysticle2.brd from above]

Board: 2 copper layers, 67.4 x 51.8 mm, 12 parts (0 on the bottom side), 29 nets.

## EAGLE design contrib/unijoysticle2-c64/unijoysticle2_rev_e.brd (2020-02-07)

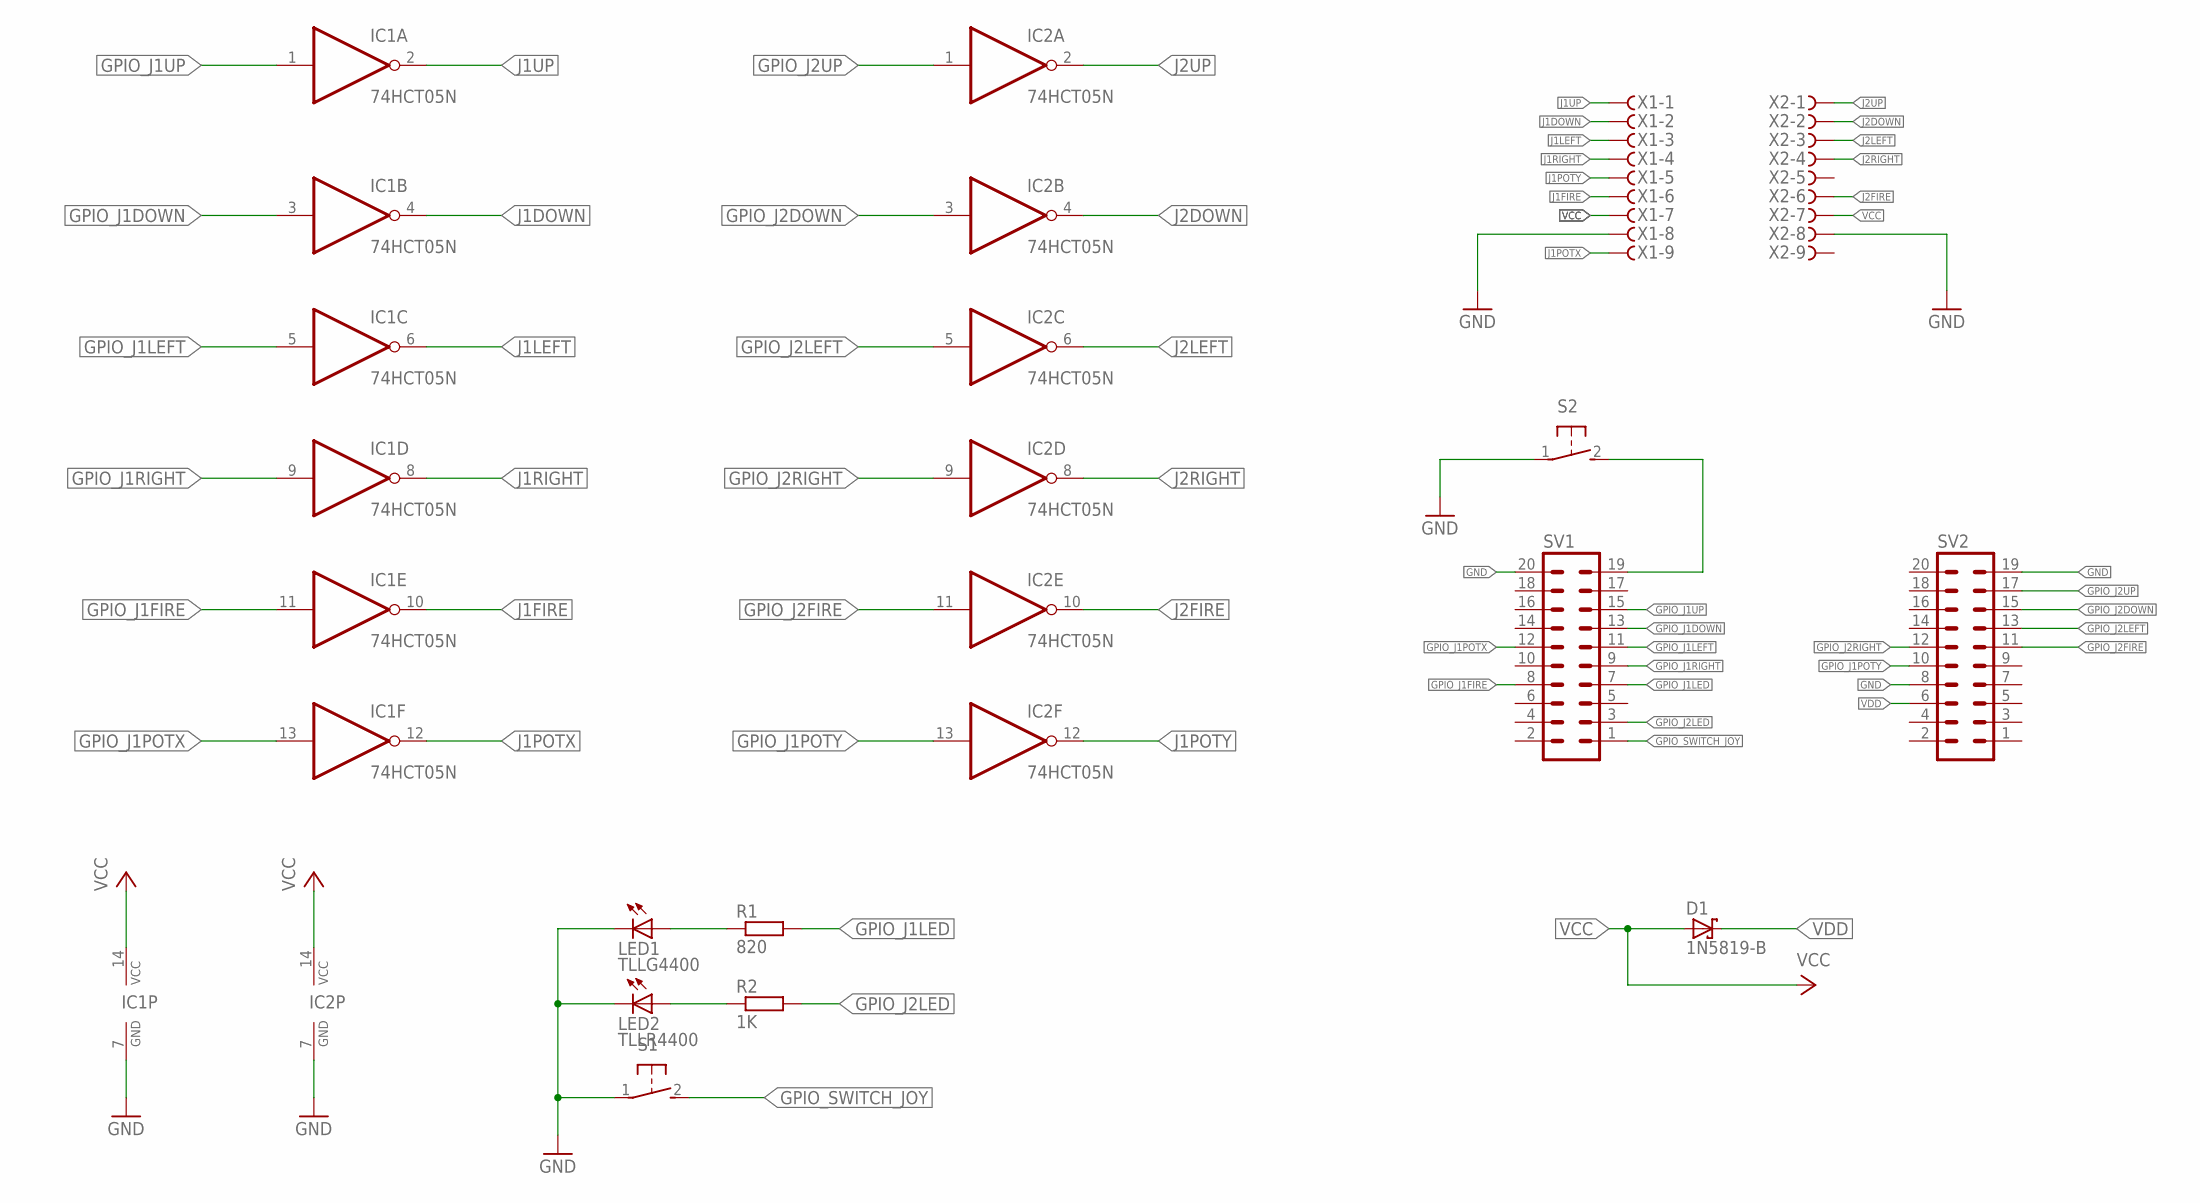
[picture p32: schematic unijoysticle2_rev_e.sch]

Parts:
D1: 1N5819-B; DO41-7.6
IC1, IC2: 74HCT05N; DIL14
LED1: TLLG4400; LED3MM
LED2: TLLR4400; LED3MM
R1: 820; 0309/10
R2: 1K; 0309/10
S1, S2: 31-XX; B3F-31XX
SV1, SV2: MA10-2
X1, X2: F09DS; F09D

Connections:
GND: IC1.7 (GND), IC2.7 (GND), LED1.K (C), LED2.K (C), S1.1, S2.1, SV1.20, SV2.8, SV2.19, X1.8, X2.8
GPIO_J1DOWN: IC1.3 (I), SV1.13
GPIO_J1FIRE: IC1.11 (I), SV1.8
GPIO_J1LED: R1.2, SV1.7
GPIO_J1LEFT: IC1.5 (I), SV1.11
GPIO_J1POTX: IC1.13 (I), SV1.12
GPIO_J1POTY: IC2.13 (I), SV2.10
GPIO_J1RIGHT: IC1.9 (I), SV1.9
GPIO_J1UP: IC1.1 (I), SV1.15
GPIO_J2DOWN: IC2.3 (I), SV2.15
GPIO_J2FIRE: IC2.11 (I), SV2.11
GPIO_J2LED: R2.2, SV1.3
GPIO_J2LEFT: IC2.5 (I), SV2.13
GPIO_J2RIGHT: IC2.9 (I), SV2.12
GPIO_J2UP: IC2.1 (I), SV2.17
GPIO_SWITCH_JOY: S1.2 (S), SV1.1
J1DOWN: IC1.4 (O), X1.2
J1FIRE: IC1.10 (O), X1.6
J1LEFT: IC1.6 (O), X1.3
J1POTX: IC1.12 (O), X1.9
J1POTY: IC2.12 (O), X1.5
J1RIGHT: IC1.8 (O), X1.4
J1UP: IC1.2 (O), X1.1
J2DOWN: IC2.4 (O), X2.2
J2FIRE: IC2.10 (O), X2.6
J2LEFT: IC2.6 (O), X2.3
J2RIGHT: IC2.8 (O), X2.4
J2UP: IC2.2 (O), X2.1
unnamed: LED1.A, R1.1
unnamed: LED2.A, R2.1
unnamed: S2.2 (S), SV1.19
VCC: D1.A, IC1.14 (VCC), IC2.14 (VCC), X1.7, X2.7
VDD: D1.C, SV2.6

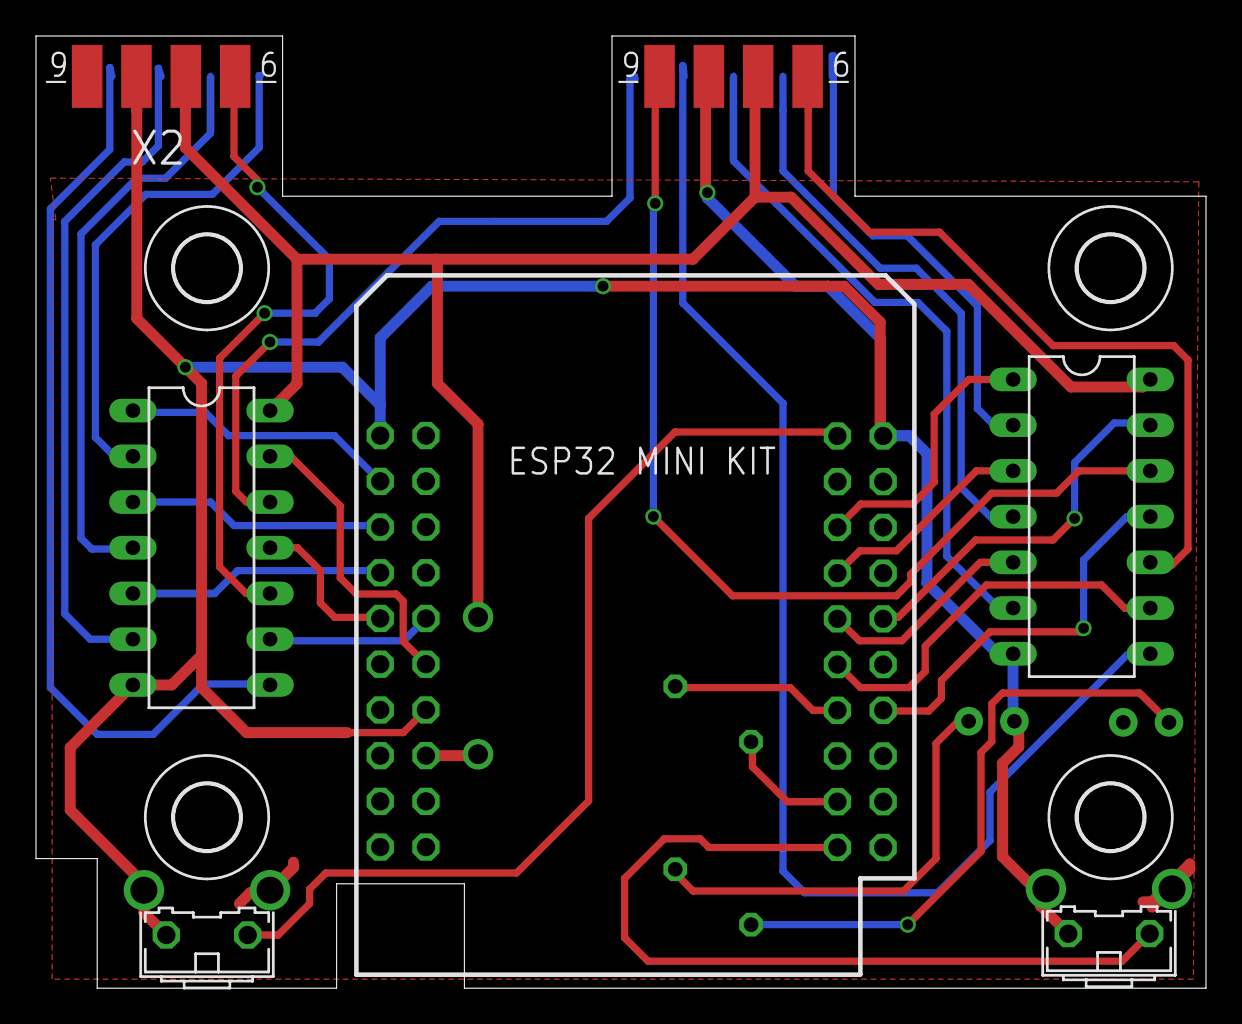
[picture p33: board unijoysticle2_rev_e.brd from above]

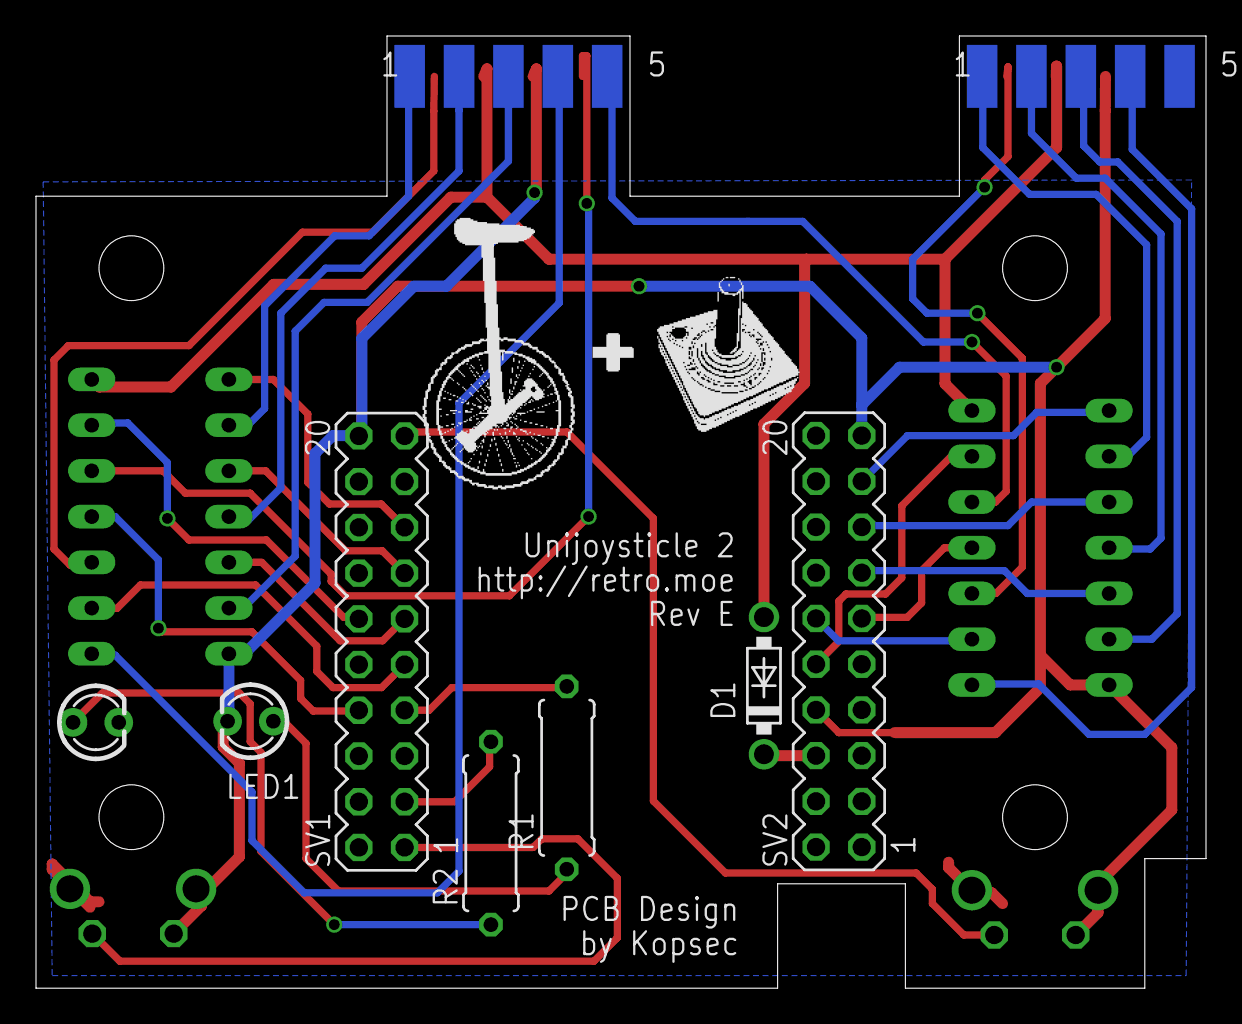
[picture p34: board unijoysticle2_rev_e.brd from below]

Board: 2 copper layers, 65.0 x 52.9 mm, 18 parts (9 on the bottom side), 33 nets.

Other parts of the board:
U$1, U$2, U$3, U$4: 3,6
U$5: OSHW_5MM

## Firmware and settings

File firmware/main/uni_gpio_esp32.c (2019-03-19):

/****************************************************************************
http://retro.moe/unijoysticle

Copyright 2019 Ricardo Quesada

Licensed under the Apache License, Version 2.0 (the "License");
you may not use this file except in compliance with the License.
You may obtain a copy of the License at

    http://www.apache.org/licenses/LICENSE-2.0

Unless required by applicable law or agreed to in writing, software
distributed under the License is distributed on an "AS IS" BASIS,
WITHOUT WARRANTIES OR CONDITIONS OF ANY KIND, either express or implied.
See the License for the specific language governing permissions and
limitations under the License.
****************************************************************************/

// ESP32 version

#include "uni_gpio.h"

#include "freertos/FreeRTOS.h"
#include "freertos/event_groups.h"
#include "freertos/queue.h"

#include "driver/gpio.h"

#include "uni_debug.h"
#include "uni_hid_device.h"

#define ENABLE_POT 0
#define ENABLE_MOUSE 1

// GPIO map for MH-ET Live mini-kit board.
// Same GPIOs as Wemos D1 mini (used in Unijoysticle v0.4)
enum {
  GPIO_JOY_A_UP = GPIO_NUM_26,     // D0
  GPIO_JOY_A_DOWN = GPIO_NUM_22,   // D1
  GPIO_JOY_A_LEFT = GPIO_NUM_21,   // D2
  GPIO_JOY_A_RIGHT = GPIO_NUM_17,  // D3
  GPIO_JOY_A_FIRE = GPIO_NUM_16,   // D4

  GPIO_JOY_B_UP = GPIO_NUM_18,    // D5
  GPIO_JOY_B_DOWN = GPIO_NUM_19,  // D6
  GPIO_JOY_B_LEFT = GPIO_NUM_23,  // D7
  GPIO_JOY_B_RIGHT = GPIO_NUM_5,  // D8
  // GPIO_NUM_3 is assigned to the UART. And although it is possible to
  // rewire the GPIOs for the UART in software, the devkits expects that GPIOS 1 and 3
  // are assigned to UART 0. And I cannot use it.
  // Using GPIO 27 instead, which is the one that is closer to GPIO 3.
  GPIO_JOY_B_FIRE = GPIO_NUM_27,  // RX
};

// GPIO_NUM_12 (input) used as input for Pot in esp32.
// GPIO_NUM_13 (output) used to feed the Pot in the c64
enum {
  EVENT_BIT_MOUSE = (1 << 0),
  EVENT_BIT_POT = (1 << 1),
  EVENT_BIT_BUTTON = (1 << 2),
};

static const int MOUSE_DELAY_BETWEEN_EVENT_US = 12000;  // microseconds
static const int MOUSE_MAX_DELTA = 32;

static gpio_num_t JOY_A_PORTS[] = {GPIO_JOY_A_UP, GPIO_JOY_A_DOWN, GPIO_JOY_A_LEFT, GPIO_JOY_A_RIGHT, GPIO_JOY_A_FIRE};
static gpio_num_t JOY_B_PORTS[] = {GPIO_JOY_B_UP, GPIO_JOY_B_DOWN, GPIO_JOY_B_LEFT, GPIO_JOY_B_RIGHT, GPIO_JOY_B_FIRE};

// Group for different events
static EventGroupHandle_t g_event_group;

// Interrupt handlers
static void handle_event_mouse();
static void handle_event_pot();
static void handle_event_button();

// Mouse related
static void gpio_joy_update_port(joystick_t* joy, gpio_num_t* gpios);
static void send_move(int pin_a, int pin_b, uint32_t delay);
static void move_x(int dir, uint32_t delay);
static void move_y(int dir, uint32_t delay);
static void delay_us(uint32_t delay);

// GPIO Interrupt handlers
static void IRAM_ATTR gpio_isr_handler_button(void* arg);
#if ENABLE_POT
static void IRAM_ATTR gpio_isr_handler_pot(void* arg);
#endif  // ENABLE_POT

static void event_loop(void* arg);

// Mouse "shared data from main task to mouse task.
static int32_t g_delta_x = 0;
static int32_t g_delta_y = 0;

// Pot "shared data from main task to pot task.
static uint8_t g_pot_x = 0;
static uint8_t g_pot_y = 0;

#define MAX(a, b)           \
  ({                        \
    __typeof__(a) _a = (a); \
    __typeof__(b) _b = (b); \
    _a > _b ? _a : _b;      \
  })

#define MIN(a, b)           \
  ({                        \
    __typeof__(a) _a = (a); \
    __typeof__(b) _b = (b); \
    _a < _b ? _a : _b;      \
  })
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

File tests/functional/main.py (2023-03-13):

#!/usr/bin/python3

import RPi.GPIO as GPIO
import sys
import serial
import time

# ESP32 GPIOs
# Valid for Unijoysticle2 A500
uni2_a500_gpios = {
    "j1": {
        "up": 26,
        "down": 18,
        "left": 19,
        "right": 23,
        "fire": 14,
        "pin5": 16,
        "pin9": 33,
    },
    "j2": {
        "up": 27,
        "down": 25,
        "left": 32,
        "right": 17,
        "fire": 13,
        "pin5": 22,
        "pin9": 21,
    },
    "leds": {
        "green": 5,
        "red": 12,
        "blue": 15,
    },
    "push_buttons": {
        "mode": 34,
        "swap": 35,
    },
}

# Valid for Unijoysticle2+
uni2_plus_gpios = {
    "j1": {
        "up": 26,
        "down": 18,
        "left": 19,
        "right": 23,
        "fire": 14,
        "pin5": 16,
        "pin9": 33,
    },
    "j2": {
        "up": 27,
        "down": 25,
        "left": 32,
        "right": 17,
        "fire": 13,
        "pin5": 22,
        "pin9": 21,
    },
    "leds": {
        "green": 5,
        "red": 12,
        # Not Blue LED
    },
    "push_buttons": {
        "mode": 34,
        # No swap button
    },
}


# RPi GPIOs
rpi_gpios = {
    "j1": {
        "up": 21,
        "down": 16,
        "left": 12,
        "right": 1,
        "fire": 20,
        "pin5": 8,  # Fire 3
        "pin9": 7,  # Fire 2
    },
    "j2": {
        "up": 11,
        "down": 24,
        "left": 23,
        "right": 18,
        "fire": 25,
        "pin5": 14,  # Fire 3
        "pin9": 15,  # Fire 2
    },
    "leds": {
        "green": 2,
        "red": 3,
    },
}


def esp32_set_gpio(ser, gpio: int, level: int) -> None:
    s = f"gpio_set {gpio} {level}\r\n"
    ser.write(bytes(s, "utf-8"))
    # Sending the command via Serial + time to for the ESP32 to process it
    # might take a few milliseconds.
    # This "wait" is kind of a "sync"
    time.sleep(0.1)


def esp32_get_gpio(ser, gpio: int) -> int:
    s = f"gpio_get {gpio}\r\n"
    ser.write(bytes(s, "utf-8"))

    # First line is Echo, ignore it
    _ = ser.readline()
    line = ser.readline()

    # Output should have this format:
    #   GPIO 26 = 0
    # Convert it to string, split it by ' ' so we'll have for entries:

    r = line.decode("utf-8")
    r.strip()
    _, number, _, lvl = r.split(" ")
    assert number == gpio
    return lvl


def rpi_setup_gpios():
    GPIO.setmode(GPIO.BCM)

    # LEDs are output
    # J1, J2 are input

    for k in rpi_gpios["leds"]:
        pin = rpi_gpios["leds"][k]
        GPIO.setup(pin, GPIO.OUT)
        GPIO.output(pin, GPIO.LOW)

    for k in rpi_gpios["j1"]:
        pin = rpi_gpios["j1"][k]
        GPIO.setup(pin, GPIO.IN, pull_up_down=GPIO.PUD_UP)

    for k in rpi_gpios["j2"]:
        pin = rpi_gpios["j2"][k]
        GPIO.setup(pin, GPIO.IN, pull_up_down=GPIO.PUD_UP)


def harness_test_leds():
    green_pin = rpi_gpios["leds"]["green"]
    red_pin = rpi_gpios["leds"]["red"]

    print("Testing Green LED...")
    for _ in range(5):
        GPIO.output(green_pin, GPIO.HIGH)
        time.sleep(0.1)
        GPIO.output(green_pin, GPIO.LOW)
        time.sleep(0.1)

    print("Testing RED LED...")
    for _ in range(5):
        GPIO.output(red_pin, GPIO.HIGH)
        time.sleep(0.1)
        GPIO.output(red_pin, GPIO.LOW)
        time.sleep(0.1)


def test_pin(ser, port: str, pin: str) -> None:
    print(f"Testing {port}:{pin}")
    esp32_set_gpio(ser, uni2_a500_gpios[port][pin], 1)
    lvl = GPIO.input(rpi_gpios[port][pin])
    assert lvl == 0

    esp32_set_gpio(ser, uni2_a500_gpios[port][pin], 0)
    lvl = GPIO.input(rpi_gpios[port][pin])
    assert lvl == 1


def test_all_pins_except(ser, port: str, pin: str, level: int) -> None:
    """All must have level, except for port:pin"""
    ports = ["j1", "j2"]
    for port in ports:
        for pin in uni2_a500_gpios[port].keys():
            if pin == pin and port == port:
                continue
            lvl = GPIO.input(rpi_gpios[port][pin])
            assert lvl == level


def test_pin_alone(ser, port: str, pin: str) -> None:
    """Only port:pin must be asserted, the rest should be deasserted"""

    print(f"Testing alone {port}:{pin}")
    esp32_set_gpio(ser, uni2_a500_gpios[port][pin], 1)
    lvl = GPIO.input(rpi_gpios[port][pin])
    assert lvl == 0
    test_all_pins_except(ser, port, pin, 0)

    esp32_set_gpio(ser, uni2_a500_gpios[port][pin], 0)
    lvl = GPIO.input(rpi_gpios[port][pin])
    assert lvl == 1
    test_all_pins_except(ser, port, pin, 0)


def test_led(ser, port: str, pin: str) -> None:
    print(f"Testing {port}:{pin}")
    print("This is a visual test. LED should be blinking")

    for _ in range(5):
        esp32_set_gpio(ser, uni2_a500_gpios[port][pin], 0)
        time.sleep(0.1)
        esp32_set_gpio(ser, uni2_a500_gpios[port][pin], 1)
        time.sleep(0.1)


def test_default_pin_values(ser) -> None:
    """Test default values for pins"""
    print("Testing default values...")
    ports = ["j1", "j2"]
    for port in ports:
        for pin in uni2_a500_gpios[port].keys():
            lvl = GPIO.input(rpi_gpios[port][pin])
            assert lvl == 1


def test_all_pins(ser, lvl: int) -> None:
    """Set level for all pins"""
    print(f"Testing all pins with level {lvl}")
    ports = ["j1", "j2"]
    for port in ports:
        for pin in uni2_a500_gpios[port].keys():
            esp32_set_gpio(ser, uni2_a500_gpios[port][pin], lvl)

    for port in ports:
        for pin in uni2_a500_gpios[port].keys():
            val = GPIO.input(rpi_gpios[port][pin])
            expected = 0 if lvl == 1 else 1
            # print(f"{port}:{pin} = {val} / expected = {expected}")
            assert val == expected


def main():
    ser = serial.Serial(sys.argv[1], 115200, timeout=1)
    print(ser.name)

    rpi_setup_gpios()
    harness_test_leds()

    test_default_pin_values(ser)

    ports = ["j1", "j2"]
    for port in ports:
        for pin in uni2_a500_gpios[port].keys():
            test_pin(ser, port, pin)

    for port in ports:
        for pin in uni2_a500_gpios[port].keys():
            test_pin_alone(ser, port, pin)

    test_all_pins(ser, 1)
    test_all_pins(ser, 0)

    for pin in uni2_a500_gpios["leds"].keys():
        test_led(ser, "leds", pin)

    ser.close()
    GPIO.cleanup()


if __name__ == "__main__":
    exit(main())

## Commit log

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2019-02-09 esp32: code is cleaner
    split functionality in different files... adding "uni_" prefix to
    files and functions to avoid collision with other libraries
    [gpio_joy.c]
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2019-02-12 esp32: ouya. add missing "axis buttons" support
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2019-02-12 esp32: xbox one buttons fixed
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2019-02-13 esp32: some clang-format fixes
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2019-02-13 esp32: ps4 correct log
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2019-02-17 schematic: more fixes
    [unijoysticle.sch]
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2019-02-22 board: using new db9 female to avoid errors.
    [unijoysticle.dsn, unijoysticle.kicad_pcb, unijoysticle.sch]
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2019-02-23 board: autorouting ok. j1 & j2 connected correctly
    [unijoysticle.dsn, unijoysticle.kicad_pcb, unijoysticle.sch]
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2019-03-05 board: traces in correct side of chip to avoid too much routing
    [unijoysticle.dsn, unijoysticle.kicad_pcb, unijoysticle.sch]
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2019-03-07 board: switch for power to prevent 5v in esp32
    and add unijoysticle logo
    [unijoysticle.dsn, unijoysticle.kicad_pcb, unijoysticle.sch]
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2019-03-12 board: LEDs placement fixed
    [unijoysticle.dsn, unijoysticle.kicad_pcb, unijoysticle.sch]
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2019-03-14 board: labels in correct positions.
    this is v0.0.1
    [unijoysticle.kicad_pcb]
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2019-03-16 schematic: misc. ground points down
    genamed gerber to gerber_pcbway (each fab requires different rules)
    [unijoysticle-B_Cu.gbl, unijoysticle-B_Mask.gbs, unijoysticle-B_Paste.gbp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]
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2019-03-29 firmware: support for new mappings (v2)
    board: board slightly bigger, diode smaller, resistrors larger
    [unijoysticle-B_Cu.gbl, unijoysticle-B_Cu.gbr, unijoysticle-B_Mask.gbr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]
2019-03-30 firmware: using GPIOS correctly.
    new GPIOS for a some lines so that it doesn't crash
    [unijoysticle.kicad_pcb, unijoysticle.sch]
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2019-04-06 board: missing BarrelJack
    [unijoysticle.sch]
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2019-04-07 firmware: allow swapping if connected device doesn't have joy assigned
2019-04-09 firmware: shoulder buttons swapped for auto-fire
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2019-05-05 firmware: combo-mode fixes
    Cannot swap ports when combo-mode enabled
    turn on both LEDs when combo-mode enabled
    restore previous joystick_port after leaving combo-mode
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2019-05-24 tool: compiles ok.
    using correct name
    [unijoysticle_test.cfg]
2019-05-30 board: move sparkfun lib inside project
    so 3rd party users can see the schematic without any error
    [unijoysticle.sch]
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2019-07-26 firmware: nintendo wii u pro: mostly working
    buttons, dpad working ok.
    axis needs calibrations, perhaps overwritting EEPROM (?).
    auth hardocded. needs to be fixed
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2019-08-01 firmware: disable auth on nintendo devices
    it seems that it is not needed, at least for the Wii U Pro controller.
    And this breaks on ESP32 (bug either on btstack or esp-idf).
    Works Ok using libuse + btstack howerver.
2019-08-03 firmware: clean up
    trying to understand why it doesn't keep discovering devices
    once a connection is established.
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2019-08-11 doc: supported gamepads include which is the swap button
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2019-08-11 docs: wii remote. smaller
    and fix "button" string
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2019-08-13 firmware: process misc button fix
    fix possible crash when printing too much info in esp32.
    this was caused by printing the "cannot swap joytick" too often.
    also, preparing release v0.4rc0
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2019-09-22 layout / schematic: replaced 7405 model with one with comes with pwr/gnd
    [unijoysticle.kicad_pcb, unijoysticle.sch]
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2019-09-27 board: rev D
    changes DIP switch for slide switch since it supports more amperage
    board a tiny bit wider
    [unijoysticle.dsn, unijoysticle.kicad_pcb, unijoysticle.sch]
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2019-10-01 board: rev. D
    replaces the DIP switch with a slide switch, right angled.
    Allows better amperage, and easier to solder.
    [unijoysticle.dsn, unijoysticle.kicad_pcb, unijoysticle.sch]
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2019-10-14 schematic moved to correct place
2019-11-10 firmware: pass uni_hid_device to parses
    device might contains data about the device being used.
    so pass device instead of gamepad.
    useful for icade, since mappings are slightly different and it doesn't
    make sense to create a new driver for the icade-8bitty
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2019-11-18 firmware: print to console 3-button mode + icade 8-bitty fixes
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2019-12-06 firmware: Nintendo switch: "home" is for swap
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2019-12-31 Add rumble support in Xbox One
    This commit fixes issue #8 by implementing rumble support in Xbox One S.
    8BitDo gamepads (like the SN30) keep rumbling for ever. For the moment
    put them in any mode except "windows mode".
    This commit also adds template code to support LEDs in the remaining
    controllers, which for some reason it is not working.
2019-12-31 disable OUYA LEDs... not working yet
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2020-02-09 doc: names with correct case
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2020-02-22 switch: supports calibration
    works ok both in original and clones.
    but calibration is not working that well... perhaps I'm reading the
    incorrect memory SDI range.
    Perhaps it needs to read 0x8000 instead of 0x6000?
    See: https://github.com/dekuNukem/Nintendo_Switch_Reverse_Engineering/blob/master/spi_flash_notes.md
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2020-02-24 switch: right stick calibration fixed
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2020-02-29 sdkconfig: using esp-idf 4.0
    add CMakefiles (needed for new esp-idf tooling)
    supports for idf.py
    minor fixes in how "home light" is set in nintendo switch
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2020-07-14 firmware: Nintendo Wii uses correct PIN
    Assumes it is connected using Sync. Instead of passing WiiMote remote
    address as PIN, it uses the ESP32 one.
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2020-09-17 board: Rev F
    * Use Schottky diodes
    * Add mounting hole
    * Logo is "locked"
    [unijoysticle.kicad_pcb, unijoysticle.sch]
2020-09-19 board: some layer internal reorder
    Changes done automatically by Kicad... probably after a new version is
    used, some things get reorderd
    [unijoysticle.kicad_pcb]
2020-09-20 ds3 support improved:
    - "stream report" mode fixed. LEDs set-report is sent after "stream
    report".
    - ds3 reorganized a bit
    - Added more documentation in ds3 code
    and other miscs
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2020-10-24 unijoysticle 2 plus: WIP
    testing with different LDO, USB connectors... still very much WIP
    [unijoysticle2plus.sch]
2020-10-24 unijoysticle 2 plus:
    usb micro instead of mini
    connect transistors for auto-prog
    [unijoysticle2plus.sch]
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2021-01-03 Firmware cleanup: remove obsolte files
    Remove Changelog/License related to firmware
    Remove code files from .gitignore
    Ignore fp-info-cache (kicad file)
    Update docs like pair_ds3 which points to Bluepad32
    Regarding Unijoysticle2Plus: non important changes... this is still
    pretty much WIP, so just ignore these changes
    [unijoysticle2plus.kicad_pcb, unijoysticle2plus.sch]
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2021-05-23 contrib: Add Rev H by Kospec C64
    Add Rev H to contrib, Kicad version.
    Includes cap to remove noise
    [unijoysticle2_rev_e.brd, unijoysticle2_rev_e.sch, unijoysticle_rev_h.kicad_pcb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]
2021-06-04 unijoysticle2 plus: using ch340c (WIP)
    After researching which could be the cheapest way to create a board that
    could be assembled by JLCPCB, it seems that using CH340C is the way to
    go:
    - CH340C is an extended part, but doesn't require oscillator. Cost: $0.5
    - CH340G is a basic part, but requires 12Mhz oscillar, which is an
    external part.
    - CP210x, are all external parts and cost > $2
    So, the design will include a CH340C.
    Schematic is "ready", but layout is not.
    [unijoysticle2plus.kicad_pcb, unijoysticle2plus.sch]
2021-06-04 unijoysticle2plus: auto-reset circuit fixed and minor fixes
    Transistor had B/E/C wrong.
    Correct package for push buttons for reset & boot.
    Improved package for 7405 (renamed it from 74lc05 to 74hc05).
    Reset layout. Not working on it yet since schematic is not ready yet
    [unijoysticle2plus.kicad_pcb, unijoysticle2plus.sch]
2021-06-05 unijoysticle2plus: use 0603 packges intead of 0805
    LEDs, resistors and other components (where applicable) use 0603
    packages intead of 0805. Smaller better.
    [unijoysticle2plus.kicad_pcb, unijoysticle2plus.sch]
2021-06-05 unijoysticle2plus: cp2102, add extra 7405 and more
    cp2102:
    JLCPCB has the cp2102 as basic part. Cost wise, it might be a tiny bit
    more expensive, but the footprint is smaller.
    The downsize is that this is the cp2102, and not the recommended
    cp2102N.
    extra 74HC05:
    Added another 74HC05 to connect POT-X, and POT-Y of Joy2. This could be
    useful for Amiga computers, where some games (?) might use a 2nd and 3rd
    buttons (?).
    Add missing caps to ESP32, fixed some values, exposed GPIOs 36 and 39...
    [unijoysticle2plus.kicad_pcb, unijoysticle2plus.sch]
2021-06-05 unijoysticle2plus: fixes in cp2102...
    - connect RST in cp2102
    - Align labels in resistors
    - layout: started basic layout
    [unijoysticle2plus.kicad_pcb, unijoysticle2plus.sch]
2021-06-06 unijoysticle2plus: add missing caps
    Add .1uF close to the 7405
    Add 220uF close to ESP32
    [unijoysticle2plus.kicad_pcb, unijoysticle2plus.sch]
2021-06-06 unijoysticle2plus: missing caps and other stuff
    - Add missing cap in cp2102
    - Replace the 3 ESD diodes with just one package that contains 3 diodes
    - Add LED that indicates Power On
    - Layout: improved layout a bit... still this is very much WIP
    [unijoysticle2plus.kicad_pcb, unijoysticle2plus.sch]
2021-06-09 Unijoysticle2+ rev A:
    - Remove barrel jack:
    Since we control USB, the USB port can be used as the "external" power
    supply
    - Since the barrel jack was removed, also the switch that connects the
    c64 power lines with the external power supply was also removed.
    So, it is not possible to prevent the C64 from powering the ESP32.
    - Added a 470uF cap to reduce noise
    - Power led
    - Routing
    - Unijoysticle logo
    - Rounded corners
    TODO: Add reference to the components to be used in JLCPCB... and
    perhaps fix the labels a bit
    [unijoysticle2plus.kicad_pcb, unijoysticle2plus.sch]
2021-06-10 Unijoysticle2plus: JLCPCB references and more
    - Added "LCSC" reference to components, so that it can generate the BOM
    for JLCPCB
    - Added plugin to generate BOM for JLCPCB
    - Board: using THT push button instead of SMD. This one is more "case"
    friendly.
    - Unijoysticle logo is in the back. In the front is the open source one.
    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
    [unijoysticle2plus.csv, unijoysticle2plus.kicad_pcb, unijoysticle2plus.sch]
2021-06-11 unijosyticle2plus: add missing caps
    Add missing caps in ESP32 EN / 3V3 lines.
    Add missing cap in reset button
    Add 0 ohm in reset button
    [unijoysticle2plus.kicad_pcb, unijoysticle2plus.sch]
2021-06-14 unijoysticle2plus: REV A finished
    - Includes footprint for USB Micro B
    - Uses different ESD USB component, one that is available in JLCPCB
    - Layout of CP2102 + ESD is a bit different
    [unijoysticle2plus.csv, unijoysticle2plus.kicad_pcb, unijoysticle2plus.sch]
2021-06-15 unijoysticle2plus: schematic cosmetic fixes
    cosmetic fixes to make it more readable.
    [unijoysticle2plus.kicad_pcb, unijoysticle2plus.sch]
2021-06-23 Unijoysticle2+ - Rev B: WIP
    * 4 layer board
    * hand-solder friendly
    * Uses CH340C instead of CP2102
    * Fixes placement of USB micro connector
    [unijoysticle2plus.kicad_pcb, unijoysticle2plus.sch]
2021-06-23 unijoysticle2+: rev b. JLCPCB fixes
    Add LCSC reference to new components
    Update LCSC reference of old components to use 0805
    Power plane in layer is split in 3: VCC (C64 5+), 3v3+ and VBUS
    [unijoysticle2plus.csv, unijoysticle2plus.kicad_pcb, unijoysticle2plus.sch]
2021-06-26 Unijoysticle2+: Rev C. WIP
    Although I haven't tested yet Rev B., there a few changes that I wanted
    to make to it.
    Rev. C, so far, has the following changes:
    - Switch Power plane with Ground place: Ground plane is #2 and Power
    plane #3.
    - Manually routed: No longer uses auto-route. I think it is better for
    debugging to route it manually. More vias. Vias placed closer to the
    pads. Might reduce inductance (?).
    - No longer using the ESD protector for USB. Almost nobody uses it,
    besides that CP2104 recommends it. But I'm no longer using CP2104, and
    CH340 doesn't mention it... I think it would be a good idea
    nonetheless, but only as an optional feature.
    - Differential pair routing for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
    [unijoysticle2plus.kicad_pcb, unijoysticle2plus.sch]
2021-07-07 unijoysticle2plus: no idea
    Unfortunately I have no idea what these changes are.
    I would guess it is "safe" to commit them.
    [unijoysticle2plus.kicad_pcb, unijoysticle2plus.sch]
2021-07-07 unijoysticle2+: rev C WIP
    - 5819 package: using SMA instead of SOD-123:
    - I thought the diode was fauly or something... so I dediced to
    change for another one. But I think the bug is somewhere else.
    In any case, using the new part (with different package)
    - CH340C: powered using v3.3 instead of v5.
    - ESP EN should be high (v3.3) or low (0), but if CH340 is powered
    using v5, then DTR might have ~4V... instead of v3.3
    - Using one MUN5214D insetad of two S8050 + resistors
    - less space, less routing, cheaper... although might not be as easy
    to solder as the S8050
    - Using only one power place: removed VBUS and C64-5V power planes.
    - The only power plane is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
    [unijoysticle2plus.kicad_pcb, unijoysticle2plus.sch]
2021-07-07 unijoysticle2plus: boot button and more
    - Remove power plane. Plane #2 and #3 are GND planes now
    - Add Boot button, easier to debug should we need it
    - New USB Micro B package + footprint
    - Renamed VDD with +5V
    - Added PWR_FLAG for +5v to prevent warnings
    [unijoysticle2plus.kicad_pcb, unijoysticle2plus.sch]
2021-07-07 unijoysticle2plus: rev C
    Rev C submitted to JLCPCB.
    Added missing JLCPCB parts
    [unijoysticle2plus.kicad_pcb, unijoysticle2plus.sch]
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2021-07-25 Unijoysticle2+: Rev D
    - Swap GPIO 12 & 13: issue #19
    - Ground GPIO 4. This is to detect Uni2+
    - Back to USB Micro B connector used in Rev. B
    - This is to avoid hand-soldering it.
    - Re-added the "hole" in PCB so that it can be placed using P&P
    machine.
    - Reduced Green LED resistor from 1k to 330, this is to make it
    brighter.
    - Auto reset circuit wasn't working on Rev C.
    Replaced it with original design, using S8050s.
    Fixed the pins, was broken in Rev A and Rev B.
    [unijoysticle2plus.kicad_pcb, unijoysticle2plus.sch]
2021-07-25 unijoysticle2+: place 1000uF cap differently
    - Change footprint of 1000uF: bigger
    - Place it slightly differently
    [unijoysticle2plus.kicad_pcb, unijoysticle2plus.sch]
2021-07-25 Unijosyticle2+: ESP32-WROOM-32E Out-of-Stock, using D
    JLCPCB doesn't have WROOM-32E in stock.
    Switching back to 32D
    [unijoysticle2plus.sch]
2021-08-08 Unijoysticle2+: Rev E
    - Auto-reset circuit fixed: Transitor lines connected correctly
    - Filter cap is between 5v and GND (and not +3.v3 and GND)
    - Using 1.5K Ohm resistors for blue and red LEDs instead of 1K
    - USB connector is just a tiny bit moved inwards
    [unijoysticle2plus.kicad_pcb, unijoysticle2plus.sch]
2021-08-08 Unijoysticle2+: Using CH340B instead of CH340C
    CH340C is out of stock in JLCPCB. Using CH340B which is pin-compatible.
    [unijoysticle2plus.kicad_pcb, unijoysticle2plus.sch]
2021-10-04 Unijoysticle 2+: use 10uF cap for C4
    Instead of using .1uF cap for C4, it is replaced with a 10uF.
    This fixes the autoboot issues.
    Yay!
    [unijoysticle2plus.kicad_pcb, unijoysticle2plus.sch]
2021-10-06 Unijoysticle2+: add text in schematic about ch340 and ESP32
    Either CH340B or CH340C can be used.
    And any ESP32-WROOM-32 can be used: 32, 32D or 32E (not the "U" variant
    of course)
    Add "JLCJLCJLCJLC" in silk screen to place the order number there.
    [unijoysticle2plus.kicad_pcb, unijoysticle2plus.sch]
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2021-10-09 doc: schematic / user guide / solder kit
    Major documentation update:
    * Added PDF schematic for v2+
    * "Soldering guide" moved to its own file (out from the user guide)
    * This is no longer neede for v2+
    * User guide: added many photos for v2+
    * User guide: added comparison between v2 and v2+
    * User guide: Improved grammar in other parts
    * User guide: Improved v2 photos as well
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2021-12-13 contrib: Add Unijoysticle2 for NeoGeo
    This commit adds:
    * Unijoysticle2 adapter for NeoGeo
    * Unijoysticle2 for NeoGeo
    This is a contribution from Hyvax (from Discord server).
    Includes schematic, layout, pinout, images, doc, and the "patch" for
    Bluepad32.
    [neogeo-unijoysticle2-adapter.brd, neogeo-unijoysticle2-adapter.sch, neogeo-unijoysticle2.brd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]
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2022-01-01 unijoysticle 2+: use better USB micro B connector
    The one used in Rev F works Ok when the Fab house solder it correctly.
    But it might be possible that it might not work. At least I found 1 / 20
    that was not working due to a bad solder/alignment (?) in one of the
    boards.
    So, I'm switching to one that has some holes so the alignment should not
    fail. It might required some extra manual solder... but we shall see.
    Also, I slightly improved the routing traces between the USB D- / D+
    with the CH340 chip.
    Also, I'm using 1.5K resitor for Green LED as well.
    The previous LED that was used in Rev F is no longer available and the
    2nd batch came with a more potent one. So I need to increase the
    resis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
    [unijoysticle2plus.kicad_pcb, unijoysticle2plus.sch]
2022-01-01 unijoysticle 2+: Update LSCS parts
    Use a different 1n5819 diode. Old one is out of stock.
    Default to ESP-WROOM-32E (instead of ESP-WRROM-32).
    [unijoysticle2plus.sch]
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2022-01-02 unijoysticle2+: kicad 6 migration
    Migrates Unijoysticle 2+ Kicad 5 files to Kicad 6
    In the process, it bumps version to Rev. H.
    The schematic is the "same": just minor cosmetic changes were done only
    to make ERC happy.
    Similar on the PCB: it is the same, but NET-R5-PAD2 and NET-R6-PAD2 were
    re-routed again since "Tools -> Clean up vias and tracks" removed it.
    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
    [unijoysticle2plus.kicad_pcb, unijoysticle2plus.kicad_sch]
2022-01-02 unijoysticle 2+: add some "rounding" to tracks
    Using Kicad 6's "Track fillet" feature, adding to some of the tracks
    rounding corners.
    [unijoysticle2plus.kicad_pcb]
2022-01-03 unijosyticle 2+: remove kicad 5 files
    Remove project and schematic files from Kicad 5.
    The PCB file uses the same name as in Kicas 5, but internally is totally
    different.
    [unijoysticle2plus.sch]
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2022-02-08 doc: sellilng devices with br
    gitlab doesn't like </br>
    replacing it with <br>.
    Hopefully it renders as expected
2022-02-08 doc: fix wording in selling devices doc
2022-02-27 doc: fix typo in README
    [unijoysticle2plus.kicad_pcb]
2022-04-20 Unijoysticle 2+ for A500: WIP
    Initial commit.
    This is just a copy of the Unijoysticle 2+ with some changes like:
    - using hierachy sheets
    - since I'm running out of ouput GPIOs, need to swap one
    - Added LED for BT
    - Added extra user switch
    - GPIO 36 used as strapping pin
    [amiga_ports.kicad_sch, esp32.kicad_sch, unijoysticle2plus_a500.kicad_pcb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]
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2022-04-21 uni2+ a500: schematic "ready"
    The schematic should be "ready".
    Layout WIP. Components were placed in "place".
    But routing is missing, as well as logos
    [amiga_ports.kicad_sch, esp32.kicad_sch, unijoysticle2plus_a500.kicad_pcb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]
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2022-04-23 a500: fix most of the warnings in the PCB
    [unijoysticle2plus_a500.kicad_pcb]
2022-04-24 Uni 2+ A500: many little changes
    - replace resistor 0 with solder jumper for strapping pins
    - move big cap a big down
    - improved routing
    - move vias outside pads
    ... and more
    [amiga_ports.kicad_sch, esp32.kicad_sch, unijoysticle2plus_a500.kicad_pcb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]
2022-04-24 A500: Reuse GPIO 15 both as LED and BoardId
    Cannot use GPIOs 34~39 for Board ID since in previous models those leds
    were floating and those GPIOs don't have pull-up/pull-down resistors.
    To GPIO 15 is reused for board id and LEDs.
    GPIO 36 and 39 and grounded for future-compatibility.
    FIXME:Push buttons won't work. They require a pull-up/pull-down
    resistor.
    [amiga_ports.kicad_sch, esp32.kicad_sch, unijoysticle2plus_a500.kicad_pcb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]
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2022-04-27 uni2 a500: vias closer to pads
    And also improved routing of some of the wires... shorter path
    [unijoysticle2_a500.kicad_pcb]
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2022-04-28 uni a500: add no-connect to 74HC05 pin
    In the schematic, add the no-connect to the pins that are not used.
    Fixes some warnings
    [amiga_ports.kicad_sch, unijoysticle2_a500.kicad_pcb, unijoysticle2_a500.kicad_sch]
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2022-05-27 uni2 a500: revert CH340 from 5V
    Autoreset is driven by DTS/RTS.
    But if DTS/RTS are not used (requires that CH340 is powered) then
    autoreset doesn't work.
    So, although we shouldn't power CH340 when it is powered from the Amiga,
    since it consumes current, we need it for autoreset.
    Besides, we don't gain much by not powering CH340. Only 0.02 amps
    according to my measures.
    [amiga_ports.kicad_sch, esp32.kicad_sch, unijoysticle2_a500.kicad_pcb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]
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2022-05-31 uni2 a500: plot values as well
    Needed "SWAP", "MODE" and "RESET"
    [unijoysticle2_a500.kicad_pcb]
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2023-06-18 Unijoysticle2 800X/A1000: fix warnings
    [unijoysticle2_xl800.kicad_pcb, unijoysticle2_xl800.kicad_sch]
2023-06-18 missing files for Atari 800XL / Amiga 1000
    [unijoysticle2_xl800.kicad_pcb]
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2023-06-29 Atari 800XL: more fixes in silkscreen
    [unijoysticle2_xl800.kicad_pcb]
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

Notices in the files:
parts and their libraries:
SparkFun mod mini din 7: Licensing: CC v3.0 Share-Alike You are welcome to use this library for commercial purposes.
